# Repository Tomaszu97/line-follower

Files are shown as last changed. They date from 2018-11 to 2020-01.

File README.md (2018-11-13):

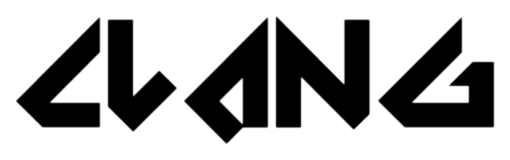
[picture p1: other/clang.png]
  
A simple line follower project of mine.
Consists of:
 * ATmega 328P  
 * L298 dual H-bridge  
 * 6x QRE1113GR optotransistors  
 * 2x pololu clone 12V 1200RPM motors  
 * step down 5V converter  
 * 7,4V Li-Ion battery  
 * couple resistors, LEDs and other passive components  

Programmed in Arduino.  
Uses PID loop and a simple algorithm to find center of line (using weighed average).  
Follows black line on white background.  

Video of device test  
IMAGE ALT TEXT HERE (https://www.youtube.com/watch?v=-RvJ9BSbzys) 

Before mounting DC motors:  
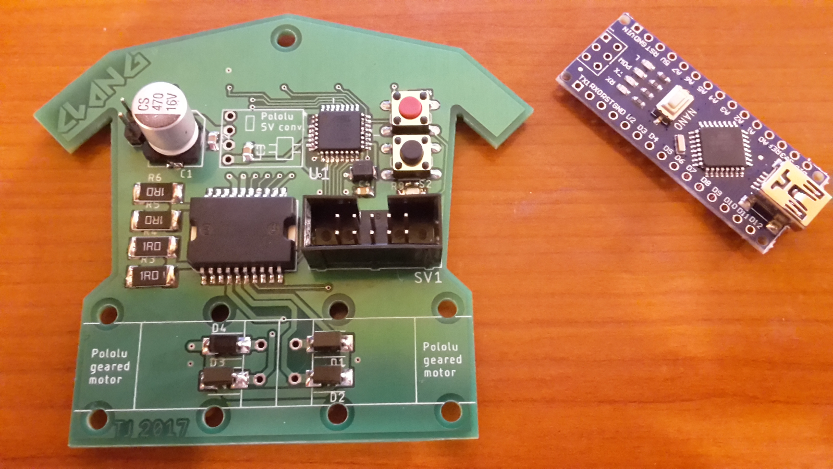
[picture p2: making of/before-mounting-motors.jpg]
  
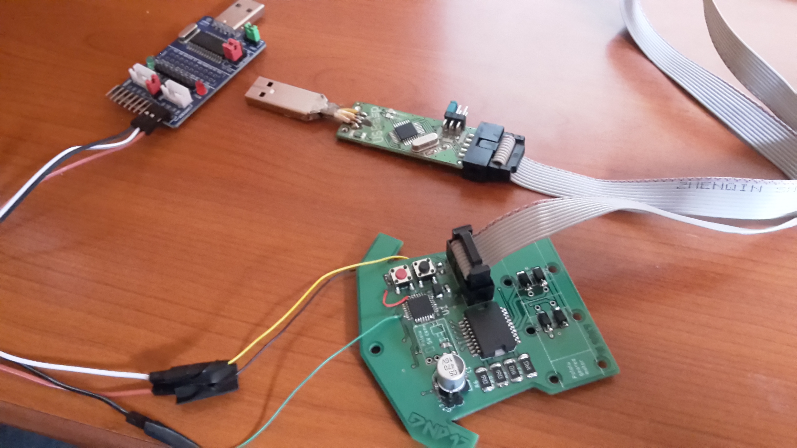
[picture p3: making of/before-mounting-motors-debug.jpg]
  

Finding voltage/speed characteristic using optical speed measurement:  
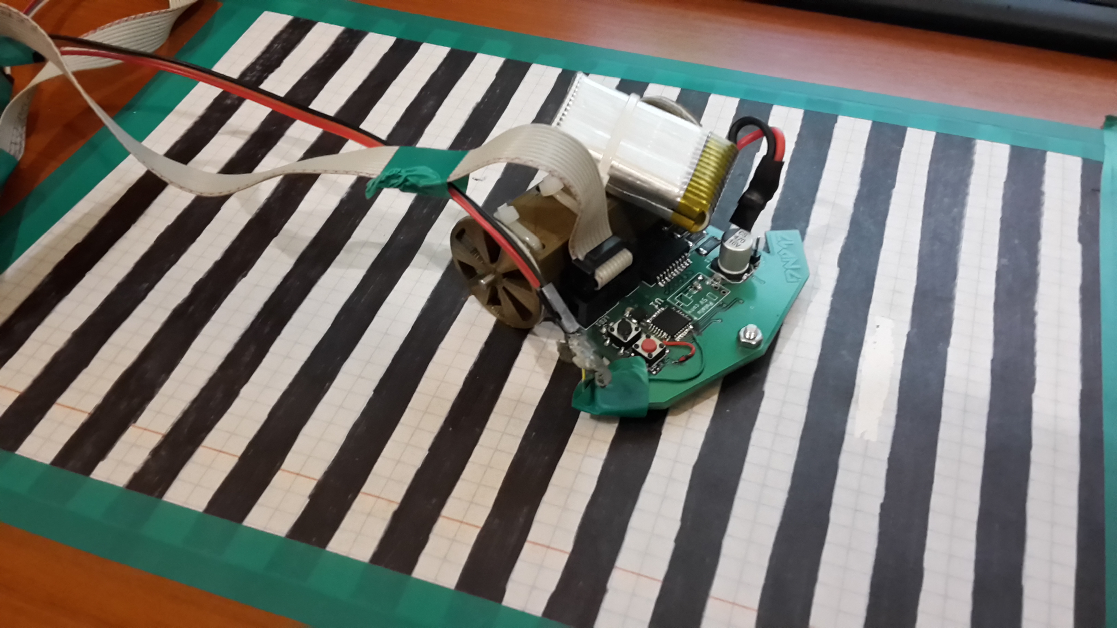
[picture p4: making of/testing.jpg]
  
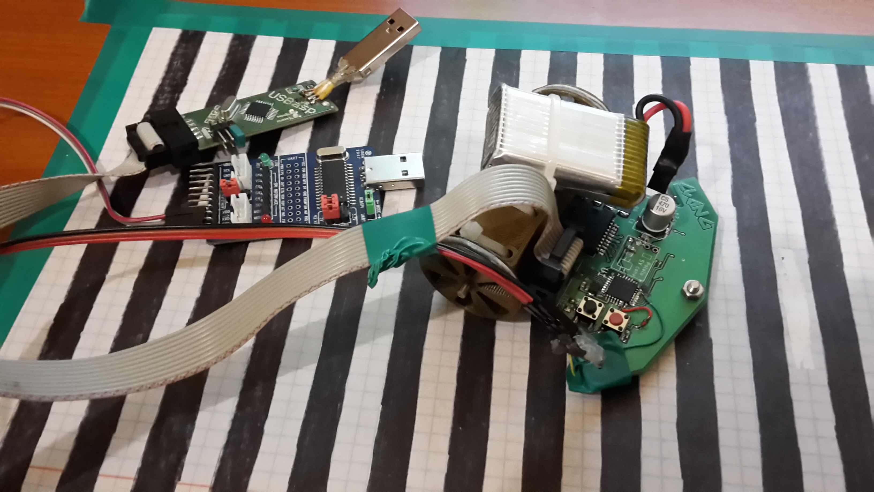
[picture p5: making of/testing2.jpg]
  
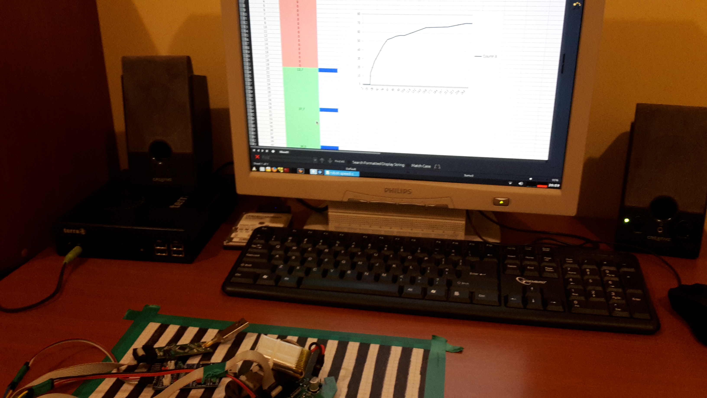
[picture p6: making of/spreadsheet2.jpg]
  
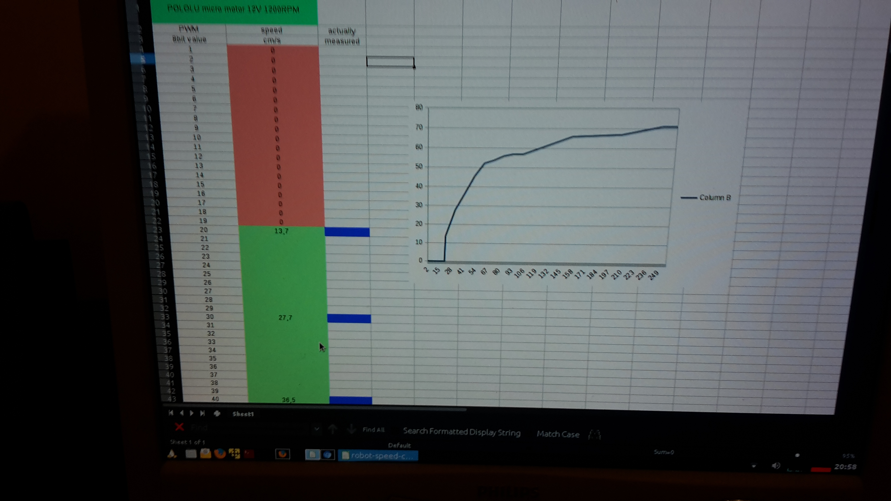
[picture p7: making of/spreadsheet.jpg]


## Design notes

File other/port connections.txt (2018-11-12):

PHOTOTRANSISTOR:
1	-	PC5	(ADC5)
2	-	PC4	(ADC4)
3	-	PC3	(ADC3)
4	-	PC2	(ADC2)
5	-	PC1	(ADC1)
6	-	PC0	(ADC0)

MOTORS:
input 1		-	PD7
input 2		-	PB0
input 3		-	PB1	
input 4		-	PB2
enable A	-	PD6
enable B	-	PD5

OTHER:
LED				-	PD0	(TXD)
BLACK BUTTON	-  	PD1	(RXD)

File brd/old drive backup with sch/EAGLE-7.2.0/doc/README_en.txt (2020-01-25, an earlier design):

==============================================

  E A G L E - L A Y O U T - S O F T W A R E
       Information about Version 7.2.0

==============================================

Updating from older versions
----------------------------

IMPORTANT: If you are updating from an older version of EAGLE, please make
*********  sure you read the file doc\UPDATE entirely before working
           with this new version!

Manual + Tutorial
-----------------

The EAGLE manual and tutorial in PDF format can be found in the "doc"
subdirectory. Please make sure you read at least the tutorial before
beginning to work with EAGLE.

Supported Operating Systems
---------------------------

  - Windows XP, Windows Vista, Windows 7 or Windows 8.

Running the CAM Processor in batch mode
---------------------------------------

Since Windows programs give up their connection to the console they
have been started from, you can use the file 'eaglecon.exe' (located
in the 'bin' subdirectory) if you want to run the CAM Processor from
a batch file. This version of EAGLE is exactly the same as the 'eagle.exe',
except that it doesn't disconnect from the console. Type 'eaglecon -?'
for a list of CAM Processor options.

Printing on custom paper sizes
------------------------------

Printing on custom paper sizes may not work, especially when switching
printers in the print dialog.

Octagon apertures in Gerber RS-274X format
------------------------------------------

The various Gerber viewers on the market have different ideas about how to
display octagon apertures in RS-274X format. There are all kinds of
interpretations of the diameter and rotation.
When generating octagon apertures in RS-274X format, EAGLE assumes that the
viewer will interpret the diameter as the distance between two opposite
corners, and that it has to be rotated by 22.5 degrees to achieve the
proper alignment. In case your specific viewer interprets these data
differently you can adjust this to your viewer's special needs in the file
'eagle.def'.

IMPORTANT: Before sending data in RS-274X format to your board house you
should make sure you ask them how *their* software will interpret octagon
data.

Printing fill patterns
----------------------

Printing fill patterns doesn't work with Postscript files.
If you want to print fill patterns, create a PDF file and then
print that file.

Electrical Schematics
---------------------

This EAGLE version is suited for drawing schematics and generating other
documentation for electrical projects, according to the European standard.
The descriptions of the specific libraries and user language programs,
as well as the tutorial covering this topic, are written in German.
At present, there are no plans to offer these features for the English-
speaking market. Feel free to use them, but there will be no support
in English.

Language
--------

EAGLE uses the same language as the operating system it is running on
(provided the necessary language specific text files are available).
To override this, you can set the environment variable LANG to the
desired value, as in

  SET LANG=de_DE     (under Windows)

before starting EAGLE.

                         ===================
========================= SALES INFORMATION ===============================
                         ===================

EAGLE is a program of CadSoft Computer GmbH.

CadSoft can be contacted in the USA at:
                         CadSoft Computer
                         19620 Pines Blvd. Suite 217
                         Pembroke Pines, FL 33029
                         Phone:  954-237-0932
                         Fax:    954-237-0968
                         E-Mail: info@cadsoftusa.com
                         Web:    http://www.cadsoftusa.com

EAGLE is available for Linux, Mac OS X and Windows platforms.

CadSoft Computer is a trading division of Newark Corporation, a Premier
Farnell company.
Learn more at http://www.cadsoftusa.com/pf.

===========================================================================
"Linux" is a registered trademark of Linus Torvalds.
"Mac", "Mac OS" and "Apple" are registered trademarks of Apple Computer, Inc.
"Windows" is a registered trademark of Microsoft Corporation.
===========================================================================

Copyright (c) 2014 CadSoft Computer - All rights reserved

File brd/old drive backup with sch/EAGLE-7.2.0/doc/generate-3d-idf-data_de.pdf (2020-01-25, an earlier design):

Seite 1 von 3

Ing. Neubacher Andreas
Entwicklung / Development

COMMEND INTERNATIONAL GMBH A-5020 Salzburg, Saalachstraße 51 Tel: +43-662-85 62 25
Fax: +43-662-43 18 22
<mailto: a.neubacher@commend.com> <http://www.commend.com>

Global Intercom by Commend

### Einpflegen 3D-Daten der Bauteile in Eagle-Bauteilbibliothek zur Weiterverarbeitung in 3D-MCAD Systemen

Um in die mechanische Konstruktion auch die Leiterplatte mit der Platinenkontur und den darauf platzierten Bauteilen einbinden zu können, müssen einige Punkte beim Erstellen eines neuen Bauteils berücksichtigt werden.

Techn. Hintergrund :

Um mechanische Abmessungen der Bauteile, Platine, … aus dem ECAD-System in ein MCAD-System zu portieren wurde 1989 ein Standard (IDF – Intermediate Data Format V1.0) von SDRC und Mentor definiert. Dieses Intermediate Data Format (IDF) wurde mit der Zeit überarbeitet/erweitert und besitzt derzeit den Letztstand V4.0. Die Generierung der IDF-Files wird derzeit von allen professionellen ECAD-Systemen (Mentor, Zuken, Target, PADS, PCAD, …) unterstützt.

Meilensteine des IDF-Standard :

- V1.0 : | # Board/Print-Outline, einfache Bauteilpositionierung
- V2.0 : | # Aufteilung der Daten in eine Bauteilbibliothek (.IDL) und ein Boardfile (.IDB) # Aufteilung aller elektromechanischen Daten in elektrische und mechanische Sektionen # Bauteildaten beinhalten nun 3D Informationen (nur 1 Höheninformation) # Placement-, Keepout-, …, Holessections
- V3.0 : | # Panelfile zur Erstellung eines bestückten Nutzen # div. Verbesserungen, …
- V4.0 : | # Bauteile können detailliert dargestellt werden (verschiedene Höheninfos, …) # Leiterbahnzüge, Freiformen, … können abgebildet werden

Standards zu finden unter : \\Eacoco\Projekte\_CAD_EAGLE\DOKU_eagle\

Solidworks 2006 SPx unterstützt derzeit nur den IDF-Standard Version 3.0. Dh alle Bauteile sind beschränkt auf 1 Höheninformation mit 1 geschlossenen Aussenkontur. Für eine genaue Konstruktion sind die Bauteildaten mit nur 1 Kontur und der maximalen Höhe vollkommen ausreichend.

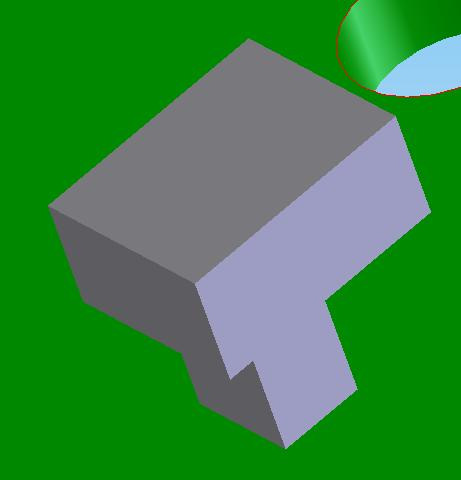
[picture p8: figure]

Seite 2 von 3

Erstellung der Eagle-Libary :

1) Bauteile :
- Ein Bauteil kann aus beliebig vielen Höheninformationen zusammengesetzt werden. Die verschiedenen Segmenthöhen können nur Pyramidenförmig aufgebaut werden. Dh: eine auf der Spitze stehende Pyramide kann nicht dargestellt werden.
Bsp: | möglich | nicht möglich

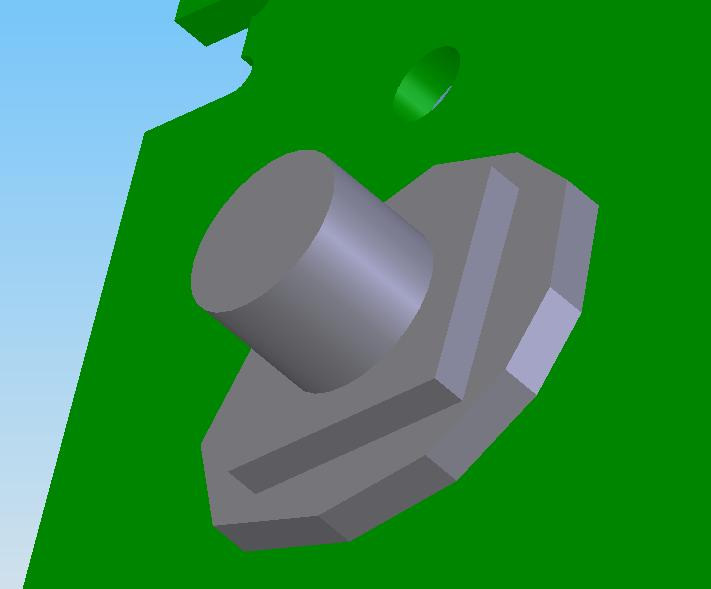
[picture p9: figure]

Graphik 1a | Graphik 1b
- Eine geschlossene Kontur jeder einzelnen Höheninfo ist UNBEDINGT notwendig um anschliessend diese extrudieren zu können
- Bauteilaussenkontur (R, L, C, IC, …) wird in der Bibliothek auf Layer 57 (tCAD) und Layer 58 (bCAD) angelegt

Layer 57 : Draufsicht auf das jeweilige Bauteil (standard)
Layer 58 : ragt durch die Platine ein Teil des Bauteils durch (mech. Befestigung o.Ä) wird dies im Layer58 eingetragen

Alle Bauteilhöhen werden normalerweise ausschliesslich auf Layer57 gezeichnet. Wenige Ausnahmen sind Stecker mit mech. Befestigung, Schrauben, Lötbeine bei bedrahteten Bauteilen, … die durch den Print ragen und auf der Bottom-Seite überstehen.

- Strichstärke der Kontur entspricht der Bauteilhöhe :
Bauteilhöhe Strichstärke = Bauteilhöhe [mm] / 1000 | (1mm = 1000mic)
(Bsp : Bauteilhöhe 12.6mm wird als Strichstärke | 12.6mic gezeichnet)

Notwendige Ausfräsungen, Löcher des Bauteils Strichstärke = 0.0 [mic]

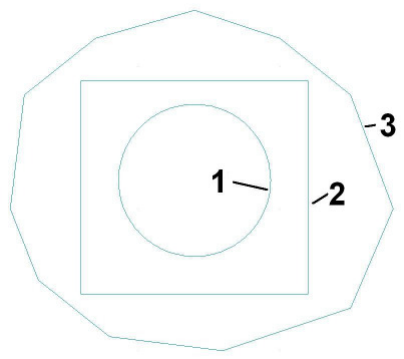
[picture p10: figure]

Bsp:

1) Strichstärke 8mic = Zylinder 8mm hoch
2) Strichstärke 3mic = Rechteck 3mm hoch
3) Strichstärke 1.6mic = Polygon 1.6mm

--> Ergebnis siehe Graphik 1a

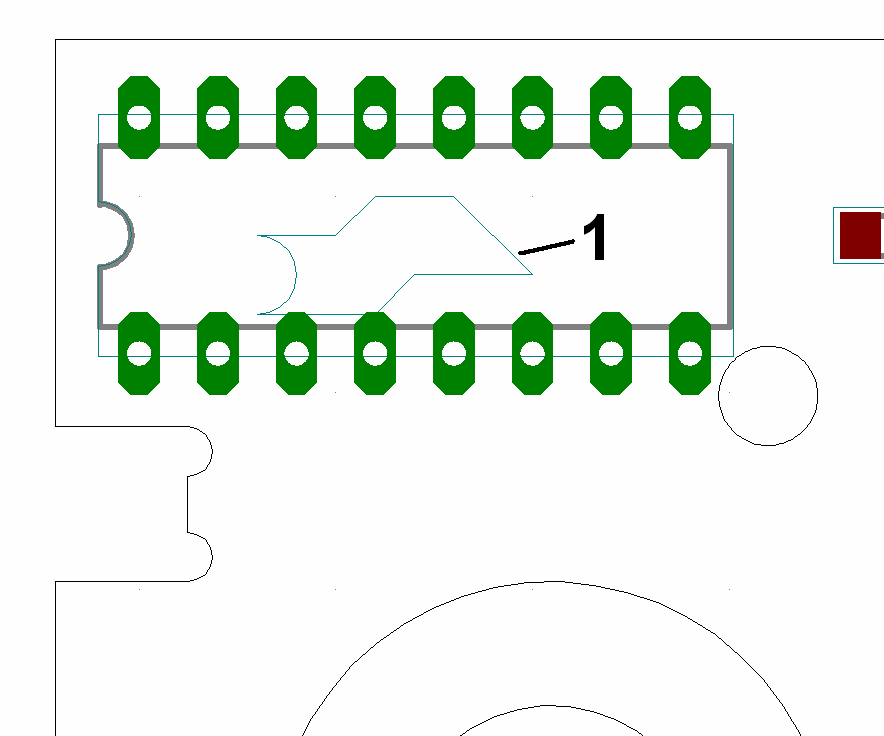
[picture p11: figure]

Seite 3 von 3

- Bohrungen/Holes müssen nicht gesondert behandelt werden -> werden automatisch erkannt und in die Leiterplatte übernommen
Bsp : | 1) | Stecker-Baueilhöhe 3.7mm -> Strichstärke = 3.7 [mic] Stecker-Ausfräsung für mech. Befestigung : Polygon mit 0.0 [mic] Stecker-Loch als Positionierungshilfe : Hole mit Durchmesser 2.1 [mm]
2) Ausfräsung unter IC (siehe Graphik 2c (1) )
Top-3D | Bottom-3D | Eagle-Bibliothek

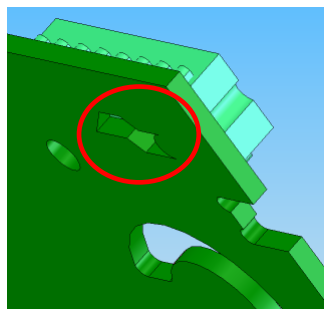
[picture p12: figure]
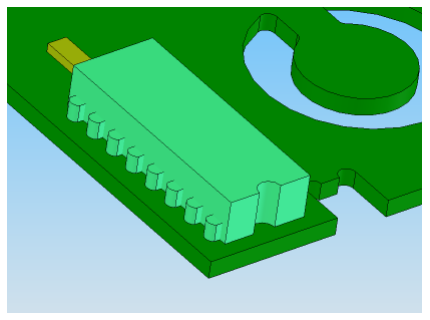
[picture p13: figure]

Graphik 2a | Graphik 2b | Graphik2c
2) Leere Leitplatte :
- Kontur der leeren Leiterplatte auf Layer 50
- Eine geschlossene Kontur ist UNBEDINGT notwendig um anschliessend diese extrudieren zu können
- Strichstärke der Aussenkontur entspricht der Leiterplattenhöhe

Platinenhöhe Strichstärke = Bauteilhöhe [mm] / 1000 (1mm = 1000mic) Notwendige Ausfräsungen, Löcher des Platine Strichstärke = 0.0 [mic]

Bsp : Strichstärke Leiterplatte Aussenkontur = 1.6 [mic], Printausfräsungen = 0.0 [mic]

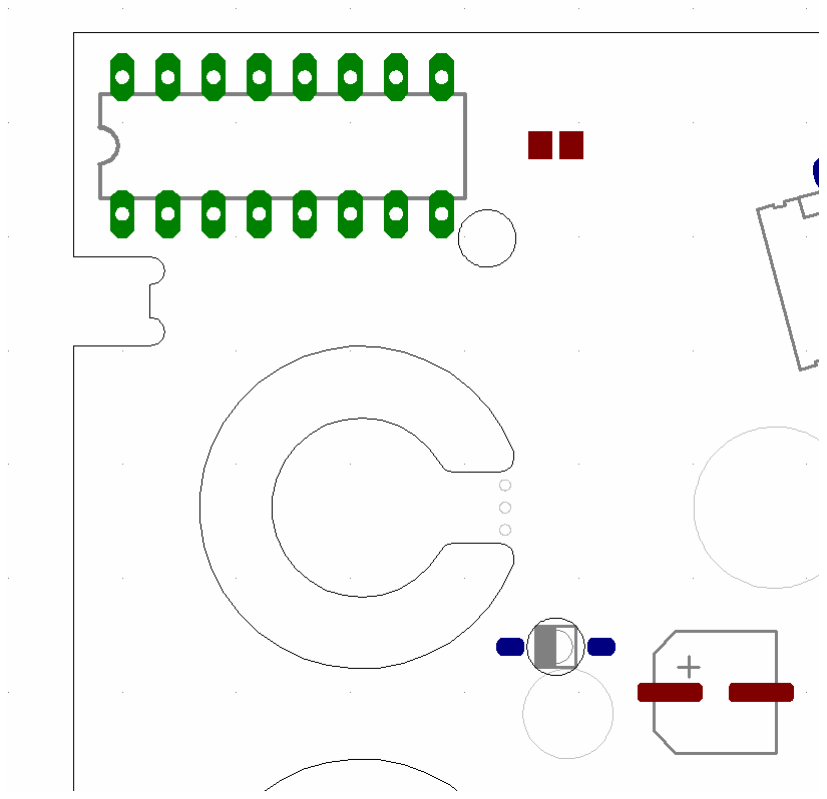
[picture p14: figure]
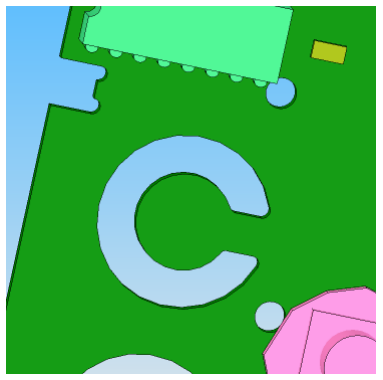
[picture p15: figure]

Graphik 3a | Graphik 3b

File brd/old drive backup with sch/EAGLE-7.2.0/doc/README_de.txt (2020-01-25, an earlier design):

==============================================

  E A G L E - L A Y O U T - S O F T W A R E
         Hinweise zur Version 7.2.0

==============================================

Update von einer früheren Version
---------------------------------

WICHTIG: Falls Sie von einer früheren EAGLE-Version updaten, lesen Sie
*******  bitte die Datei doc\UPDATE komplett durch bevor Sie beginnen
         mit dieser neuen Version zu arbeiten!

Handbuch + Tutorial
-------------------

Das EAGLE-Handbuch und -Tutorial im PDF-Format befindet sich im Verzeichnis
"doc". Bitte lesen Sie sich zumindest das Tutorial durch, bevor Sie mit
EAGLE zu arbeiten beginnen.

Unterstützte Betriebssysteme
----------------------------

  - Windows XP, Windows Vista, Windows 7 oder Windows 8

CAM-Prozessor in Stapelverarbeitungsdateien verwenden
-----------------------------------------------------

Da Windows-Programme ihre Verbindung zu der Konsole, von der sie
gestartet wurden, aufgeben, können Sie die Datei 'eaglecon.exe' (zu
finden im 'bin'-Verzeichnis) verwenden, wenn Sie den CAM-Prozessor aus
einer Stapelverarbeitungsdatei heraus starten wollen. Diese EAGLE-Version
entspricht genau der in 'eagle.exe', mit dem einzigen Unterschied, dass
sie die Verbindung zur startenden Konsole nicht aufgibt. Geben Sie
'eaglecon -?' ein um eine Liste der Optionen des CAM-Prozessors zu erhalten.

Ausdrucken auf benutzerdefinierten Papiergrößen
-----------------------------------------------

Das Ausdrucken auf benutzerdefinierten Papiergrößen funktioniert
unter Umständen nicht, insbesondere wenn der Drucker im Druckdialog
gewechselt wird.

Octagon-Blenden im Gerber RS-274X Format
----------------------------------------

Die verschiedenen auf dem Markt befindlichen Gerber-Viewer sind sich
nicht einig darüber, wie im RS-274X-Format Octagon-Blenden darzustellen
sind. Es gibt hier die unterschiedlichsten Auffassungen bezüglich der
Interpretation des Durchmessers und der Rotation.
EAGLE geht bei der Erzeugung von Octagon-Blenden im RS-274X-Format davon
aus, dass der Viewer den Durchmesser als den Abstand zweier
gegenüberliegender Eckpunkte interpretiert, und dass zur Erreichung der
korrekten Rotation eine Drehung um 22.5 Grad nötig ist. Sollte Ihr
spezieller Gerber-Viewer diese Daten anders interpretieren, so können Sie
dies in der Datei 'eagle.def' den speziellen Gegebenheiten Ihres Viewers
anpassen.

WICHTIG: Bevor Sie Daten im RS-274X-Format an Ihren Leiterplattenhersteller
schicken, sollten Sie sich unbedingt mit diesem in Verbindung setzen um zu
erfragen, wie *seine* Software die Octagon-Daten interpretiert.

Drucken von Füllmustern
-----------------------

Das Drucken von Füllmustern in Postscript-Dateien funktioniert nicht.
Wenn Sie Füllmuster ausgeben wollen, erzeugen Sie eine PDF-Datei
und drucken dann diese Datei aus.

Sprache
-------

EAGLE benutzt die selbe Sprache wie das Betriebssystem, auf dem es läuft
(vorausgesetzt, die entsprechenden sprachspezifischen Text-Dateien sind
vorhanden). Um dies zu überschreiben, können Sie die Umgebungsvariable
LANG auf den gewünschten Wert setzen, wie in

  SET LANG=en_US     (unter Windows)

bevor Sie EAGLE starten.

                         ===================
========================= VERTRIEBSHINWEISE ===============================
                         ===================

EAGLE ist ein Programm der: CadSoft Computer GmbH
                            Pleidolfweg 15
                            D-84568 Pleiskirchen
                            Tel.    08635/6989-10
                            Fax:    08635/6989-40
                            E-Mail: info@cadsoft.de
                            Web:    http://www.cadsoft.de

EAGLE ist verfügbar für Linux-, Mac OS X- und Windows-Rechner.

CadSoft Computer GmbH ist ein Unternehmen der Premier Farnell Gruppe.
Erfahren Sie mehr unter http://www.cadsoft.de/pf.

===========================================================================
"Linux" ist ein eingetragenes Warenzeichen von Linus Torvalds.
"Mac", "Mac OS" und "Apple" sind eingetragene Warenzeichen von Apple Computer, Inc.
"Windows" ist ein eingetragenes Warenzeichen der Microsoft Corporation.
===========================================================================

Copyright (c) 2014 CadSoft Computer GmbH - Alle Rechte vorbehalten

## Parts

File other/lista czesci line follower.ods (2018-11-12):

status | nazwa | obudowa | ilość potrzebna | ilość zamawiana | cena całkowita | cena wysyłki | link
 | goldpin męskie listwa |  | 1 | 0 | 0 | 0
 | przycisk omron | B3F-10XX | 2 | 0 | 0 | 0
 | kondensator 470uF | 0810 | 1 | 6 | 2,74 | 0 | https://www.aliexpress.com/item/6pcs-lot-16V-470uf-SMD-Aluminum-Electrolytic-Capacitors-size-8-10-5-470uf-16V/32838956982.html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
 | kondensator 100nF | 0805 | 3 | 100 | 4,04 |  | https://www.aliexpress.com/item/500pcs-100nF-X7R-Error-10-50V-0805-SMD-Thick-Film-Chip-Multilayer-Ceramic-Capacitor-free-shipping/32812155708.html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
 | dławik 10uH | 1210 | 1 | 50 | 12,68 |  | https://www.aliexpress.com/item/50pcs-lot-SMD-Inductor-1210-1UH-10UH-15UH-22UH-47UH-100UH-SMD-Chip-Inductors-Free-Shipping/32849482515.html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
 | LED | 1206 | 1 | 100 | 2,29 |  | https://www.aliexpress.com/item/100PCS-SMD-1206-Green-Led-1206-SMD-LED-Green-super-bright-1206-light-emitting-diodes-520/32676915682.html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\
 | rezystor 100R | 0402 | 7 | Duży Zestaw | 12,99 | 0 | https://pl.aliexpress.com/item/Free-Shipping-0402-SMD-Resistor-2000Pcs-Total-80Values-Each-25pcs-Resistor-Kit/853088495.html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
 | rezystor 100K | 0402 | 6
 | rezystor 470R | 0402 | 1
 | rezystor 1R | 2512 | 4 | 50 | 3,25 | 0 | https://pl.aliexpress.com/item/100PCS-2512-SMD-Resistor-5-1-ohm-1W-1R/32806716262.html
 | gniazdo programowania ISP | ML10 | 1 | 10 | 3,93 | 0 | https://pl.aliexpress.com/item/10PCS-LOT-DC3-10P-JTAG-ISP-socket-straight-IDC-Box-headers-connector-10Pins-2x5-2-54mm/32694095768.html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
 | Mostek H podwójny L298 | SO20POWER | 1 | 5 | 42,64 | 0 | https://pl.aliexpress.com/item/Free-Shipping-L298P-L298-STM-SOP20/32289662084.html
 | optotranzystor odbiciowy QRE1113GR | 4LEADSMD | 6 | 10 | 9,92 | 0 | https://pl.aliexpress.com/item/10pcs-lot-QRE1113GR-SMD-original-authentic/32645409236.html?rmStoreLevelAB=5
 | dioda schottky’ego | SMB | 8 | 100 | 4,62 | 0 | https://pl.aliexpress.com/item/Free-shipping-100pcs-lot-SCHOTTKY-DIODE-SS24-2A-40V-SMA-DO-214AC-SMD/32628687046.html
 | silnik pololu z przekladnia, 12V 1200RPM |  | 2 | 2 | 23,29 | 0 | https://www.aliexpress.com/item/1pc-N20-30-600-1000-1200RPM-DC3-6-12V-Micro-DC-Geared-Motor-Mayitr-Powerful-Metal/32815086283.html
 | ATMEGA328P-AU | QFP | 1 | 1 | 8,89 | 0 | https://pl.aliexpress.com/item/1pcs-original-ATMEGA328P-AU-ATMEGA328P-IC-MCU-8BIT-32KB-FLASH-32TQFP/32778339087.html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
 | Akumulator 7,4V |  | 1 | 2 | 38,13 | 0 | https://www.aliexpress.com/item/7-4V-500mAh-Lipo-Battery-For-Di-Fei-da-DFD-F182-F183-H8C-H8D-Quadrocopter-7/32720069202.html
 | regulator step-down pololu 5V |  | 1 | 1 | 19,9 | 10 | https://botland.com.pl/przetwornice-impulsowe/3110-przetwornica-step-down-d24v5f5-5v-05a.html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
 | płytka PCB |  | 1 | 1 | 113 | 20 | http://www.elpinpcb.com.pl/en/contact/
 | SUMA bez wysyłki: | 302,31
 | SUMA z kosztami wysyłki: | 332,31

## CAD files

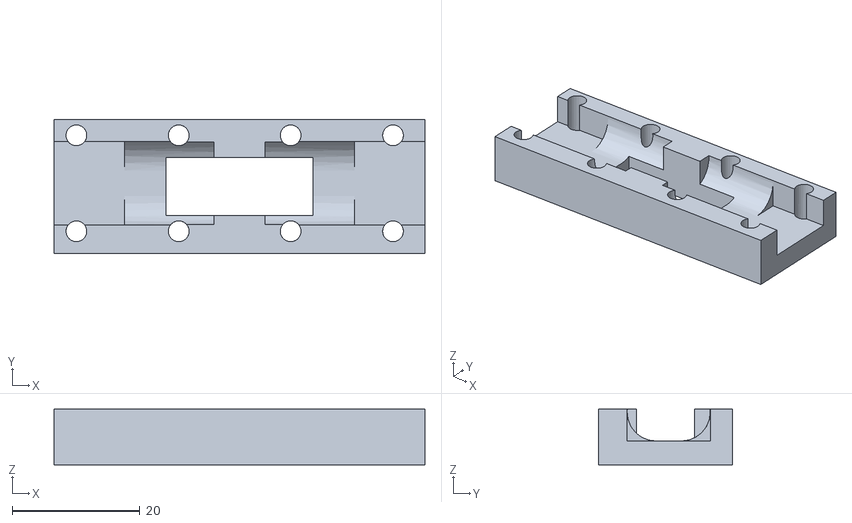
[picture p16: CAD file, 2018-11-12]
3d/line follower motor mount/line-follower-bottom-motor-mount.stl
58.0 x 21.0 x 8.75

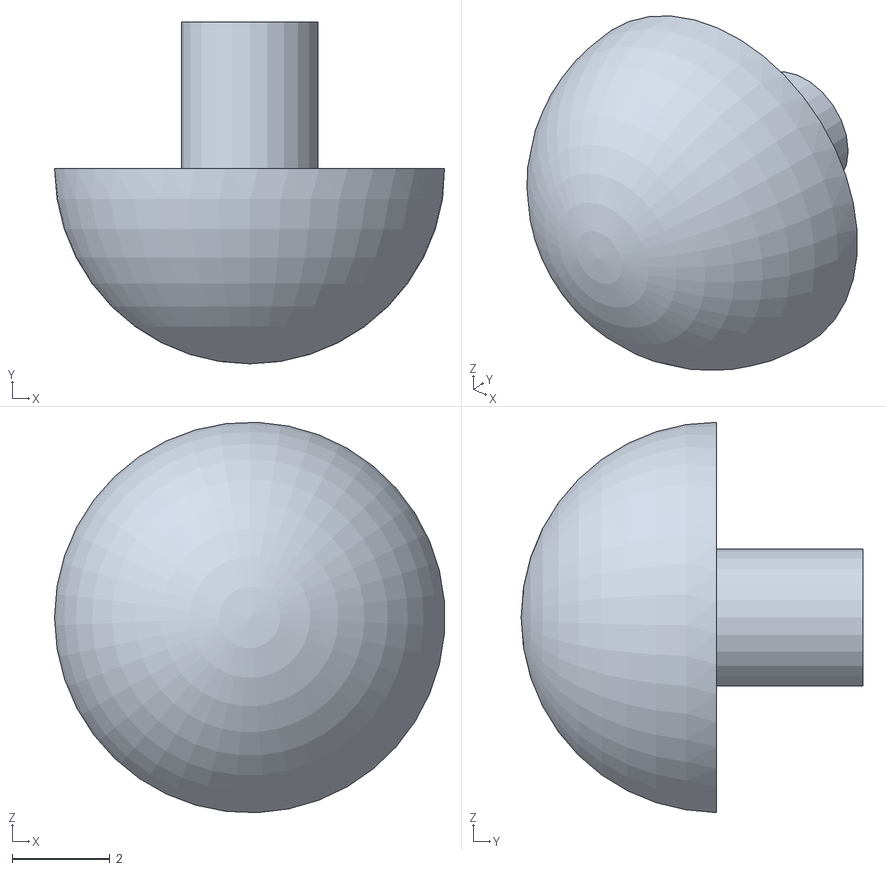
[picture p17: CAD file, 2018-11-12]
3d/line follower motor mount/line-follower-sliderl.stl
7.99 x 7.00 x 7.99

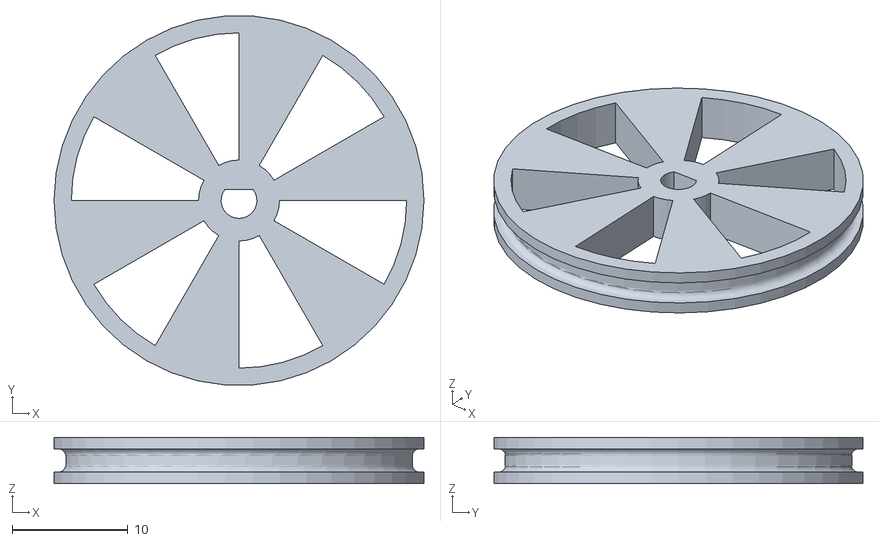
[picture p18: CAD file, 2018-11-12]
3d/line follower motor mount/line-follower-wheel.stl
32.0 x 31.9 x 4.00

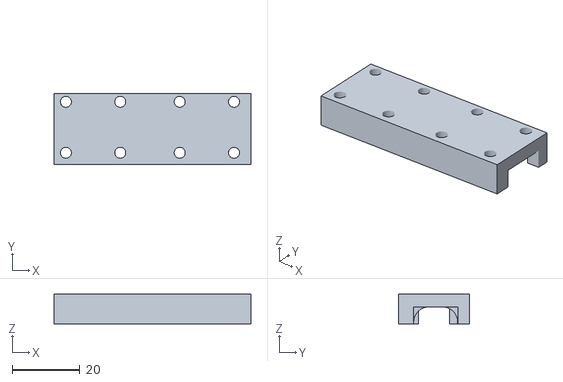
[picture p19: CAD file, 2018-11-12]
3d/line follower motor mount/line-follower-top-motor-mount.stl
58.0 x 21.0 x 8.75

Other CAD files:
3d/line follower motor mount/Assembly1.iam
3d/line follower motor mount/OldVersions/Assembly1.0002.iam
3d/line follower motor mount/OldVersions/Part1.0003.ipt
3d/line follower motor mount/Part1.ipt
3d/line follower motor mount/Part1_MIR.ipt
3d/line follower motor mount/Part2.ipt
3d/line follower motor mount/slider.ipt
3d/line follower motor mount/wheel.ipt

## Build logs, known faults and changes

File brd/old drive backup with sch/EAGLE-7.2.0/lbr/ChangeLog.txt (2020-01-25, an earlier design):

EAGLE Library ChangeLog
=======================

2014-10-28
  * display-lcd.lbr: Eagle 7.1.3
    corrected PADs: LCD-DIP128-64.PAC

2014-10-28
  * display-kingbright.lbr: Eagle 7.1.2
    corrected pad position:
    SA10-21.PAC
    SA18-11.PAC

2014-10-24
  * analog-devices.lbr: Eagle 7.1.2
    connected pac-variant R & RU: ADG413.DEV

2014-10-23
  * con-molex.lbr: Eagle 7.1.2
    added:
    0446200001.DEV
    0446200002.DEV
    0446200001.PAC
    0446200002.PAC

2014-10-23
  * on-semiconductor.lbr: Eagle 7.1.2
    added:
    SA571*.DEV

2014-10-23
  * con-lumberg.lbr: Eagle 7.1.2
    added:
    1613_14.DEV
    1613_14.PAC

2014-10-20
  * battery.lbr: Eagle 7.1.2
    added:
    BATTERY-HOLDER_11.6MM.DEV
    CH23-1220LF.DEV
    CH291-1220LF.DEV
    CELL_RETAINER_11.6MM.PAC
    CH23-1220LF.PAC
    CH291-1220LF.PAC

2014-10-17
  * led.lbr: Eagle 7.1.2
    added:
    LZ4-40U600.DEV
    LED3MM_H.PAC
    LED3MM_H7,5MM.PAC
    LED5MM_H6,0MM.PAC
    LZ4-40U600.PAC

2014-10-17
  * con-molex.lbr: Eagle 7.1.2
    corrected SMD koordinates pad 1 .. 15: 679105700.PAC

2014-10-15
  * micro-renesas.lbr: Eagle 7.1.2
    added:
    R5F10PBDYNA.DEV
    RL78/F13-20.DEV
    RL78/F13-30.DEV
    RL78/F13-32.DEV
    RL78/F13-48.DEV
    RL78/F13-64.DEV
    RL78/F13-80.DEV
    RL78/F14-30.DEV
    RL78/F14-32.DEV
    RL78/F14-48.DEV
    RL78/F14-64.DEV
    RL78/F14-80.DEV
    RL78/F14-100.DEV
    P-HVQFN32-5X5.PAC
    P-HVQFN48-7X7.PAC
    P-LFQFP48-7X7.PAC
    P-LFQFP64-10X10.PAC
    P-LFQFP80-12X12.PAC
    P-LFQFP100-14X14.PAC
    P-LSSOP30-6.1X9.7.PAC
    PP_SSOP20_7.62MM.PAC

2014-10-10
  * texas.lbr: Eagle 7.1.2
    added:
    ADS7042.DEV
    DCU_(R-PDSO-G8).PAC
    RUG_(R-PQFP-N8).PAC
    ADS8684.DEV
    ADS8688.DEV

2014-10-08
  * con-molex.lbr: Eagle 7.1.2
    added:
    VHDCI-68.DEV (73412-0110)
    VHDCI-68.PAC

2014-10-06
  * on-semiconductor.lbr: Eagle 7.1.2
    added:
    SA571.DEV
    DIL16.PAC
    SO16WB.PAC

2014-10-06
  * avago.lbr: Eagle 7.1.2
    added:
    HSMS-285B.DEV
    HSMS-285C.DEV
    HSMS-285E.DEV
    HSMS-285F.DEV
    HSMS-285K.DEV
    HSMS-285L.DEV
    HSMS-285P.DEV
    HSMS-285R.DEV
    HSMS-2850.DEV
    HSMS-2852.DEV
    HSMS-2853.DEV
    HSMS-2854.DEV
    HSMS-2855.DEV
    SOT23.PAC
    SOT143_AVAGO.PAC
    SOT323.PAC
    SOT363.PAC

2014-10-06
  * con-coax.lbr: Eagle 7.1.2
    added:
    734120110.DEV
    734120110.PAC

2014-10-01
  * cypress.lbr: Eagle 7.1.1
    added:
    CY8C58LPXXX.DEV
    CY8C58LPXXX_5JTAG.DEV
    CY8C58LPXXX_USB_4JTAG.DEV
    CY8C58LPXXX_USB_5JTAG.DEV
    TQFP100-14X14.PAC

2014-09-26
  * linear-technology.lbr: Eagle 7.1.1
    added:
    LT1634.DEV
    TO92.PAC.PAC

2014-09-24
  * linear-technology.lbr: Eagle 7.1.1
    added:
    LT1991.DEV

2014-09-23
  * rcl.lbr: Eagle 7.1.1
    delete wire on layer tKeepout: C01005.PAC

2014-09-19
  * con-amp.lbr: Eagle 7.1.1
    connection corrected: MTA06-100.DEV

2014-09-08
  * resistor.lbr: Eagle 7.1.1
    added - UPDATE : R-EU_.DEV, R-US_, C-EU.DEV, C-US.DEV,
    1812X7R.PAC
    C0201.PAC
    C01005.PAC
    C1808.PAC
    C3640.PAC
    HPC0201.PAC
    PRL1632.PAC
    R0201.PAC
    R01005.PAC
    R1218.PAC
    R4527.PAC
    VMTA55.PAC
    VMTB60.PAC
    VTA52.PAC
    VTA53.PAC
    VTA54.PAC
    VTA55.PAC
    VTA56.PAC
    WSC0001.PAC
    WSC01/2.PAC
    WSC0002.PAC
    WSC2515.PAC
    WSC4527.PAC
    WSC6927.PAC

2014-09-08
  * rcl.lbr: Eagle 7.1.1
    added:
    C01005.PAC
    PRL1632.PAC
    R01005.PAC
    deleted:
    C1005.PAC
    R1005.PAC

2014-08-28
  * resistor.lbr: Eagle 7.1.1
   delete R-TRIMM.DEV and copy new from rcl.lbr (corrected PAD names: TSM53YJ.PAC)

2014-08-07
  * texas.lbr: Eagle 7.0.1
    added:
    DM385.DEV
    DM385_DAVINCI.DEV
    AAR.PAC

2014-08-04
  * resistor.lbr: Eagle 6.6.0
    corrected description:
    BT/3528-21R.PAC
    T/3528-12R.PAC

2014-07-29
  * infineon.lbr: Eagle 6.6.0
    added:
    TLE5009.DEV
    PG-DSO-8.PAC

2014-07-21
  * IQD-Frequency-Products.lbr: Eagle 6.6.0
    added:
    CFPT-9006.DEV
    CRYSTALS-GND-LID.DEV
    CRYSTALS-NOGND.DEV
    E2747.DEV
    HC49.DEV
    OCXO.DEV
    OCXO-6-PIN.DEV
    OSC-OE.DEV
    SMD-OCXO.DEV
    TCXO.DEV
    TCXO-NO-VC.DEV
    2.0X1.2-2PAD.PAC
    2.0X1.6-4-PAD.PAC
    2.5X2-4-PAD.PAC
    2.6X2.1-4-PAD.PAC
    3.2X1.5-2-PAD.PAC
    3.4X2.7-4-PAD.PAC
    5.0X3.2-4-PAD.PAC
    5.0X3.2-TCXO.PAC
    5.2X3.4-4-PAD.PAC
    7.0X5.0-4-PAD.PAC
    7.0X5.0-10-PAD.PAC
    7.2X5.2-4-PAD.PAC
    7.5X5-2-PAD.PAC
    7.5X5-4-PAD.PAC
    85SMX.PAC
    86SMX.PAC
    90SMX.PAC
    91SMX.PAC
    C0-08-8.PAC
    CO-08-5.PAC
    CO-15-1.PAC
    CS-09-9.PAC
    HC49.PAC
    HC49-3L.PAC
    HC49-4-HSMX.PAC
    WATCH-3X8.PAC

2014-07-17
  * battery.lbr: Eagle 6.6.0
    added:
    10MM_SM_COIN_CELL_CLIP.DEV
    10MM_SM_COIN_CELL_CLIP.PAC

2014-07-14
  * microchip.lbr: Eagle 6.6.0
    added:
    PIC12F529T48A.DEV

2014-07-10
  * battery.lbr: Eagle 6.6.0
    added:
    BK-889.DEV
    BK-889.PAC

2014-07-10
  * roundsolutions.lbr: Eagle 6.6.0
    added:
    ANT-GXE474.DEV
    ANT-GXE474.PAC

2014-07-10
  * diode.lbr: Eagle 6.6.0
    added:
    BAT60J.DEV
    S1M.DEV
    SOD323_ST.PAC

2014-07-10
  * st-microelectronics.lbr: Eagle 6.6.0
    added:
    LD3985.DEV
    FLIP-CHIP-5.PAC
    SOT23-5L.PAC
    TSOT23-5L.PAC

2014-07-09
  * silabs.lbr: Eagle 6.6.0
    added:
    SI114*.DEV
    QFN-10.PAC

2014-07-03
  * dc-dc-converter.lbr: Eagle 6.6.0
    added:
    EMCO-HVDC_?*.DEV
    EMCO-HVDC_Q?*.DEV
    EMCO-A_100-2000V.PAC
    EMCO-A_3000-5000V.PAC
    EMCO-A_6000V.PAC
    EMCO-HVDC-Q_100-2000V.PAC
    EMCO-HVDC-Q_2500-5000V.PAC

2014-06-25
  * stm32xx.lbr: Eagle 6.6.0
    added:
    STM32L15*E.DEV
    LQFP100_14X14.PAC

2014-06-16
  * infineon.lbr: Eagle 6.6.0
    added:
    ILD4001.DEV
    SC74_INFINEON.PAC

2014-06-11
  * texas.lbr: Eagle 6.6.0
    added:
    LM3401.DEV
    TPS6306*.DEV
    DSC-S-PWSON-N10.PAC

2014-05-23
  * microphon.lbr: Eagle 6.5.4
    added:
    TOM-1545P-R.PAC

2014-05-23
  * transistor-power.lbr: Eagle 6.5.4
    added:
    BTS5215L.DEV
    FDS6890A.DEV
    M08A.PAC
    PG-DSO-12-9.PAC

2014-05-23
  * speaker.lbr: Eagle 6.5.4
    added:
    SMS-1308MS-2-R.DEV
    SMS-1308MS-2-R.PAC

2014-05-23
  * pinhead.lbr: Eagle 6.5.4
    added:
    PINHD-1X70.DEV
    PINHD-1X100.DEV
    1X70.PAC
    1X100.PAC
    1_05X2MM.PAC

2014-05-16
  * con-phoenix-3.81.lbr: Eagle 6.5.4
    added:
    1803497.DEV
    1803549.DEV
    1803497.PAC

2013-10-07
  * marks.lbr: Eagle 6.5.1
    deleted:
    PASSER-SMD
    added:
    PASSER-CIRCLE.PAC

2013-09-17
  * memory-micron.lbr: Eagle 6.5.1
    renamed devices:
    MT48LC16M16A2 > MT48LC64M4A2
    MT48LC64M4A2 > MT48LC16M16A2

2013-08-27
  * con-conrad.lbr: Eagle 6.5.1
    package extended: 736880-49.DEV

2013-08-27
  * dc-dc-converter.lbr: Eagle 6.5.1
    corrected pin connection: VA-*D01.DEV

2013-07-02
  * display-lcd.lbr: Eagle 6.4.4
    added:
    EA_DIP.DEV
    EA_DIP.PAC

2013-06-25
  * zetex.lbr: Eagle 6.4.3
    corrected device: PN_MOSFET-.DEV, N-Channel

2013-05-07
  * optocoupler.lbr: Eagle 6.4.2
    corrected web adress of data sheet: MOC30*.DEV

2013-05-06
  * atmel.lbr: Eagle 6.4.2
    deleted: Package variant M at ATMEGA644.DEV, false package dimension.
    The correct package used in ATMEGA644*.DEV variant M.

2013-05-06
  * st-microelectronics.lbr: Eagle 6.4.2
    added:
    LSM303DLHC.DEV
    LGA-14.PAC

2013-04-24
  * aplus.lbr: Eagle 6.4.2
    added:
    APR9600_DIP-28.DEV
    APR9600_SOP-28.DEV
    DIP254P1525X550-28P.PAC
    SOP50P1030X264-28N.PAC

2013-04-23
  * opto-vishay.lbr: Eagle 6.4.2
    added:
    TSSP6P38.DEV
    TSSP6P38.PAC

2013-04-09
  * maxim.lbr: Eagle 6.4.2
    corrected description of devices: TRANSEIVER to TRANSCEIVER

2013-02-22
  * transistor.lbr: Eagle 6.4.1
    description corrected:
    SOT89-ECB.PAC
    SOT89-BCE.PAC

2013-02-05
  * con-ptr500.lbr: Eagle 6.4.1
    corrected package: AK500/6-H.DEV => AK500/-6H.PAC

2013-01-25
  * atmel.lbr: Eagle 6.4.0
    added:
    MLF20-4X4.PAC
    AT90S2313.DEV package variant V (MLF)

2013-01-21
  * frames.lbr: Eagle 6.4.0
    text deleted in packages: "Sheet:" ">SHEET"

2012-12-17
  * rcl.lbr: Eagle 6.3.2
    corrected package outlines:
    RTRIM3296P.PAC
    RTRIM3296W.PAC
    RTRIM3296X.PAC
    RTRIM3296Y.PAC

2012-11-28
  * relay.lbr: Eagle 6.3.2
    package contour corrected: DIL06.PAC

2012-11-28
  * zetex.lbr: Eagle 6.3.2
    changed symbols and corrected connection: *.DEV

2012-11-20
  * jumper.lbr: Eagle 6.3.1
    corrected pad coordinates: JP2Q.PAC

2012-11-12
  * con-coax.lbr: Eagle 6.3.1
    changed all devices with new connect option, multipin any/all: *.DEV

2012-11-08
  * e-schuetze-relais.lbr: Eagle 6.3.1
    corrected pad names:
    RELAIS_2-POL-UM.DEV
    RELAIS_4-POL-UM.DEV

2012-11-05
  * logo.lbr: Eagle 6.3.1
    added:
    CE-4MM.PAC
    C_TICK.PAC
    FCC_6.1X15MM.PAC
    FCC_10X4.175MM.PAC
    FCC_20X8.35MM.PAC

2012-11-05
  * inductors.lbr: Eagle 6.3.1
    renamed: BML15H.DEV to BLM15H.DEV

2012-10-30
  * eagle-ltspice.lbr: Eagle 6.3.1
    added: for beta version ltspice.ulp
    C.DEV
    DIODE_E-.DEV
    L.DEV
    LED_E.DEV
    R.DEV
    SCHOTTKY-DIODE.DEV

2012-10-01
  * texas.lbr: Eagle 6.2.3
    added:
    TLC4501.DEV
    TLC4502.DEV

2012-09-03
  * dc-dc-converter.lbr: Eagle 6.2.2
    added:
    R-78C*-1.0.DEV
    SIP3.PAC

2012-09-03
  * con-lumberg.lbr: Eagle 6.2.2
    corrected pads: KLBR4.PAC

2012-08-29
  * switch.lbr: Eagle 6.2.3
    added:
    3PDT.DEV
    3PDT.PAC

2012-08-28
  * relay.lbr: Eagle 6.2.2
    added:
    APF30212A.DEV
    APF30212C.DEV
    APF30212A.PAC
    APF30212C.PAC

2012-08-21
  * relay.lbr: Eagle 6.2.2
    corrected Set/Reset coil: DS2E-L-*.DEV

2012-08-10
  * switch-alps.lbr: Eagle 6.2.2
    corrected symbol coordinate: EC12E_SW.DEV

2012-08-09
  * allegro.lbr: Eagle 6.2.2
    Pads extended for Version 6:
    ACS75050.PAC
    CB-PFF.PAC
    ACS758*.DEV
    ACS750*CA-050.DEV

2012-07-09
  * 19inch.lbr: Eagle 6.2.2
    corrected package variant : VG96P -> VG64P

2012-07-09
  * ftdichip.lbr: Eagle 6.2.2
    added:
    FT230X.DEV
    QFN16.PAC
    SSOP16.PAC

2012-07-04
  * st-microelectronics.lbr: Eagle 6.2.2
    added:
    STGIPS10K60A.DEV
    SDIP-25L.PAC

2012-06-13
  * relay.lbr: Eagle 6.2.1
    added:
    JV*-KT.DEV
    JV-KT.PAC

2012-06-06
  * intersil-techwell.lbr: Eagle 6.2.1
    added:
    TW9920.DEV
    VFBGA100L-8X8.PAC

2012-06-05
  * relay.lbr: Eagle 6.2.1
    added:
    JW1A.DEV
    JW1C.DEV
    JW2A.DEV
    JW2C.DEV
    JW1A.PAC
    JW1C.PAC
    JW2A.PAC
    JW2C.PAC

2012-06-05
  * texas-sn55-sn75.lbr: Eagle 6.2.1
    added:
    SN75451B.DEV
    SN75452B.DEV
    SN75453B.DEV
    SN75454B.DEV
    DIL08.PAC
    D_R-PDSO-G8.PAC
    PS_R-PDSO-G8.PAC

2012-06-01
  * transistor-power.lbr: Eagle 6.2.1
    added:
    IRF8313P.DEV

2012-05-09
  * con-subd.lbr: Eagle 6.2.1
    added:
    M09SMT.PAC
    M15SMT.PAC
    M25SMT.PAC
    M37SMT.PAC

2012-04-25
  * philips-semiconductors.lbr: Eagle 6.2.1
    added:
    TDA1552Q.DEV
    MULTIWAT-SIL13.PAC

2012-04-19
  * trafo-hammondmfg.lbr: Eagle 6.2.0
    added:
    166.DEV
    C0H.PAC
    C1H.PAC
    C2H.PAC
    C3H.PAC
    C4H.PAC
    C5H.PAC
    C6H.PAC
    C7H.PAC
    C8H.PAC
    C9H.PAC
    C10H.PAC
    C11H.PAC
    C12H.PAC
    C13H.PAC
    C14H.PAC
    C15H.PAC
    C16H.PAC

2012-04-19
  * con-phoenix-350.lbr: Eagle 6.2.0
    added:
    MKKDS1/2-3,5.DEV
    MKKDS1/3-3,5.DEV
    MKKDS1/4-3,5.DEV
    MKKDS1/5-3,5.DEV
    MKKDS1/6-3,5.DEV
    MKKDS1/7-3,5.DEV
    MKKDS1/8-3,5.DEV
    MKKDS1/9-3,5.DEV
    MKKDS1/10-3,5.DEV
    MKKDS1/11-3,5.DEV
    MKKDS1/12-3,5.DEV
    MKKDS1/13-3,5.DEV
    MKKDS1/14-3,5.DEV
    MKKDS1/15-3,5.DEV
    MKKDS1/16-3,5.DEV
    MKKDS1/2-3,5.PAC
    MKKDS1/3-3,5.PAC
    MKKDS1/4-3,5.PAC
    MKKDS1/5-3,5.PAC
    MKKDS1/6-3,5.PAC
    MKKDS1/7-3,5.PAC
    MKKDS1/8-3,5.PAC
    MKKDS1/9-3,5.PAC
    MKKDS1/10-3,5.PAC
    MKKDS1/11-3,5.PAC
    MKKDS1/12-3,5.PAC
    MKKDS1/13-3,5.PAC
    MKKDS1/14-3,5.PAC
    MKKDS1/15-3,5.PAC
    MKKDS1/16-3,5.PAC

2012-04-18
  * microwave.lbr: Eagle 6.2.0
    added:
    HMC641LC4.DEV

2012-04-18
  * con-omron.lbr: Eagle 6.2.0
    added:
    XF3B-0845-31A.DEV
    XF3B-1945-31A.DEV
    XF3B-2545-31A.DEV
    XF3B-3545-31A.DEV
    XF3B-5145-31A.DEV
    XF3B-6745-31A.DEV
    XF3B-8.PAC
    XF3B-19.PAC
    XF3B-25.PAC
    XF3B-35.PAC
    XF3B-51.PAC
    XF3B-67.PAC

2012-04-16
  * lem.lbr: Eagle 6.2.0
    added:
    LA-*.DEV
    LA25P.PAC

2012-04-11
  * maxim.lbr: Eagle 6.1.5
    added:
    MAX8559.DEV
    TDFN8-3X3MM.PAC

2012-04-11
  * transistor-power.lbr: Eagle 6.1.5
    added:
    BSZ105N04NS.DEV

2012-04-04
  * cirrus-logic.lbr: Eagle 6.1.5
    added:
    CD161*-FSZ.DEV
    SOIC16.PAC

2012-04-02
  * con-amp-te.lbr: Eagle 6.1.5
    added:
    5749069-1.DEV
    5749069-2.DEV
    5749069-4.DEV
    5749069-5.DEV
    5749069-7.DEV
    5749069-8.DEV
    5749069-9.DEV
    5749069-1.PAC
    5749069-2.PAC
    5749069-4.PAC
    5749069-5.PAC
    5749069-7.PAC
    5749069-8.PAC
    5749069-9.PAC

2012-03-28
  * led.lbr: Eagle 6.1.5
    delete HOLE: NFSG036BT.PAC

2012-03-21
  * linear-technology.lbr: Eagle 6.1.4
    added:
    LTC2444.DEV
    LTC2445.DEV
    LTC2448.DEV
    LTC2449.DEV
    QFN38-5X7.PAC

2012-03-19
  * transistor.lbr: Eagle 6.1.3
    corrected technologie/package variant TO92-EBC of *-NPN-.PAC / *-PNP.PAC:
    MPSA04
    MPSA13
    MPSA14
    MPSA18
    MPSA28
    MPSA29
    MPSA42
    MPSA44
    MPSA92
    MPSA92

2012-03-16
  * optocoupler.lbr: Eagle 6.1.3
    added:
    PLT133/T9.DEV
    PLT133/T9.PAC

2012-03-16
  * con-amphenol.lbr: Eagle 6.1.3
    added:
    RCA-4-117-01.DEV
    RCA-4-117-01.PAC

2012-03-16
  * con-conrad.lbr: Eagle 6.1.3
    added:
    RCA-4-117-01.DEV
    RCA-4-117-01.PAC

2012-03-16
  * con-lumberg.lbr: Eagle 6.1.3
    added:
    RC-5231.DEV
    RC-5231.PAC

2012-03-15
  * transformer-pulse.lbr: Eagle 6.1.3
    added:
    PE-65612.DEV
    PE-65612.PAC

2012-03-14
  * micro-philips.lbr: Eagle 6.1.3
    added:
    LPC1102.DEV
    WLCSP16.PAC

2012-03-12
  * holes.lbr: Eagle 6.1.3
    deleted: circle and wire in layer t/bRestrict of PAD-packages

2012-03-12
  * texas.lbr: Eagle 6.1.3
    corrected: set device value on.
    BQ20*
    TLV*
    UC1*

2012-02-23
  * allegro.lbr: Eagle 6.1.3
    added:
    A3946.DEV
    TSSOP16E.PAC

2012-02-16
  * relay.lbr: Eagle 6.1.2
    added:
    FTR-B4.DEV
    FTR-B4C.PAC
    FTR-B4G.PAC
    FTR-B4S.PAC

2012-02-07
  * 74xx-little-de.lbr: Eagle 6.1.2
    added: 74*1G79.DEV finished

2012-01-25
  * relay.lbr: Eagle 6.1.1
    pad coordinate corrected:
    SF2D.PAC
    SF4D.PAC

2012-01-17
  * optocoupler.lbr: Eagle 6.1.0
    package corrected in Variant:
    SFH6186-2
    SFH6186-3
    SFH6186-4
    SFH6186-5

2012-01-17
  * avago.lbr: Eagle 6.1.0
    added:
    HCNR20*.DEV
    DIL08-400.PAC
    DIP8-400.PAC

2012-01-11
  * transistor.lbr: Eagle 6.0.2
    removed:
    *-NPN-2C-.DEV
    *-PNP-2C-.DEV
    PNP2.SYM

2011-12-28
  * microchip.lbr: Eagle 6.0.2
    added:
    PIC16*F1516/18.DEV
    PIC16*F1517/19.DEV
    UQFN28_4X4MM.PAC
    UQFN40ML5X5MM.PAC
    PIC16*F1826/27.DEV

2011-12-28
  * plcc-socket.lbr: Eagle 6.0.2
    added:
    PLCC86_635.PAC
    W9322.PAC
    W9323.PAC
    W9324.PAC
    W9325.PAC
    W9326.PAC
    W9327.PAC
    W9328.PAC

2011-12-27
  * con-harting.lbr: Eagle 6.0.2
    added:
    60010685132.PAC
    60010685232.PAC

2011-12-20
  * micro-philips.lbr: Eagle 6.0.1
    corrected package: HVQFN28.PAC

2011-12-19
  * con-garry.lbr: Eagle 6.0.1
    added:
    332-02.DEV
    332-04.DEV
    332-06.DEV
    332-08.DEV
    332-10.DEV
    332-12.DEV
    332-14.DEV
    332-16.DEV
    332-18.DEV
    332-20.DEV
    332-22.DEV
    332-24.DEV
    332-26.DEV
    332-28.DEV
    332-30.DEV
    332-32.DEV
    332-34.DEV
    332-36.DEV
    332-38.DEV
    332-42.DEV
    332-44.DEV
    332-46.DEV
    332-48.DEV
    332-50.DEV
    332-02.PAC
    332-04.PAC
    332-06.PAC
    332-08.PAC
    332-10.PAC
    332-12.PAC
    332-14.PAC
    332-16.PAC
    332-18.PAC
    332-20.PAC
    332-22.PAC
    332-24.PAC
    332-26.PAC
    332-28.PAC
    332-30.PAC
    332-32.PAC
    332-34.PAC
    332-36.PAC
    332-38.PAC
    332-42.PAC
    332-44.PAC
    332-46.PAC
    332-48.PAC
    332-50.PAC

2011-12-15
  * con-tyco.lbr: Eagle 6.0.1
    added:
    D1200D-4.DEV
    D1200D-6.DEV
    D1200D-8.DEV
    D1200D-10.DEV
    D1200D-12.DEV
    D1200D-16.DEV
    D1200D-20.DEV
    D1200D-4.PAC
    D1200D-6.PAC
    D1200D-8.PAC
    D1200D-10.PAC
    D1200D-12.PAC
    D1200D-16.PAC
    D1200D-20.PAC

2011-12-05
  * diode.lbr: Eagle 5.91.5
    changed: all devices and symbols with multi connection pins and extended pattern

2011-12-01
  * quantum-research-group.lbr: Eagle 5.91.4
    packages with extended pad:
    ROTOR-QUANTUM-20MM.PAC
    ROTOR_E1106_40MM.PAC

2011-12-01
  * lumiled.lbr: Eagle 5.91.4
    changed: all devices and symbols with multi connection pins

2011-12-01
  * led.lbr: Eagle 5.91.4
    changed: all devices and symbols with multi connection pins

2011-11-25
  * con-faston.lbr: Eagle 5.91.2
    changed: all devices and symbols with multi connection pins

2011-11-25
  * led-lumiled.lbr: Eagle 5.91.2
    changed: all devices and symbols with multi connection pins

2011-11-25
  * con-pulse.lbr: Eagle 5.91.2
    moved text >NAME in JP011.SYM on (-500 -2300) mil

2011-11-25
  * con-molex.lbr: Eagle 5.91.2
    changed: pin name in symbol AGND.SYM from A-GND@1 to AGND

2011-11-25
  * con-hirschmann.lbr: Eagle 5.91.2
    changed: all devices and symbols with multi connection pins

2011-11-25
  * chipcard-siemens.lbr: Eagle 5.91.2
    changed: all devices and symbols with multi connection pins

2011-11-23
  * transistor-small-signal.lbr: Eagle 5.91.2
    changed: all devices and symbols with multi connection pins

2011-11-23
  * transistor-power.lbr: Eagle 5.91.2
    changed: all devices and symbols with multi connection pins

2011-11-23
  * transistor-pnp.lbr: Eagle 5.91.2
    changed: all devices and symbols with multi connection pins

2011-11-23
  * transistor-npn.lbr: Eagle 5.91.2
     changed: all devices and symbols with multi connection pins

2011-11-22
  * transistor-fet.lbr: Eagle 5.91.2
    changed: all devices and symbols with multi connection pins

2011-11-22
  * transistor.lbr: Eagle 5.91.2
    changed: all devices and symbols with multi connection pins

2011-11-16
  * transistor-fet.lbr: Eagle 5.91.1
    added:
    2N4416.DEV

2011-11-16
  * transistor.lbr: Eagle 5.91.1
    deleted: 2N4416.DEV

2011-11-10
  * texas.lbr: Eagle 5.91.1
    added:
    TPS62120.DEV
    DCN-R-PDSO-G8.PAC
    BQ24022.DEV
    changed package (pad extension): DRC-S-PVSON-N10.PAC

2011-11-02
  * microchip.lbr: Eagle 5.11.2
    renamed: TQFP100.PAC to TQFP100-14X14.PAC
    added:
    DSPIC33FJ256GP710.DEV
    TQFP100-12X12.PAC

2011-11-02
  * trimble.lbr: Eagle 5.11.2
    added:
    A1919_AARDVARK.DEV
    B1919_BUFFALO.DEV
    C1011_CONDOR.DEV
    C1216_CONDOR.DEV
    C1722_CONDOR.DEV
    C1919A_CONDOR.DEV
    C1919B_CONDOR.DEV
    C1919C_CONDOR.DEV

2011-10-21
  * atmel.lbr: Eagle 5.11.2
    corrected pin direction: 250X0.SYM

2011-10-06
  * switch-reed.lbr: Eagle 5.11.2
    added:
    REED-SWITCH-NO-NC.DEV
    REED-SWITCH-.DEV
    CT10-A2.PAC
    CT10-G1.PAC
    CT10-G4.PAC
    MK6-4.PAC
    MK6-5.PAC
    MK6-6.PAC
    MK6-7.PAC
    MK6-8-A.PAC
    MK6-8-C.PAC
    MK6-10.PAC
    MK15.PAC

2011-10-05
  * transistor-power.lbr: Eagle 5.11.2
    added:
    BSC340N08NS3G.DEV
    PG-TDSON-8.PAC

2011-10-04
  * linear.lbr: Eagle 5.11.2
    corrected connection: TL331.DEV

2011-09-30
  * led.lbr: Eagle 5.11.2
    added:
    ML-E.DEV
    ML-E.PAC

2011-09-30
  * transistor-fet.lbr: Eagle 5.11.2
    corrected: FDD4141.DEV connection Drain, Source

2011-09-28
  * texas.lbr: Eagle 5.11.2
    added:
    SWRA092B.DEV
    SWRA092B.PAC

2011-09-28
  * inductors.lbr: Eagle 5.11.2
    added:
    BML15H.DEV
    0402.PAC

2011-09-28
  * crystal.lbr: Eagle 5.11.2
    added:
    FA-.DEV
    FC-12M.DEV
    FA-20H.PAC
    FA-128.PAC
    FC-12M.PAC

2011-09-27
  * lem.lbr: Eagle 5.11.2
    added:
    LA-100P.DEV
    LA100P.PAC

2011-09-27
  * johanson-technology.lbr: Eagle 5.11.2
    added:
    2450BM15A0002.DEV
    2450BM15A0002.PAC

2011-09-26
  * linear.lbr: Eagle 5.11.2
    added: LM2902.DEV Variant PT
    SSOP14.PAC

2011-09-26
  * con-amp.lbr: Eagle 5.11.2
    added:
    966140-5F.DEV
    966140-5F.PAC

2011-09-23
  * con-lumberg.lbr: Eagle 5.11.2
    corrected pad 1 and 3 (swaped): 1503_02.PAC

2011-09-20
  * texas.lbr: Eagle 5.11.2
    added:
    CC2540.DEV

2011-09-16
  * belton-engineering.lbr: Eagle 5.11.2
    added:
    VT9.DEV
    VT9-PT.PAC
    VT9-PT-C.PAC

2011-09-15
  * led.lbr: Eagle 5.11.2
    added:
    SPHWHTHAD605S0W0U4.DEV
    SPHWHTHAD605S0W0U4.PAC

2011-09-15
  * national-semiconductor.lbr: Eagle 5.11.2
    added:
    LM13600.DEV
    DIL16.PAC
    SO16.PAC
    SO16DW.PAC

2011-09-15
  * mitsubishi-semiconductor.lbr: Eagle 5.11.2
    added:
    M5218.DEV
    SOP8.PAC

2011-09-15
  * toshiba.lbr: Eagle 5.11.2
    added:
    TA7136AP.DEV
    SIP7-P-2.54.PAC

2011-09-08
  * traco-electronic.lbr: Eagle 5.11.2
    added:
    TES3.DEV
    TES3-.DEV
    TES3.PAC

2011-09-01
  * national-semiconductor.lbr: Eagle 5.11.1
    added:
    LM391.DEV
    DIL18.PAC
    PLCC20S.PAC

2011-09-01
  * st-microelectronics.lbr: Eagle 5.11.1
    added:
    L5973D.DEV
    HSOP8.PAC

2011-08-22
  * con-lumberg.lbr: Eagle 5.11.1
    corrected pad and hole position: 1501_06.PAC

2011-06-15
  * e-schuetze-relais.lbr: Eagle 5.11.1
    added:
    RELAIS_2-POL-UM.DEV
    RELAIS_4-POL-UM.DEV
    RELAIS_2-POL-UM.PAC
    RELAIS_4-POL-UM.PAC

2011-06-10
  * cirrus-logic.lbr: Eagle 5.11.1
    corrected library description: Digital Audio Receiver

2011-06-08
  * allegro.lbr: Eagle 5.11.1
    added:
    A3906.DEV
    QFN20.PAC

2011-06-01
  * e-schalter.lbr: Eagle 5.11.1
    added:
    LASTTRENNSCHALTER_4-POL.DEV
    LEISTUNGSSCHALTER_4-POL.DEV
    LASTTRENNSCHALTER_4-POL.PAC
    LEISTUNGSSCHALTER_4-POL.PAC

2011-05-31
  * inductor-nkl.lbr: Eagle 5.11.1
    renamed packages:
    B5�.PAC to B5O.PAC
    B6�-PAC to B6O.PAC

2011-05-26
  * texas.lbr: Eagle 5.11.1
    added:
    TMS320C5515.DEV
    UC*84.DEV
    UC*84?.DEV
    ZCH(S-PBGA-N196).PAC

2011-05-13
  * con-phoenix-500.lbr: Eagle 5.11.1
    corrected grid of all packages 5.08mm

2011-05-11
  * crystal.lbr: Eagle 5.11.1
    added:
    RV-3029-C2.DEV
    2450BL15B100.PAC
    SON-10.PAC

2011-05-04
  * diode.lbr: Eagle 5.11.1
    connection corrected: BAT54S.DEV

2011-05-04
  * microchip.lbr: Eagle 5.11.1
    added:
    PIC18F2*J53.DEV
    PIC18F4*J53ML.DEV
    PIC18F47J53PT.DEV

2011-05-02
  * wuerth-elektronik.lbr: Eagle 5.11.1
    deleted: please use actual library from www.cadsoft.de - download - libraries

2011-05-02
  * led.lbr: Eagle 5.11.1
    added:
    MX6-ALU.DEV
    MX6-ALU.PAC

2011-04-06
  * led.lbr: Eagle 5.11.1
    added:
    MX3.DEV
    MX6.DEV
    PB3XX301V050A.DEV
    MX6.PAC
    PB3XX301V050A.PAC

2011-04-05
  * st-microelectronics.lbr: Eagle 5.11.1
    added:
    L293DD.DEV

2011-03-21
  * maxim.lbr: Eagle 5.11.1
    corrected pin direction: MAX6520.SYM

2011-03-17
  * avago.lbr: Eagle 5.11.1
    added:
    ACPL-790.DEV

2011-03-16
  * pot.lbr: Eagle 5.11.1
    added:
    EVU.DEV
    US-EVU.DEV
    EVUE.PAC
    EVUEXK.PAC
    EVUEXXJ.PAC
    EVUF.PAC
    EVUFXJ.PAC
    EVUFXK.PAC
    EVUFXL.PAC
    EVUFXM.PAC

2011-03-15
  * con-kycon.lbr: Eagle 5.11.1
    added:
    KUSBVX-BS1N.DEV
    KUSBVX-BS1N.PAC

2011-03-15
  * con-fci.lbr: Eagle 5.11.1
    added:
    FSE310074.DEV
    FSE310074.PAC

2011-03-11
  * linear-technology.lbr: Eagle 5.11.1
    corrected pad coordinats: SSOP16.PAC

2011-03-09
  * 40xx.lbr: Eagle 5.11.1
    added:
    HEF40098B.DEV

2011-03-09
  * infineon.lbr: Eagle 5.11.1
    corrected package: P-TO220-7-11.PAC

2011-03-07
  * microchip.lbr: Eagle 5.11.1
    corrected package:
    PIC17C75XPT.DEV
    PIC32MX420F032H.DEV

2011-03-07
  * microchip.lbr: Eagle 5.11.1
    added:
    TQFP64-10X10X1MM.PAC

2011-03-01
  * relay.lbr: Eagle 5.11.1
    added:
    AQW27.DEV
    AQZ26.DEV
    CPC1708J.DEV
    I4-PAC.PAC

2011-02-28
  * con-wago.lbr: Eagle 5.11.1
    added:
    236.DEV
    236-4XX.PAC
    236-5XX.PAC
    236-6XX.PAC
    236-ABSCHLUSSPLATTE.PAC

2011-02-28
  * national-semiconductor.lbr: Eagle 5.11.1
    added:
    LME49600.DEV
    TS5B.PAC

2011-02-25
  * con-shallin.lbr: Eagle 5.11.1
    added:
    K375M.DEV
    K375M.PAC

2011-02-24
  * con-kycon.lbr: Eagle 5.11.1
    added:
    KUSBVX.DEV
    KUSBVX.PAC

2011-02-24
  * on-semiconductor.lbr: Eagle 5.11.1
    added:
    NCP2820.DEV
    FLIP-CHIP9.PAC

2011-02-15
  * led.lbr: Eagle 5.11.0
    added:
    Z-POWER-LED.DEV

2011-02-15
  * relay.lbr: Eagle 5.11.0
    corrcted: pin pad connection
    FTR-K1C.DEV

2011-01-31
  * led.lbr: Eagle 5.11.0
    added:
    CLN6A.DEV
    CLN6A.PAC
    CP41B.PAC

2011-01-26
  * rcl.lbr: Eagle 5.11.0
    corrected: pad names
    RTRIM3314J.PAC
    added:
    RTRIM3314G.PAC

2011-01-18
  * e-klemmen.lbr: Eagle 5.11.0
    added:
    KLEMME-2_50-BRUECKE.DEV
    KLEMME-2_50-BRUECKE.PAC

2011-01-17
  * trimble.lbr: Eagle 5.11.0
    added / created by: Trimble Germany GmbH - Christian Voit
    C1011.DEV
    C1216.DEV
    C1722.DEV
    C1919A.DEV
    C1919B.DEV
    C1919C.DEV
    COPERNICUS.DEV
    COPERNICUS-II.DEV
    ICM-SMT_10MHZ.DEV
    ICM-SMT_40MHZ.DEV
    RESOLUTION-SMT.DEV
    TRIMBLE-LOGO.DEV
    1011.PAC
    1216.PAC
    1722.PAC
    1919.PAC
    TRIMBLE-LOGO.PAC

2011-01-05
  * infineon.lbr: Eagle 5.11.0
    pin offgrtid corrected:
    TLE5205-2.SYM

2010-12-23
  * zetex.lbr: Eagle 5.11.0
    added:
    ZXLD1350.DEV
    DMN3024LSD.DEV
    ZXMD63N03X.DEV
    renamed:
    PMOS2MSOP8.DEV to PMOS2.DEV
    NMOS2MSOP8.DEV to NMOS2.DEV
    pin connection corrected:
    NMOS2.DEV (NMOS2MSOP8.DEV)

2010-12-22
  * ftdichip.lbr: Eagle 5.11.0
    added:
    FT232B.DEV
    LQFP32-7X7.PAC

2010-12-15
  * con-kycon.lbr: Eagle 5.11.0
    added:
    GLX-S-88M.DEV
    GLX-S-88M.PAC

2010-12-08
  * atmel.lbr: Eagle 5.10.3
    move pins in default grid:
    XMEGA16A4.SYM
    XMEGA128A1.SYM

2010-12-02
  * altera.lbr: Eagle 5.10.3
    added:
    EPM240F100.DEV
    EPM240M100.DEV
    EPM240T100C4.DEV
    FBGA100.PAC
    MBGA100.PAC

2010-12-02
  * con-coax.lbr: Eagle 5.10.3
    added:
    MC-921.DEV
    MC-921.PAC
    SMA-142-0701-871.PAC

2010-12-02
  * crystal.lbr: Eagle 5.10.3
    added:
    ASE.DEV
    ASE.PAC

2010-12-02
  * national-semiconductor.lbr: Eagle 5.10.3
    added:
    LM2936?*.DEV
    LM2936M?*.DEV
    LM2936MP?*.DEV
    MINI-SO8.PAC
    SOT223.PAC

2010-12-01
  * altera-cyclone-II.lbr: Eagle 5.10.2
  * con-amp-champ.lbr: Eagle 5.10.2
  * con-amp-micromatch.lbr: Eagle 5.10.2
  * con-amp-mt.lbr: Eagle 5.10.2
  * con-amp-mt6.lbr: Eagle 5.10.2
  * con-amp-quick.lbr: Eagle 5.10.2
  * con-amp.lbr: Eagle 5.10.2
  * con-amphenol.lbr: Eagle 5.10.2
  * con-avx.lbr: Eagle 5.10.2
  * con-weidmueller-sl35.lbr: Eagle 5.10.2
    added Farnell and Newark order codes

2010-11-30
  * con-wago.lbr: Eagle 5.10.3
    added Farnell and Newark order codes

2010-11-30
  * microchip.lbr: Eagle 5.10.3
    added Farnell and Newark order codes

2010-11-30
  * con-kyocera-elco.lbr: Eagle 5.10.3
    added Farnell and Newark order codes

2010-11-30
  * con-wago255.lbr: Eagle 5.10.3
    added Farnell and Newark order codes

2010-11-25
  * crystal.lbr: Eagle 5.10.3
    added Farnell and Newark order codes

2010-11-25
  * switch-misc.lbr: Eagle 5.10.3
    9077-1.DEV
    9077-2.DEV
    added: Distributor

2010-11-25
  * con-4ucon.lbr: Eagle 5.10.3
  * con-3m.lbr: Eagle 5.10.3
    added Farnell and Newark order codes

2010-11-24
  * con-berg.lbr: Eagle 5.10.2
  * con-bosch.lbr: Eagle 5.10.2
  * con-chipcard-iso7816.lbr: Eagle 5.10.2
  * con-coax.lbr: Eagle 5.10.2
  * con-commcon.lbr: Eagle 5.10.2
  * con-cpci.lbr: Eagle 5.10.2
  * con-cui.lbr: Eagle 5.10.2
  * con-cypressindustries.lbr: Eagle 5.10.2
  * con-deutsch.lbr: Eagle 5.10.2
  * con-ebyelectro.lbr: Eagle 5.10.2
  * con-elco.lbr: Eagle 5.10.2
  * con-erni.lbr: Eagle 5.10.2
  * con-faston.lbr: Eagle 5.10.2
  * con-fci.lbr: Eagle 5.10.2
  * con-friwo.lbr: Eagle 5.10.2
  * con-harting-h.lbr: Eagle 5.10.2
  * con-harting-ml.lbr: Eagle 5.10.2
  * con-harting-v.lbr: Eagle 5.10.2
  * con-harting.lbr: Eagle 5.10.2
  * con-hirose.lbr: Eagle 5.10.2
  * con-hirschmann.lbr: Eagle 5.10.2
  * con-jack.lbr: Eagle 5.10.2
  * con-jae.lbr: Eagle 5.10.2
  * con-jst.lbr: Eagle 5.10.2
  * con-kycon.lbr: Eagle 5.10.2
  * con-lemo.lbr: Eagle 5.10.2
  * con-leotronics.lbr: Eagle 5.10.2
  * con-lsta.lbr: Eagle 5.10.2
  * con-lstb.lbr: Eagle 5.10.2
  * con-lumberg.lbr: Eagle 5.10.2
  * con-ml.lbr: Eagle 5.10.2
  * con-molex.lbr: Eagle 5.10.2
  * con-neutrik_ag.lbr: Eagle 5.10.2
  * con-omron.lbr: Eagle 5.10.2
  * con-panasonic.lbr: Eagle 5.10.2
  * con-panduit.lbr: Eagle 5.10.2
  * con-phoenix-254.lbr: Eagle 5.10.2
  * con-phoenix-3.81.lbr: Eagle 5.10.2
  * con-phoenix-350.lbr: Eagle 5.10.2
  * con-phoenix-500.lbr: Eagle 5.10.2
  * con-phoenix-508.lbr: Eagle 5.10.2
  * con-phoenix-762.lbr: Eagle 5.10.2
  * con-phoenix-me_max.lbr: Eagle 5.10.2
  * con-phoenix-mkds_5.lbr: Eagle 5.10.2
  * con-phoenix-smkdsp.lbr: Eagle 5.10.2
  * con-ptr500.lbr: Eagle 5.10.2
  * con-pulse.lbr: Eagle 5.10.2
  * con-rib.lbr: Eagle 5.10.2
  * con-samtec.lbr: Eagle 5.10.2
  * con-shiua-chyuan.lbr: Eagle 5.10.2
  * con-stewart.lbr: Eagle 5.10.2
  * con-stocko.lbr: Eagle 5.10.2
  * con-subd.lbr: Eagle 5.10.2
  * con-sullinselectronics.lbr: Eagle 5.10.2
  * con-thomas-betts.lbr: Eagle 5.10.2
  * con-tyco.lbr: Eagle 5.10.2
  * con-tycoelectronics.lbr: Eagle 5.10.2
  * con-wago-500.lbr: Eagle 5.10.2
  * con-wago-508.lbr: Eagle 5.10.2
  * con-weidmueller-sl35.lbr: Eagle 5.10.2
  * con-wenzhou-yihua.lbr: Eagle 5.10.2
  * con-yamaichi.lbr: Eagle 5.10.2
    added Farnell and Newark order codes

2010-11-16
  * texas.lbr: Eagle 5.10.3
    added Farnell and Newark order codes

2010-11-16
  * relay.lbr: Eagle 5.10.3
    added Farnell and Newark order codes

2010-11-16
  * philips-semiconductors.lbr: Eagle 5.10.3
    added Farnell and Newark order codes

2010-11-16
  * on-semiconductor.lbr: Eagle 5.10.3
    added Farnell and Newark order codes

2010-11-16
  * linear-technology.lbr: Eagle 5.10.3
    added Farnell and Newark order codes

2010-11-16
  * maxim.lbr: Eagle 5.10.3
    added Farnell and Newark order codes

2010-11-12
  * crystal.lbr: Eagle 5.10.3
    added Farnell and Newark order codes

2010-11-12
  * atmel.lbr: Eagle 5.10.3
    added Farnell and Newark order codes:
    AT45DB161D.DEV

2010-11-12
  * altera-stratix-iv.lbr: Eagle 5.10.2
  * analog-devices.lbr: Eagle 5.10.2
  * burr-brown.lbr: Eagle 5.10.2
  * buzzer.lbr: Eagle 5.10.2
  * display-lcd.lbr: Eagle 5.10.2
  * exar.lbr: Eagle 5.10.2
  * inductor-nkl.lbr: Eagle 5.10.2
  * memory-idt.lbr: Eagle 5.10.2
  * micro-fujitsu.lbr: Eagle 5.10.2
  * microchip.lbr: Eagle 5.10.2
  * opto-transmittter-hp.lbr: Eagle 5.10.2
  * optocoupler.lbr: Eagle 5.10.2
  * resistor-power.lbr: Eagle 5.10.2
  * resistor-sil.lbr: Eagle 5.10.2
  * sipex.lbr: Eagle 5.10.2
  * switch-dil.lbr: Eagle 5.10.2
  * traco-electronic.lbr: Eagle 5.10.2
  * trafo-xicon.lbr: Eagle 5.10.2
    added Farnell and Newark order codes

2010-11-11
  * sim-technology.lbr: Eagle 5.10.3
    added:
    SIM340DZ.DEV
    SIM340DZ.PAC

2010-11-11
  * optocoupler.lbr: Eagle 5.10.3
    renamed package: DIL16/4-1\7.PAC -> DIL16-4_1_7_10_16.PAC

2010-11-10
  * rcl.lbr: Eagle 5.10.3
    added:
    C1808.PAC
    C3640.PAC

2010-11-10
  * halo-electronics.lbr: Eagle 5.10.3
    added:
    TG110-E*N5.DEV
    TG110-E050N5.DEV
    N5.PAC

2010-11-10
  * linear-technology.lbr: Eagle 5.10.3
    added:
    LT3434.DEV

2010-11-10
  * con-kyocera-elco.lbr: Eagle 5.10.3
    renamed:
    5036-008-210-862.DEV
    5036_006_2?_862.DEV
    5036_006_223_862.DEV
    5036_006_200_862.PAC
    5036_006_201_862.PAC
    5036_006_223_862.PAC
    5036_006_299_862.PAC
    5036_008_210_862.PAC

2010-11-05
  * con-kyocera-elco.lbr: Eagle 5.10.2
    added:
    5035_006_2?_862.DEV
    5035_006_223_862.DEV
    5036-008-210-862.DEV
    5035_006_200_862.PAC
    5035_006_201_862.PAC
    5035_006_223_862.PAC
    5035_006_299_862.PAC
    5035_008_210_862.PAC

2010-11-05
  * advanced-test-technologies.lbr: Eagle 5.10.2
  * agilent-technologies.lbr: Eagle 5.10.2
  * allegro.lbr: Eagle 5.10.2
  * altera-cyclone-II.lbr: Eagle 5.10.2
  * altera-cyclone-III.lbr: Eagle 5.10.2
  * altera-stratix-iv.lbr: Eagle 5.10.2
  * altera.lbr: Eagle 5.10.2
  * amd-mach.lbr: Eagle 5.10.2
  * amis.lbr: Eagle 5.10.2
  * austriamicrosystems.lbr: Eagle 5.10.2
  * avago.lbr: Eagle 5.10.2
  * c-trimm.lbr: Eagle 5.10.2
  * california-micro-devices.lbr: Eagle 5.10.2
  * chipcard-siemens.lbr: Eagle 5.10.2
  * cirrus-logic.lbr: Eagle 5.10.2
  * csr.lbr: Eagle 5.10.2
  * cypress.lbr: Eagle 5.10.2
  * davicom.lbr: Eagle 5.10.2
  * dc-dc-converter.lbr: Eagle 5.10.2
  * display-hp.lbr: Eagle 5.10.2
  * display-kingbright.lbr: Eagle 5.10.2
  * fairchild-semic.lbr: Eagle 5.10.2
  * fiber-optic-hp.lbr: Eagle 5.10.2
  * fiber-optic-siemens.lbr: Eagle 5.10.2
  * fifo.lbr: Eagle 5.10.2
  * flexipanel.lbr: Eagle 5.10.2
  * fox-electronics.lbr: Eagle 5.10.2
  * freescale.lbr: Eagle 5.10.2
  * ftdichip.lbr: Eagle 5.10.2
  * fujitsu.lbr: Eagle 5.10.2
  * fuse.lbr: Eagle 5.10.2
  * gennum.lbr: Eagle 5.10.2
  * holtek.lbr: Eagle 5.10.2
  * inductor-coilcraft.lbr: Eagle 5.10.2
  * inductor-neosid.lbr: Eagle 5.10.2
  * infineon-tricore.lbr: Eagle 5.10.2
  * infineon.lbr: Eagle 5.10.2
  * intersil.lbr: Eagle 5.10.2
  * ir.lbr: Eagle 5.10.2
  * isd.lbr: Eagle 5.10.2
  * lantronix.lbr: Eagle 5.10.2
  * lattice.lbr: Eagle 5.10.2
  * lc-filter.lbr: Eagle 5.10.2
  * led-7-segment.lbr: Eagle 5.10.2
  * led-citizen-electronics.lbr: Eagle 5.10.2
  * led-lumiled.lbr: Eagle 5.10.2
  * lem.lbr: Eagle 5.10.2
  * linx.lbr: Eagle 5.10.2
  * lprs.lbr: Eagle 5.10.2
  * lumiled.lbr: Eagle 5.10.2
  * maxstream.lbr: Eagle 5.10.2
  * melexis.lbr: Eagle 5.10.2
  * memory-hitachi.lbr: Eagle 5.10.2
  * memory-micron.lbr: Eagle 5.10.2
  * memory-motorola-dram.lbr: Eagle 5.10.2
  * memory-nec.lbr: Eagle 5.10.2
  * memory-samsung.lbr: Eagle 5.10.2
  * micrel.lbr: Eagle 5.10.2
  * micro-cyrod.lbr: Eagle 5.10.2
  * micro-harris.lbr: Eagle 5.10.2
  * micro-hitachi.lbr: Eagle 5.10.2
  * micro-infineon.lbr: Eagle 5.10.2
  * micro-intel.lbr: Eagle 5.10.2
  * micro-mc68000.lbr: Eagle 5.10.2
  * micro-motorola.lbr: Eagle 5.10.2
  * micro-philips.lbr: Eagle 5.10.2
  * micro-renesas.lbr: Eagle 5.10.2
  * micro-samsung.lbr: Eagle 5.10.2
  * micro-siemens.lbr: Eagle 5.10.2
  * micron.lbr: Eagle 5.10.2
  * micronas.lbr: Eagle 5.10.2
  * microwave.lbr: Eagle 5.10.2
  * midori-sensor.lbr: Eagle 5.10.2
  * minicircuits.lbr: Eagle 5.10.2
  * motorola-sensor-driver.lbr: Eagle 5.10.2
  * murata-filter.lbr: Eagle 5.10.2
  * murata-sensor.lbr: Eagle 5.10.2
  * nanotec.lbr: Eagle 5.10.2
  * national-instruments.lbr: Eagle 5.10.2
  * national-semiconductor.lbr: Eagle 5.10.2
  * nec.lbr: Eagle 5.10.2
  * nrj-semiconductor.lbr: Eagle 5.10.2
  * omnivision.lbr: Eagle 5.10.2
  * opto-honeywell-3000.lbr: Eagle 5.10.2
  * opto-honeywell-4000.lbr: Eagle 5.10.2
  * opto-honeywell.lbr: Eagle 5.10.2
  * opto-micro-linear.lbr: Eagle 5.10.2
  * opto-trans-siemens.lbr: Eagle 5.10.2
  * opto-vishay.lbr: Eagle 5.10.2
  * pal.lbr: Eagle 5.10.2
  * piher.lbr: Eagle 5.10.2
  * pld-intel.lbr: Eagle 5.10.2
  * plxtech.lbr: Eagle 5.10.2
  * pot-vitrohm.lbr: Eagle 5.10.2
  * pot-xicor.lbr: Eagle 5.10.2
  * ptc-ntc.lbr: Eagle 5.10.2
  * quantum-research-group.lbr: Eagle 5.10.2
  * recom-international.lbr: Eagle 5.10.2
  * renesas.lbr: Eagle 5.10.2
  * resistor-bourns.lbr: Eagle 5.10.2
  * resistor-dil.lbr: Eagle 5.10.2
  * resistor-net.lbr: Eagle 5.10.2
  * resistor-ruf.lbr: Eagle 5.10.2
  * resistor-shunt.lbr: Eagle 5.10.2
  * rf-micro-devices.lbr: Eagle 5.10.2
  * rf-solutions.lbr: Eagle 5.10.2
  * rohm.lbr: Eagle 5.10.2
  * sensor-comus-group.lbr: Eagle 5.10.2
  * sensor-heraeus.lbr: Eagle 5.10.2
  * sensor-infratec.lbr: Eagle 5.10.2
  * sharp.lbr: Eagle 5.10.2
  * silabs.lbr: Eagle 5.10.2
  * solomon-systech.lbr: Eagle 5.10.2
  * st-microelectronics.lbr: Eagle 5.10.2
  * supertex.lbr: Eagle 5.10.2
  * switch-alps.lbr: Eagle 5.10.2
  * switch-omron.lbr: Eagle 5.10.2
  * telcom.lbr: Eagle 5.10.2
  * telecontrolli.lbr: Eagle 5.10.2
  * telefunken.lbr: Eagle 5.10.2
  * toshiba.lbr: Eagle 5.10.2
  * trafo-bei.lbr: Eagle 5.10.2
  * trafo-siemens.lbr: Eagle 5.10.2
  * tripas.lbr: Eagle 5.10.2
  * u-blox.lbr: Eagle 5.10.2
  * v-reg-micrel.lbr: Eagle 5.10.2
  * wafer-scale-psd.lbr: Eagle 5.10.2
  * xicor.lbr: Eagle 5.10.2
  * xilinx-virtex-v5.lbr: Eagle 5.10.2
  * xilinx-xc18v.lbr: Eagle 5.10.2
  * xilinx-xc9.lbr: Eagle 5.10.2
  * xilinx-xcv.lbr: Eagle 5.10.2
  * zetex.lbr: Eagle 5.10.2
    added Farnell and Newark order codes

2010-11-04
  * rectifier.lbr: Eagle 5.10.2
    added:
    LC03-6.DEV
    SO08.PAC

2010-11-04
  * rcl.lbr: Eagle 5.10.2
    added:
    1812X7R.PAC

2010-11-04
  * discrete.lbr: Eagle 5.10.2
    added:
    T23-A230X.DEV
    T23-A230X.PAC

2010-11-04
  * linear.lbr: Eagle 5.10.2
    added:
    OP1177.DEV
    OP1277.DEV
    OP1477.DEV
    TSSOP14-RU.PAC

2010-10-29
  * mitsubishi-semiconductor.lbr: Eagle 5.10.2
    added:
    PS21962-ST.DEV
    PS21962-ST.PAC

2010-10-27
  * philips-semiconductors.lbr: Eagle 5.10.2
    added:
    TDA8029.DEV
    LQFP32-7X7MM.PAC

2010-10-27
  * linear.lbr: Eagle 5.10.2
    added:
    MC79M.DEV
    MC78M.DEV
    NCV78M.DEV

2010-10-27
  * diode.lbr: Eagle 5.10.2
    added:
    SMF5.0AT1.DEV
    SOD123FL.PAC

2010-10-27
  * switch-raychem.lbr: Eagle 5.10.2
    added:
    SMD*F.DEV
    SMDH120.DEV
    SMD050F.PAC

2010-10-12
  * inductors.lbr: Eagle 5.10.2
    added:
    P0762.*NL.DEV
    P0762NL.PAC

2010-10-12
  * lsi-computer-systems.lbr: Eagle 5.10.2
    added:
    LS7766DH.DEV
    LS7766DO.DEV
    LS7766SH.DEV
    LS7766SO.DEV
    DIL48.PAC
    SOIC16LWB.PAC
    SOIC18L.PAC
    SOIC20L.PAC
    SOIC24L.PAC
    SOIC28L.PAC
    TSSOP14.PAC
    TSSOP20.PAC
    TSSOP24.PAC
    TSSOP28.PAC
    TSSOP38.PAC
    TSSOP48.PAC

2010-10-11
  * em-microelectronic.lbr: Eagle 5.10.2
    added:
    EM4095.DEV
    SO16.PAC

2010-10-11
  * crystal.lbr: Eagle 5.10.2
    added:
    8M10AHC49T.DEV
    10.DEV
    10G.DEV
    10M*A.DEV
    10M*B.DEV
    10M*C.DEV
    10M?D.DEV
    12M10AHC49HT.DEV
    12M10BHC49T.DEV
    14M20BHC49T.DEV
    16M20AUM1.DEV
    17M15AUM1.DEV
    21M*A.DEV
    21M*B.DEV
    21M*C.DEV
    21M15D.DEV
    45M*A.DEV
    45M*B.DEV
    46M15AUM1.DEV
    46M15BUM5.DEV
    49M8AHC49T.DEV
    54M10AUM1.DEV
    54M10AUM5.DEV
    64M10AUM1.DEV
    64M10AUM5.DEV
    69M7AUM1.DEV
    70M*.DEV
    90M15A.DEV
    ECS.DEV
    ECS-.DEV
    F90M.DEV
    IXF.DEV
    MF_.DEV
    F11/8A.PAC
    F13/8A.PAC
    F15/12B.PAC
    F18/12P.PAC
    HC49U.PAC
    M-1.PAC
    M-2.PAC
    M-3.PAC
    M-4.PAC
    M-5.PAC
    M-6.PAC
    M-A.PAC
    SC-1.PAC
    SC-2.PAC
    SC-3.PAC
    SC-4.PAC
    SC-5.PAC
    UM-1S.PAC
    UM-4S.PAC
    UM-5S.PAC
    UM1.PAC
    UM4.PAC
    UM5.PAC

2010-10-07
  * atmel.lbr: Eagle 5.10.2
    added:
    AT45DB161D.DEV
    VDFN-8.PAC

2010-10-06
  * linear-technology.lbr: Eagle 5.10.2
    corrected package: LGA50.PAC

2010-10-04
  * texas.lbr: Eagle 5.10.2
    added:
    BQ78PL114.DEV
    P-QFP48-7X7MM.PAC

2010-09-30
  * maxim.lbr: Eagle 5.10.2
    added:
    MAX618.DEV

2010-09-30
  * transistor-power.lbr: Eagle 5.10.2
    added:
    IRF4905.DEV
    IRFP25*.DEV
    IRFZ48.DEV
    IRLZ44Z.DEV
    RD06HVF1.DEV
    RD15HVF1.DEV
    ST*60N10.DEV
    ISOWATT218.PAC
    RD06HVF1.PAC

2010-09-29
  * con-wago.lbr: Eagle 5.10.2
    added:
    254-84*.DEV
    254-200.PAC
    254-842.PAC

2010-09-29
  * con-wago255.lbr: Eagle 5.10.2
    added:
    255-401-5.DEV
    255-402-5.DEV
    255-403-5.DEV
    255-404-5.DEV
    255-405-5.DEV
    255-406-5.DEV
    255-407-5.DEV
    255-408-5.DEV
    255-409-5.DEV
    255-410-5.DEV
    255-412-5.DEV
    255-416-5.DEV
    255-424-5.DEV
    255-436-5.DEV
    255-448-5.DEV

2010-09-24
  * diode.lbr: Eagle 5.10.2
    added:
    MBRS3*0T3.DEV

2010-09-24
  * inductors.lbr: Eagle 5.10.2
    renamed :
    DR1010.DEV to DR1030.DEV
    DR1010.PAC to DR1030.PAC

2010-09-23
  * relay.lbr: Eagle 5.10.2
    renamed AQZ10OD.DEV  to AQZ10*D.DEV and add technoligies
    renamed AQZ20OD.DEV to AQZ20*D.DEV and add technoligies
   corrected Package AQZ-SIL04 with photomos_sil4.dxf from Panasonic

2010-09-23
  * optocoupler.lbr: Eagle 5.10.2
    added:
    MOCD20*M.DEV
    SOIC08-FAIRCHILD.PAC

2010-09-20
  * inductors.lbr: Eagle 5.10.2
    added:
    DR1010.DEV
    DR1010.PAC

2010-09-17
  * logo.lbr: Eagle 5.10.2
    added:
    CS-EAGLE-HOLE-LOGO-43MM.PAC
    CS-LOGO-41MM.PAC
    CS-LOGO-43MM.PAC
    CS-LOGO-45MM.PAC
    CS-LOGO-TOP-43MM.PAC
    EAGLE-CS-LOGO-43.PAC
    EAGLE-PLC-30MM.PAC

2010-09-16
  * on-semiconductor.lbr: Eagle 5.10.2
    added:
    A5191HRT.DEV
    A5191HRTI.DEV
    A5191HRTI.PAC
    LQFP32-7X7MM.PAC
    PLCC28.PAC

2010-09-16
  * led.lbr: Eagle 5.10.1
    added:
    L-59EGW-CA.DEV
    TLLG4400.DEV
    TLLR4400.DEV
    TLLY4400.DEV
    L-59EGW-CA.PAC

2010-09-14
  * con-wago-508.lbr: Eagle 5.10.1
    added:
    236-412.DEV
    236-412.PAC

2010-09-07
  * on-semiconductor.lbr: Eagle 5.10.1
    added:
    MDC3105DMT1.DEV
    MDC3105LT1.DEV
    MDC3105XV6T1.DEV
    SC-74.PAC
    SOT-563.PAC
    SOT23.PAC

2010-09-07
  * texas.lbr: Eagle 5.10.1
    added:
    TPS5410.DEV

2010-09-07
  * micro-philips.lbr: Eagle 5.10.1
    added:
    PCA9534.DEV
    HVQFN16_3X3.PAC
    HVQFN16_4X4.PAC
    TSSOP16.PAC

2010-09-07
  * crystal.lbr: Eagle 5.10.1
    added:
    CSM-7X-DU.DEV
    MC-306.DEV
    MC-405.DEV
    MC-406.DEV
    CSM-7X-DU.PAC
    MC-306.PAC
    MC-405.PAC
    MC-406.PAC

2010-09-07
  * linear.lbr: Eagle 5.10.1
    added:
    OPA333.DEV
    OPA2333.DEV

2010-09-07
  * switch-coto.lbr: Eagle 5.10.1
    added:
    CT10-XXXX-.DEV
    CT10-XXXX-A2.PAC
    CT10-XXXX-G1.PAC
    CT10-XXXX-G4.PAC

2010-08-30
  * optocoupler.lbr: Eagle 5.10.1
    connected variant 'T' 'S': MOC30*.DEV

2010-08-27
  * battery.lbr: Eagle 5.10.1
    corrected symbol and connection: CR2/3.DEV

2010-08-18
  * 74xx-us.lbr: Eagle 5.10.0
    corrected name: 74671.SYM Pin 'CASC'

2010-08-18
  * 74xx-eu.lbr: Eagle 5.10.0
    corrected name: 74671.SYM Pin 'CASC'

2010-08-13
  * con-vg.lbr: Eagle 5.10.0
    corrected misspelled word in description: FAE32E.PAC

2010-07-29
  * 74xx-eu.lbr: Eagle 5.10.0
    changed description: internal link add "DEVICE:"
    74*51.DEV
    74S51.DEV

2010-07-29
  * 74xx-us.lbr: Eagle 5.10.0
    changed description: internal link add "DEVICE:"
    74*51.DEV
    74S51.DEV

2010-07-29
  * microchip.lbr: Eagle 5.10.0
    changed description: internal link add "DEVICE:"
    PIC16C*.DEV
    PIC16F8*.DEV

2010-07-09
  * linear.lbr: Eagle 5.10.0
    corrected symbol: ERA-*.DEV

2010-07-08
  * con-lumberg.lbr: Eagle 5.10.0
    changed: CINCH_4.SYM moved pins '2@1' '2@2' '2@3'

2010-07-08
  * exar.lbr: Eagle 5.10.0
    changed: XR-2100.SY; Pin name 'uC/!STD' to 'UC/!STD'

2010-07-08
  * con-hirschmann.lbr: Eagle 5.10.0
    changed: 1O.SYM rename PIN 'ö' to 'O'

2010-06-14
  * transistor.lbr: Eagle 5.10.0
    corrected: all technologies of variant TO92-EBC

2010-06-09
  * texas.lbr: Eagle 5.10.0
    added:
    DS1232LP.DEV

2010-06-09
  * micro-cyrod.lbr: Eagle 5.10.0
    added:
    CRD89C51RD.DEV
    CRD89C51RD-DIL40.DEV
    CRD89C51RD-QFP44.DEV
    DIL40.PAC
    PLCC44.PAC
    SQFP-S-10X10-44.PAC

2010-06-09
  * relay.lbr: Eagle 5.10.0
    added:
    6561-0300.DEV
    6561-0300.PAC

2010-05-26
  * telefunken.lbr: Eagle 5.9.3
    added:
    U893BSE.DEV
    SO08.PAC

2010-05-26
  * philips-semiconductors.lbr: Eagle 5.9.3
    added:
    SAB6456.DEV
    DIL08.PAC
    SO08.PAC

2010-05-26
  * on-semiconductor.lbr: Eagle 5.9.3
    added:
    MC12052A.DEV
    MC12080.DEV
    SO08.PAC

2010-05-26
  * fujitsu.lbr: Eagle 5.9.3
    added:
    MB50.DEV
    SO08.PAC

2010-05-26
  * national-semiconductor.lbr: Eagle 5.9.3
    added:
    LMX2322.DEV
    TSSOP16.PAC

2010-05-26
  * nec.lbr: Eagle 5.9.3
    added:
    UPB1505.DEV
    SO08.PAC

2010-05-26
  * texas.lbr: Eagle 5.9.3
    added:
    ISO1176.DEV

2010-05-26
  * st-microelectronics.lbr: Eagle 5.9.3
    added:
    STM8S105C.DEV
    STM8S105K.DEV
    STM8S105K*B.DEV
    STM8S105S.DEV
    LQFP32-7X7.PAC
    LQFP44-10X10.PAC
    LQFP48-7X7.PAC
    SPDIP32.PAC
    UFQFPN32.PAC
    VFQFPN32.PAC

2010-05-21
  * con-amphenol.lbr: Eagle 5.9.3
    added:
    SIMLOCK-C707_10M006_512_2.DEV
    C707_10M006_512_2.PAC

2010-05-20
  * analog-devices.lbr: Eagle 5.9.3
    added:
    ADUC84*-52.DEV
    ADUC84*-56.DEV
    LFCSP56.PAC
    MQFP52.PAC

2010-05-20
  * fuse.lbr: Eagle 5.9.3
    added:
    QPL.DEV
    QPL.PAC

2010-05-20
  * con-phoenix-3.81.lbr: Eagle 5.9.3
    added:
    1727036.DEV
    1727036.PAC

2010-05-20
  * con-hirose.lbr: Eagle 5.9.3
    added:
    FH12-08S-1S.DEV
    FH12-10S-0.5S.DEV
    FH12-11S-0.5S.DEV
    FH12-12S-0.5S.DEV
    FH12-13S-0.5S.DEV
    FH12-14S-0.5S.DEV
    FH12-15S-0.5S.DEV
    FH12-16S-0.5S.DEV
    FH12-16S-1S.DEV
    FH12-17S-0.5S.DEV
    FH12-18S-0.5S.DEV
    FH12-19S-0.5S.DEV
    FH12-20S-0.5S.DEV
    FH12-20S-1S.DEV
    FH12-22S-0.5S.DEV
    FH12-24S-0.5S.DEV
    FH12-25S-0.5S.DEV
    FH12-26S-0.5S.DEV
    FH12-28S-0.5S.DEV
    FH12-30S-0.5S.DEV
    FH12-32S-0.5S.DEV
    FH12-33S-0.5S.DEV
    FH12-34S-0.5S.DEV
    FH12-35S-0.5S.DEV
    FH12-36S-0.5S.DEV
    FH12-40S-0.5S.DEV
    FH12-45S-0.5S.DEV
    FH12-50S-0.5S.DEV
    FH12-53S-0.5S.DEV
    FH12-60S-0.5SV.DEV
    FH12-6S-0.5SH.PAC
    FH12-08S-1SH.PAC
    FH12-8S-0.5SH.PAC
    FH12-10S-0.5SH.PAC
    FH12-11S-0.5SH.PAC
    FH12-12S-0.5SH.PAC
    FH12-13S-0.5SH.PAC
    FH12-14S-0.5SH.PAC
    FH12-15S-0.5SH.PAC
    FH12-15S-0.5SV.PAC
    FH12-16S-0.5SH.PAC
    FH12-16S-1SH.PAC
    FH12-16S-1SV.PAC
    FH12-17S-0.5SH.PAC
    FH12-18S-0.5SH.PAC
    FH12-19S-0.5SH.PAC
    FH12-20S-0.5SH.PAC
    FH12-20S-1SV.PAC
    FH12-22S-0.5SH.PAC
    FH12-24S-0.5SH.PAC
    FH12-25S-0.5SH.PAC
    FH12-26S-0.5SH.PAC
    FH12-28S-0.5SH.PAC
    FH12-30S-0.5SH.PAC
    FH12-32S-0.5SH.PAC
    FH12-33S-0.5SH.PAC
    FH12-34S-0.5SH.PAC
    FH12-35S-0.5SH.PAC
    FH12-36S-0.5SH.PAC
    FH12-40S-0.5SH.PAC
    FH12-45S-0.5SH.PAC
    FH12-50S-0.5SH.PAC
    FH12-53S-0.5SH.PAC
    FH12-60S-0.5SV.PAC

2010-05-19
  * maxim.lbr: Eagle 5.9.3
    added:
    DS8500.DEV
    TQFN20-5X5.PAC

2010-05-18
  * led.lbr: Eagle 5.9.2
    added:
    *P4.DEV
    P47F-BOTTOM.PAC
    P47F-TOP.PAC

2010-05-18
  * con-samtec.lbr: Eagle 5.9.2
    added:
    SSW-101-02-S-D.DEV
    SSW-101-02-S-Q.DEV
    SSW-101-02-S-S.DEV
    SSW-101-02-S-T.DEV
    SSW-102-02-S-D.DEV
    SSW-102-02-S-Q.DEV
    SSW-102-02-S-S.DEV
    SSW-102-02-S-T.DEV
    SSW-103-02-S-D.DEV
    SSW-103-02-S-Q.DEV
    SSW-103-02-S-S.DEV
    SSW-103-02-S-T.DEV
    SSW-104-02-S-D.DEV
    SSW-104-02-S-Q.DEV
    SSW-104-02-S-S.DEV
    SSW-104-02-S-T.DEV
    SSW-105-02-S-D.DEV
    SSW-105-02-S-Q.DEV
    SSW-105-02-S-S.DEV
    SSW-105-02-S-T.DEV
    SSW-106-02-S-D.DEV
    SSW-106-02-S-Q.DEV
    SSW-106-02-S-S.DEV
    SSW-106-02-S-T.DEV
    SSW-107-02-S-D.DEV
    SSW-107-02-S-Q.DEV
    SSW-107-02-S-S.DEV
    SSW-107-02-S-T.DEV
    SSW-108-02-S-D.DEV
    SSW-108-02-S-Q.DEV
    SSW-108-02-S-S.DEV
    SSW-108-02-S-T.DEV
    SSW-109-02-S-D.DEV
    SSW-109-02-S-Q.DEV
    SSW-109-02-S-S.DEV
    SSW-109-02-S-T.DEV
    SSW-110-02-S-D.DEV
    SSW-110-02-S-Q.DEV
    SSW-110-02-S-S.DEV
    SSW-110-02-S-T.DEV
    SSW-111-02-S-D.DEV
    SSW-111-02-S-Q.DEV
    SSW-111-02-S-S.DEV
    SSW-111-02-S-T.DEV
    SSW-112-02-S-D.DEV
    SSW-112-02-S-Q.DEV
    SSW-112-02-S-S.DEV
    SSW-112-02-S-T.DEV
    SSW-113-02-S-D.DEV
    SSW-113-02-S-Q.DEV
    SSW-113-02-S-S.DEV
    SSW-113-02-S-T.DEV
    SSW-114-02-S-D.DEV
    SSW-114-02-S-Q.DEV
    SSW-114-02-S-S.DEV
    SSW-114-02-S-T.DEV
    SSW-115-02-S-D.DEV
    SSW-115-02-S-Q.DEV
    SSW-115-02-S-S.DEV
    SSW-115-02-S-T.DEV
    SSW-116-02-S-D.DEV
    SSW-116-02-S-Q.DEV
    SSW-116-02-S-S.DEV
    SSW-116-02-S-T.DEV
    SSW-117-02-S-D.DEV
    SSW-117-02-S-Q.DEV
    SSW-117-02-S-S.DEV
    SSW-117-02-S-T.DEV
    SSW-118-02-S-D.DEV
    SSW-118-02-S-Q.DEV
    SSW-118-02-S-S.DEV
    SSW-118-02-S-T.DEV
    SSW-119-02-S-D.DEV
    SSW-119-02-S-Q.DEV
    SSW-119-02-S-S.DEV
    SSW-119-02-S-T.DEV
    SSW-120-02-S-D.DEV
    SSW-120-02-S-Q.DEV
    SSW-120-02-S-S.DEV
    SSW-120-02-S-T.DEV
    SSW-121-02-S-D.DEV
    SSW-121-02-S-Q.DEV
    SSW-121-02-S-S.DEV
    SSW-121-02-S-T.DEV
    SSW-122-02-S-D.DEV
    SSW-122-02-S-Q.DEV
    SSW-122-02-S-S.DEV
    SSW-122-02-S-T.DEV
    SSW-123-02-S-D.DEV
    SSW-123-02-S-Q.DEV
    SSW-123-02-S-S.DEV
    SSW-123-02-S-T.DEV
    SSW-124-02-S-D.DEV
    SSW-124-02-S-Q.DEV
    SSW-124-02-S-S.DEV
    SSW-124-02-S-T.DEV
    SSW-125-02-S-D.DEV
    SSW-125-02-S-Q.DEV
    SSW-125-02-S-S.DEV
    SSW-125-02-S-T.DEV
    SSW-126-02-S-D.DEV
    SSW-126-02-S-Q.DEV
    SSW-126-02-S-S.DEV
    SSW-126-02-S-T.DEV
    SSW-127-02-S-D.DEV
    SSW-127-02-S-Q.DEV
    SSW-127-02-S-S.DEV
    SSW-127-02-S-T.DEV
    SSW-128-02-S-D.DEV
    SSW-128-02-S-Q.DEV
    SSW-128-02-S-S.DEV
    SSW-128-02-S-T.DEV
    SSW-129-02-S-D.DEV
    SSW-129-02-S-Q.DEV
    SSW-129-02-S-S.DEV
    SSW-129-02-S-T.DEV
    SSW-130-02-S-D.DEV
    SSW-130-02-S-Q.DEV
    SSW-130-02-S-S.DEV
    SSW-130-02-S-T.DEV
    SSW-131-02-S-D.DEV
    SSW-131-02-S-Q.DEV
    SSW-131-02-S-S.DEV
    SSW-131-02-S-T.DEV
    SSW-132-02-S-D.DEV
    SSW-132-02-S-Q.DEV
    SSW-132-02-S-S.DEV
    SSW-132-02-S-T.DEV
    SSW-133-02-S-D.DEV
    SSW-133-02-S-Q.DEV
    SSW-133-02-S-S.DEV
    SSW-133-02-S-T.DEV
    SSW-134-02-S-D.DEV
    SSW-134-02-S-Q.DEV
    SSW-134-02-S-S.DEV
    SSW-134-02-S-T.DEV
    SSW-135-02-S-D.DEV
    SSW-135-02-S-Q.DEV
    SSW-135-02-S-S.DEV
    SSW-135-02-S-T.DEV
    SSW-136-02-S-D.DEV
    SSW-136-02-S-Q.DEV
    SSW-136-02-S-S.DEV
    SSW-136-02-S-T.DEV
    SSW-137-02-S-D.DEV
    SSW-137-02-S-Q.DEV
    SSW-137-02-S-S.DEV
    SSW-137-02-S-T.DEV
    SSW-138-02-S-D.DEV
    SSW-138-02-S-Q.DEV
    SSW-138-02-S-S.DEV
    SSW-138-02-S-T.DEV
    SSW-139-02-S-D.DEV
    SSW-139-02-S-Q.DEV
    SSW-139-02-S-S.DEV
    SSW-139-02-S-T.DEV
    SSW-140-02-S-D.DEV
    SSW-140-02-S-Q.DEV
    SSW-140-02-S-S.DEV
    SSW-140-02-S-T.DEV
    SSW-141-02-S-D.DEV
    SSW-141-02-S-Q.DEV
    SSW-141-02-S-S.DEV
    SSW-141-02-S-T.DEV
    SSW-142-02-S-D.DEV
    SSW-142-02-S-Q.DEV
    SSW-142-02-S-S.DEV
    SSW-142-02-S-T.DEV
    SSW-143-02-S-D.DEV
    SSW-143-02-S-Q.DEV
    SSW-143-02-S-S.DEV
    SSW-143-02-S-T.DEV
    SSW-144-02-S-D.DEV
    SSW-144-02-S-Q.DEV
    SSW-144-02-S-S.DEV
    SSW-144-02-S-T.DEV
    SSW-145-02-S-D.DEV
    SSW-145-02-S-Q.DEV
    SSW-145-02-S-S.DEV
    SSW-145-02-S-T.DEV
    SSW-146-02-S-D.DEV
    SSW-146-02-S-Q.DEV
    SSW-146-02-S-S.DEV
    SSW-146-02-S-T.DEV
    SSW-147-02-S-D.DEV
    SSW-147-02-S-Q.DEV
    SSW-147-02-S-S.DEV
    SSW-147-02-S-T.DEV
    SSW-148-02-S-D.DEV
    SSW-148-02-S-Q.DEV
    SSW-148-02-S-S.DEV
    SSW-148-02-S-T.DEV
    SSW-149-02-S-D.DEV
    SSW-149-02-S-Q.DEV
    SSW-149-02-S-S.DEV
    SSW-149-02-S-T.DEV
    SSW-150-02-S-D.DEV
    SSW-150-02-S-Q.DEV
    SSW-150-02-S-S.DEV
    SSW-150-02-S-T.DEV
    TSW-101-02-S-D.DEV
    TSW-101-02-S-Q.DEV
    TSW-101-02-S-S.DEV
    TSW-102-02-S-D.DEV
    TSW-102-02-S-Q.DEV
    TSW-102-02-S-S.DEV
    TSW-103-02-S-D.DEV
    TSW-103-02-S-Q.DEV
    TSW-103-02-S-S.DEV
    TSW-104-02-S-D.DEV
    TSW-104-02-S-Q.DEV
    TSW-104-02-S-S.DEV
    TSW-105-02-S-D.DEV
    TSW-105-02-S-Q.DEV
    TSW-105-02-S-S.DEV
    TSW-106-02-S-D.DEV
    TSW-106-02-S-Q.DEV
    TSW-106-02-S-S.DEV
    TSW-107-02-S-D.DEV
    TSW-107-02-S-Q.DEV
    TSW-107-02-S-S.DEV
    TSW-108-02-S-D.DEV
    TSW-108-02-S-Q.DEV
    TSW-108-02-S-S.DEV
    TSW-109-02-S-D.DEV
    TSW-109-02-S-Q.DEV
    TSW-109-02-S-S.DEV
    TSW-110-02-S-D.DEV
    TSW-110-02-S-Q.DEV
    TSW-110-02-S-S.DEV
    TSW-111-02-S-D.DEV
    TSW-111-02-S-Q.DEV
    TSW-111-02-S-S.DEV
    TSW-112-02-S-D.DEV
    TSW-112-02-S-Q.DEV
    TSW-112-02-S-S.DEV
    TSW-113-02-S-D.DEV
    TSW-113-02-S-Q.DEV
    TSW-113-02-S-S.DEV
    TSW-114-02-S-D.DEV
    TSW-114-02-S-Q.DEV
    TSW-114-02-S-S.DEV
    TSW-115-02-S-D.DEV
    TSW-115-02-S-Q.DEV
    TSW-115-02-S-S.DEV
    TSW-116-02-S-D.DEV
    TSW-116-02-S-Q.DEV
    TSW-116-02-S-S.DEV
    TSW-117-02-S-D.DEV
    TSW-117-02-S-Q.DEV
    TSW-117-02-S-S.DEV
    TSW-118-02-S-D.DEV
    TSW-118-02-S-Q.DEV
    TSW-118-02-S-S.DEV
    TSW-119-02-S-D.DEV
    TSW-119-02-S-Q.DEV
    TSW-119-02-S-S.DEV
    TSW-120-02-S-D.DEV
    TSW-120-02-S-Q.DEV
    TSW-120-02-S-S.DEV
    TSW-121-02-S-D.DEV
    TSW-121-02-S-Q.DEV
    TSW-121-02-S-S.DEV
    TSW-122-02-S-D.DEV
    TSW-122-02-S-Q.DEV
    TSW-122-02-S-S.DEV
    TSW-123-02-S-D.DEV
    TSW-123-02-S-Q.DEV
    TSW-123-02-S-S.DEV
    TSW-124-02-S-D.DEV
    TSW-124-02-S-Q.DEV
    TSW-124-02-S-S.DEV
    TSW-125-02-S-D.DEV
    TSW-125-02-S-Q.DEV
    TSW-125-02-S-S.DEV
    TSW-126-02-S-D.DEV
    TSW-126-02-S-Q.DEV
    TSW-126-02-S-S.DEV
    TSW-127-02-S-D.DEV
    TSW-127-02-S-Q.DEV
    TSW-127-02-S-S.DEV
    TSW-128-02-S-D.DEV
    TSW-128-02-S-Q.DEV
    TSW-128-02-S-S.DEV
    TSW-129-02-S-D.DEV
    TSW-129-02-S-Q.DEV
    TSW-129-02-S-S.DEV
    TSW-130-02-S-D.DEV
    TSW-130-02-S-Q.DEV
    TSW-130-02-S-S.DEV
    TSW-131-02-S-D.DEV
    TSW-131-02-S-Q.DEV
    TSW-131-02-S-S.DEV
    TSW-132-02-S-D.DEV
    TSW-132-02-S-Q.DEV
    TSW-132-02-S-S.DEV
    TSW-133-02-S-D.DEV
    TSW-133-02-S-Q.DEV
    TSW-133-02-S-S.DEV
    TSW-134-02-S-D.DEV
    TSW-134-02-S-Q.DEV
    TSW-134-02-S-S.DEV
    TSW-135-02-S-D.DEV
    TSW-135-02-S-Q.DEV
    TSW-135-02-S-S.DEV
    TSW-136-02-S-D.DEV
    TSW-136-02-S-Q.DEV
    TSW-136-02-S-S.DEV
    TSW-137-02-S-D.DEV
    TSW-137-02-S-Q.DEV
    TSW-137-02-S-S.DEV
    TSW-138-02-S-D.DEV
    TSW-138-02-S-Q.DEV
    TSW-138-02-S-S.DEV
    TSW-139-02-S-D.DEV
    TSW-139-02-S-Q.DEV
    TSW-139-02-S-S.DEV
    TSW-140-02-S-D.DEV
    TSW-140-02-S-Q.DEV
    TSW-140-02-S-S.DEV
    TSW-141-02-S-D.DEV
    TSW-141-02-S-Q.DEV
    TSW-141-02-S-S.DEV
    TSW-142-02-S-D.DEV
    TSW-142-02-S-Q.DEV
    TSW-142-02-S-S.DEV
    TSW-143-02-S-D.DEV
    TSW-143-02-S-Q.DEV
    TSW-143-02-S-S.DEV
    TSW-144-02-S-D.DEV
    TSW-144-02-S-Q.DEV
    TSW-144-02-S-S.DEV
    TSW-145-02-S-D.DEV
    TSW-145-02-S-Q.DEV
    TSW-145-02-S-S.DEV
    TSW-146-02-S-D.DEV
    TSW-146-02-S-Q.DEV
    TSW-146-02-S-S.DEV
    TSW-147-02-S-D.DEV
    TSW-147-02-S-Q.DEV
    TSW-147-02-S-S.DEV
    TSW-148-02-S-D.DEV
    TSW-148-02-S-Q.DEV
    TSW-148-02-S-S.DEV
    TSW-149-02-S-D.DEV
    TSW-149-02-S-Q.DEV
    TSW-149-02-S-S.DEV
    TSW-150-02-S-D.DEV
    TSW-150-02-S-Q.DEV
    TSW-150-02-S-S.DEV
    TSW-150-02-S-T.DEV
    SSW-101-02-S-D.PAC
    SSW-101-02-S-D-RA.PAC
    SSW-101-02-S-Q.PAC
    SSW-101-02-S-Q-RA.PAC
    SSW-101-02-S-S.PAC
    SSW-101-02-S-S-RA.PAC
    SSW-101-02-S-T.PAC
    SSW-101-02-S-T-RA.PAC
    SSW-102-02-S-D.PAC
    SSW-102-02-S-D-RA.PAC
    SSW-102-02-S-Q.PAC
    SSW-102-02-S-Q-RA.PAC
    SSW-102-02-S-S.PAC
    SSW-102-02-S-S-RA.PAC
    SSW-102-02-S-T.PAC
    SSW-102-02-S-T-RA.PAC
    SSW-103-02-S-D.PAC
    SSW-103-02-S-D-RA.PAC
    SSW-103-02-S-Q.PAC
    SSW-103-02-S-Q-RA.PAC
    SSW-103-02-S-S.PAC
    SSW-103-02-S-S-RA.PAC
    SSW-103-02-S-T.PAC
    SSW-103-02-S-T-RA.PAC
    SSW-104-02-S-D.PAC
    SSW-104-02-S-D-RA.PAC
    SSW-104-02-S-Q.PAC
    SSW-104-02-S-Q-RA.PAC
    SSW-104-02-S-S.PAC
    SSW-104-02-S-S-RA.PAC
    SSW-104-02-S-T.PAC
    SSW-104-02-S-T-RA.PAC
    SSW-105-02-S-D.PAC
    SSW-105-02-S-D-RA.PAC
    SSW-105-02-S-Q.PAC
    SSW-105-02-S-Q-RA.PAC
    SSW-105-02-S-S.PAC
    SSW-105-02-S-S-RA.PAC
    SSW-105-02-S-T.PAC
    SSW-105-02-S-T-RA.PAC
    SSW-106-02-S-D.PAC
    SSW-106-02-S-D-RA.PAC
    SSW-106-02-S-Q.PAC
    SSW-106-02-S-Q-RA.PAC
    SSW-106-02-S-S.PAC
    SSW-106-02-S-S-RA.PAC
    SSW-106-02-S-T.PAC
    SSW-106-02-S-T-RA.PAC
    SSW-107-02-S-D.PAC
    SSW-107-02-S-D-RA.PAC
    SSW-107-02-S-Q.PAC
    SSW-107-02-S-Q-RA.PAC
    SSW-107-02-S-S.PAC
    SSW-107-02-S-S-RA.PAC
    SSW-107-02-S-T.PAC
    SSW-107-02-S-T-RA.PAC
    SSW-108-02-S-D.PAC
    SSW-108-02-S-D-RA.PAC
    SSW-108-02-S-Q.PAC
    SSW-108-02-S-Q-RA.PAC
    SSW-108-02-S-S.PAC
    SSW-108-02-S-S-RA.PAC
    SSW-108-02-S-T.PAC
    SSW-108-02-S-T-RA.PAC
    SSW-109-02-S-D.PAC
    SSW-109-02-S-D-RA.PAC
    SSW-109-02-S-Q.PAC
    SSW-109-02-S-Q-RA.PAC
    SSW-109-02-S-S.PAC
    SSW-109-02-S-S-RA.PAC
    SSW-109-02-S-T.PAC
    SSW-109-02-S-T-RA.PAC
    SSW-110-02-S-D.PAC
    SSW-110-02-S-D-RA.PAC
    SSW-110-02-S-Q.PAC
    SSW-110-02-S-Q-RA.PAC
    SSW-110-02-S-S.PAC
    SSW-110-02-S-S-RA.PAC
    SSW-110-02-S-T.PAC
    SSW-110-02-S-T-RA.PAC
    SSW-111-02-S-D.PAC
    SSW-111-02-S-D-RA.PAC
    SSW-111-02-S-Q.PAC
    SSW-111-02-S-Q-RA.PAC
    SSW-111-02-S-S.PAC
    SSW-111-02-S-S-RA.PAC
    SSW-111-02-S-T.PAC
    SSW-111-02-S-T-RA.PAC
    SSW-112-02-S-D.PAC
    SSW-112-02-S-D-RA.PAC
    SSW-112-02-S-Q.PAC
    SSW-112-02-S-Q-RA.PAC
    SSW-112-02-S-S.PAC
    SSW-112-02-S-S-RA.PAC
    SSW-112-02-S-T.PAC
    SSW-112-02-S-T-RA.PAC
    SSW-113-02-S-D.PAC
    SSW-113-02-S-D-RA.PAC
    SSW-113-02-S-Q.PAC
    SSW-113-02-S-Q-RA.PAC
    SSW-113-02-S-S.PAC
    SSW-113-02-S-S-RA.PAC
    SSW-113-02-S-T.PAC
    SSW-113-02-S-T-RA.PAC
    SSW-114-02-S-D.PAC
    SSW-114-02-S-D-RA.PAC
    SSW-114-02-S-Q.PAC
    SSW-114-02-S-Q-RA.PAC
    SSW-114-02-S-S.PAC
    SSW-114-02-S-S-RA.PAC
    SSW-114-02-S-T.PAC
    SSW-114-02-S-T-RA.PAC
    SSW-115-02-S-D.PAC
    SSW-115-02-S-D-RA.PAC
    SSW-115-02-S-Q.PAC
    SSW-115-02-S-Q-RA.PAC
    SSW-115-02-S-S.PAC
    SSW-115-02-S-S-RA.PAC
    SSW-115-02-S-T.PAC
    SSW-115-02-S-T-RA.PAC
    SSW-116-02-S-D.PAC
    SSW-116-02-S-D-RA.PAC
    SSW-116-02-S-Q.PAC
    SSW-116-02-S-Q-RA.PAC
    SSW-116-02-S-S.PAC
    SSW-116-02-S-S-RA.PAC
    SSW-116-02-S-T.PAC
    SSW-116-02-S-T-RA.PAC
    SSW-117-02-S-D.PAC
    SSW-117-02-S-D-RA.PAC
    SSW-117-02-S-Q.PAC
    SSW-117-02-S-Q-RA.PAC
    SSW-117-02-S-S.PAC
    SSW-117-02-S-S-RA.PAC
    SSW-117-02-S-T.PAC
    SSW-117-02-S-T-RA.PAC
    SSW-118-02-S-D.PAC
    SSW-118-02-S-D-RA.PAC
    SSW-118-02-S-Q.PAC
    SSW-118-02-S-Q-RA.PAC
    SSW-118-02-S-S.PAC
    SSW-118-02-S-S-RA.PAC
    SSW-118-02-S-T.PAC
    SSW-118-02-S-T-RA.PAC
    SSW-119-02-S-D.PAC
    SSW-119-02-S-D-RA.PAC
    SSW-119-02-S-Q.PAC
    SSW-119-02-S-Q-RA.PAC
    SSW-119-02-S-S.PAC
    SSW-119-02-S-S-RA.PAC
    SSW-119-02-S-T.PAC
    SSW-119-02-S-T-RA.PAC
    SSW-120-02-S-D.PAC
    SSW-120-02-S-D-RA.PAC
    SSW-120-02-S-Q.PAC
    SSW-120-02-S-Q-RA.PAC
    SSW-120-02-S-S.PAC
    SSW-120-02-S-S-RA.PAC
    SSW-120-02-S-T.PAC
    SSW-120-02-S-T-RA.PAC
    SSW-121-02-S-D.PAC
    SSW-121-02-S-D-RA.PAC
    SSW-121-02-S-Q.PAC
    SSW-121-02-S-Q-RA.PAC
    SSW-121-02-S-S.PAC
    SSW-121-02-S-S-RA.PAC
    SSW-121-02-S-T.PAC
    SSW-121-02-S-T-RA.PAC
    SSW-122-02-S-D.PAC
    SSW-122-02-S-D-RA.PAC
    SSW-122-02-S-Q.PAC
    SSW-122-02-S-Q-RA.PAC
    SSW-122-02-S-S.PAC
    SSW-122-02-S-S-RA.PAC
    SSW-122-02-S-T.PAC
    SSW-122-02-S-T-RA.PAC
    SSW-123-02-S-D.PAC
    SSW-123-02-S-D-RA.PAC
    SSW-123-02-S-Q.PAC
    SSW-123-02-S-Q-RA.PAC
    SSW-123-02-S-S.PAC
    SSW-123-02-S-S-RA.PAC
    SSW-123-02-S-T.PAC
    SSW-123-02-S-T-RA.PAC
    SSW-124-02-S-D.PAC
    SSW-124-02-S-D-RA.PAC
    SSW-124-02-S-Q.PAC
    SSW-124-02-S-Q-RA.PAC
    SSW-124-02-S-S.PAC
    SSW-124-02-S-S-RA.PAC
    SSW-124-02-S-T.PAC
    SSW-124-02-S-T-RA.PAC
    SSW-125-02-S-D.PAC
    SSW-125-02-S-D-RA.PAC
    SSW-125-02-S-Q.PAC
    SSW-125-02-S-Q-RA.PAC
    SSW-125-02-S-S.PAC
    SSW-125-02-S-S-RA.PAC
    SSW-125-02-S-T.PAC
    SSW-125-02-S-T-RA.PAC
    SSW-126-02-S-D.PAC
    SSW-126-02-S-D-RA.PAC
    SSW-126-02-S-Q.PAC
    SSW-126-02-S-Q-RA.PAC
    SSW-126-02-S-S.PAC
    SSW-126-02-S-S-RA.PAC
    SSW-126-02-S-T.PAC
    SSW-126-02-S-T-RA.PAC
    SSW-127-02-S-D.PAC
    SSW-127-02-S-D-RA.PAC
    SSW-127-02-S-Q.PAC
    SSW-127-02-S-Q-RA.PAC
    SSW-127-02-S-S.PAC
    SSW-127-02-S-S-RA.PAC
    SSW-127-02-S-T.PAC
    SSW-127-02-S-T-RA.PAC
    SSW-128-02-S-D.PAC
    SSW-128-02-S-D-RA.PAC
    SSW-128-02-S-Q.PAC
    SSW-128-02-S-Q-RA.PAC
    SSW-128-02-S-S.PAC
    SSW-128-02-S-S-RA.PAC
    SSW-128-02-S-T.PAC
    SSW-128-02-S-T-RA.PAC
    SSW-129-02-S-D.PAC
    SSW-129-02-S-D-RA.PAC
    SSW-129-02-S-Q.PAC
    SSW-129-02-S-Q-RA.PAC
    SSW-129-02-S-S.PAC
    SSW-129-02-S-S-RA.PAC
    SSW-129-02-S-T.PAC
    SSW-129-02-S-T-RA.PAC
    SSW-130-02-S-D.PAC
    SSW-130-02-S-D-RA.PAC
    SSW-130-02-S-Q.PAC
    SSW-130-02-S-Q-RA.PAC
    SSW-130-02-S-S.PAC
    SSW-130-02-S-S-RA.PAC
    SSW-130-02-S-T.PAC
    SSW-130-02-S-T-RA.PAC
    SSW-131-02-S-D.PAC
    SSW-131-02-S-D-RA.PAC
    SSW-131-02-S-Q.PAC
    SSW-131-02-S-Q-RA.PAC
    SSW-131-02-S-S.PAC
    SSW-131-02-S-S-RA.PAC
    SSW-131-02-S-T.PAC
    SSW-131-02-S-T-RA.PAC
    SSW-132-02-S-D.PAC
    SSW-132-02-S-D-RA.PAC
    SSW-132-02-S-Q.PAC
    SSW-132-02-S-Q-RA.PAC
    SSW-132-02-S-S.PAC
    SSW-132-02-S-S-RA.PAC
    SSW-132-02-S-T.PAC
    SSW-132-02-S-T-RA.PAC
    SSW-133-02-S-D.PAC
    SSW-133-02-S-D-RA.PAC
    SSW-133-02-S-Q.PAC
    SSW-133-02-S-Q-RA.PAC
    SSW-133-02-S-S.PAC
    SSW-133-02-S-S-RA.PAC
    SSW-133-02-S-T.PAC
    SSW-133-02-S-T-RA.PAC
    SSW-134-02-S-D.PAC
    SSW-134-02-S-D-RA.PAC
    SSW-134-02-S-Q.PAC
    SSW-134-02-S-Q-RA.PAC
    SSW-134-02-S-S.PAC
    SSW-134-02-S-S-RA.PAC
    SSW-134-02-S-T.PAC
    SSW-134-02-S-T-RA.PAC
    SSW-135-02-S-D.PAC
    SSW-135-02-S-D-RA.PAC
    SSW-135-02-S-Q.PAC
    SSW-135-02-S-Q-RA.PAC
    SSW-135-02-S-S.PAC
    SSW-135-02-S-S-RA.PAC
    SSW-135-02-S-T.PAC
    SSW-135-02-S-T-RA.PAC
    SSW-136-02-S-D.PAC
    SSW-136-02-S-D-RA.PAC
    SSW-136-02-S-Q.PAC
    SSW-136-02-S-Q-RA.PAC
    SSW-136-02-S-S.PAC
    SSW-136-02-S-S-RA.PAC
    SSW-136-02-S-T.PAC
    SSW-136-02-S-T-RA.PAC
    SSW-137-02-S-D.PAC
    SSW-137-02-S-D-RA.PAC
    SSW-137-02-S-Q.PAC
    SSW-137-02-S-Q-RA.PAC
    SSW-137-02-S-S.PAC
    SSW-137-02-S-S-RA.PAC
    SSW-137-02-S-T.PAC
    SSW-137-02-S-T-RA.PAC
    SSW-138-02-S-D.PAC
    SSW-138-02-S-D-RA.PAC
    SSW-138-02-S-Q.PAC
    SSW-138-02-S-Q-RA.PAC
    SSW-138-02-S-S.PAC
    SSW-138-02-S-S-RA.PAC
    SSW-138-02-S-T.PAC
    SSW-138-02-S-T-RA.PAC
    SSW-139-02-S-D.PAC
    SSW-139-02-S-D-RA.PAC
    SSW-139-02-S-Q.PAC
    SSW-139-02-S-Q-RA.PAC
    SSW-139-02-S-S.PAC
    SSW-139-02-S-S-RA.PAC
    SSW-139-02-S-T.PAC
    SSW-139-02-S-T-RA.PAC
    SSW-140-02-S-D.PAC
    SSW-140-02-S-D-RA.PAC
    SSW-140-02-S-Q.PAC
    SSW-140-02-S-Q-RA.PAC
    SSW-140-02-S-S.PAC
    SSW-140-02-S-S-RA.PAC
    SSW-140-02-S-T.PAC
    SSW-140-02-S-T-RA.PAC
    SSW-141-02-S-D.PAC
    SSW-141-02-S-D-RA.PAC
    SSW-141-02-S-Q.PAC
    SSW-141-02-S-Q-RA.PAC
    SSW-141-02-S-S.PAC
    SSW-141-02-S-S-RA.PAC
    SSW-141-02-S-T.PAC
    SSW-141-02-S-T-RA.PAC
    SSW-142-02-S-D.PAC
    SSW-142-02-S-D-RA.PAC
    SSW-142-02-S-Q.PAC
    SSW-142-02-S-Q-RA.PAC
    SSW-142-02-S-S.PAC
    SSW-142-02-S-S-RA.PAC
    SSW-142-02-S-T.PAC
    SSW-142-02-S-T-RA.PAC
    SSW-143-02-S-D.PAC
    SSW-143-02-S-D-RA.PAC
    SSW-143-02-S-Q.PAC
    SSW-143-02-S-Q-RA.PAC
    SSW-143-02-S-S.PAC
    SSW-143-02-S-S-RA.PAC
    SSW-143-02-S-T.PAC
    SSW-143-02-S-T-RA.PAC
    SSW-144-02-S-D.PAC
    SSW-144-02-S-D-RA.PAC
    SSW-144-02-S-Q.PAC
    SSW-144-02-S-Q-RA.PAC
    SSW-144-02-S-S.PAC
    SSW-144-02-S-S-RA.PAC
    SSW-144-02-S-T.PAC
    SSW-144-02-S-T-RA.PAC
    SSW-145-02-S-D.PAC
    SSW-145-02-S-D-RA.PAC
    SSW-145-02-S-Q.PAC
    SSW-145-02-S-Q-RA.PAC
    SSW-145-02-S-S.PAC
    SSW-145-02-S-S-RA.PAC
    SSW-145-02-S-T.PAC
    SSW-145-02-S-T-RA.PAC
    SSW-146-02-S-D.PAC
    SSW-146-02-S-D-RA.PAC
    SSW-146-02-S-Q.PAC
    SSW-146-02-S-Q-RA.PAC
    SSW-146-02-S-S.PAC
    SSW-146-02-S-S-RA.PAC
    SSW-146-02-S-T.PAC
    SSW-146-02-S-T-RA.PAC
    SSW-147-02-S-D.PAC
    SSW-147-02-S-D-RA.PAC
    SSW-147-02-S-Q.PAC
    SSW-147-02-S-Q-RA.PAC
    SSW-147-02-S-S.PAC
    SSW-147-02-S-S-RA.PAC
    SSW-147-02-S-T.PAC
    SSW-147-02-S-T-RA.PAC
    SSW-148-02-S-D.PAC
    SSW-148-02-S-D-RA.PAC
    SSW-148-02-S-Q.PAC
    SSW-148-02-S-Q-RA.PAC
    SSW-148-02-S-S.PAC
    SSW-148-02-S-S-RA.PAC
    SSW-148-02-S-T.PAC
    SSW-148-02-S-T-RA.PAC
    SSW-149-02-S-D.PAC
    SSW-149-02-S-D-RA.PAC
    SSW-149-02-S-Q.PAC
    SSW-149-02-S-Q-RA.PAC
    SSW-149-02-S-S.PAC
    SSW-149-02-S-S-RA.PAC
    SSW-149-02-S-T.PAC
    SSW-149-02-S-T-RA.PAC
    SSW-150-02-S-D.PAC
    SSW-150-02-S-D-RA.PAC
    SSW-150-02-S-Q.PAC
    SSW-150-02-S-Q-RA.PAC
    SSW-150-02-S-S.PAC
    SSW-150-02-S-S-RA.PAC
    SSW-150-02-S-T.PAC
    SSW-150-02-S-T-RA.PAC
    TSW-101-02-S-D.PAC
    TSW-101-02-S-D-RA.PAC
    TSW-101-02-S-Q.PAC
    TSW-101-02-S-Q-RA.PAC
    TSW-101-02-S-S.PAC
    TSW-101-02-S-S-RA.PAC
    TSW-101-02-S-T.PAC
    TSW-101-02-S-T-RA.PAC
    TSW-102-02-S-D.PAC
    TSW-102-02-S-D-RA.PAC
    TSW-102-02-S-Q.PAC
    TSW-102-02-S-Q-RA.PAC
    TSW-102-02-S-S.PAC
    TSW-102-02-S-S-RA.PAC
    TSW-102-02-S-T.PAC
    TSW-102-02-S-T-RA.PAC
    TSW-103-02-S-D.PAC
    TSW-103-02-S-D-RA.PAC
    TSW-103-02-S-Q.PAC
    TSW-103-02-S-Q-RA.PAC
    TSW-103-02-S-S.PAC
    TSW-103-02-S-S-RA.PAC
    TSW-103-02-S-T.PAC
    TSW-103-02-S-T-RA.PAC
    TSW-104-02-S-D.PAC
    TSW-104-02-S-D-RA.PAC
    TSW-104-02-S-Q.PAC
    TSW-104-02-S-Q-RA.PAC
    TSW-104-02-S-S.PAC
    TSW-104-02-S-S-RA.PAC
    TSW-104-02-S-T.PAC
    TSW-104-02-S-T-RA.PAC
    TSW-105-02-S-D.PAC
    TSW-105-02-S-D-RA.PAC
    TSW-105-02-S-Q.PAC
    TSW-105-02-S-Q-RA.PAC
    TSW-105-02-S-S.PAC
    TSW-105-02-S-S-RA.PAC
    TSW-105-02-S-T.PAC
    TSW-105-02-S-T-RA.PAC
    TSW-106-02-S-D.PAC
    TSW-106-02-S-D-RA.PAC
    TSW-106-02-S-Q.PAC
    TSW-106-02-S-Q-RA.PAC
    TSW-106-02-S-S.PAC
    TSW-106-02-S-S-RA.PAC
    TSW-106-02-S-T.PAC
    TSW-106-02-S-T-RA.PAC
    TSW-107-02-S-D.PAC
    TSW-107-02-S-D-RA.PAC
    TSW-107-02-S-Q.PAC
    TSW-107-02-S-Q-RA.PAC
    TSW-107-02-S-S.PAC
    TSW-107-02-S-S-RA.PAC
    TSW-107-02-S-T.PAC
    TSW-107-02-S-T-RA.PAC
    TSW-108-02-S-D.PAC
    TSW-108-02-S-D-RA.PAC
    TSW-108-02-S-Q.PAC
    TSW-108-02-S-Q-RA.PAC
    TSW-108-02-S-S.PAC
    TSW-108-02-S-S-RA.PAC
    TSW-108-02-S-T.PAC
    TSW-108-02-S-T-RA.PAC
    TSW-109-02-S-D.PAC
    TSW-109-02-S-D-RA.PAC
    TSW-109-02-S-Q.PAC
    TSW-109-02-S-Q-RA.PAC
    TSW-109-02-S-S.PAC
    TSW-109-02-S-S-RA.PAC
    TSW-109-02-S-T.PAC
    TSW-109-02-S-T-RA.PAC
    TSW-110-02-S-D.PAC
    TSW-110-02-S-D-RA.PAC
    TSW-110-02-S-Q.PAC
    TSW-110-02-S-Q-RA.PAC
    TSW-110-02-S-S.PAC
    TSW-110-02-S-S-RA.PAC
    TSW-110-02-S-T.PAC
    TSW-110-02-S-T-RA.PAC
    TSW-111-02-S-D.PAC
    TSW-111-02-S-D-RA.PAC
    TSW-111-02-S-Q.PAC
    TSW-111-02-S-Q-RA.PAC
    TSW-111-02-S-S.PAC
    TSW-111-02-S-S-RA.PAC
    TSW-111-02-S-T.PAC
    TSW-111-02-S-T-RA.PAC
    TSW-112-02-S-D.PAC
    TSW-112-02-S-D-RA.PAC
    TSW-112-02-S-Q.PAC
    TSW-112-02-S-Q-RA.PAC
    TSW-112-02-S-S.PAC
    TSW-112-02-S-S-RA.PAC
    TSW-112-02-S-T.PAC
    TSW-112-02-S-T-RA.PAC
    TSW-113-02-S-D.PAC
    TSW-113-02-S-D-RA.PAC
    TSW-113-02-S-Q.PAC
    TSW-113-02-S-Q-RA.PAC
    TSW-113-02-S-S.PAC
    TSW-113-02-S-S-RA.PAC
    TSW-113-02-S-T.PAC
    TSW-113-02-S-T-RA.PAC
    TSW-114-02-S-D.PAC
    TSW-114-02-S-D-RA.PAC
    TSW-114-02-S-Q.PAC
    TSW-114-02-S-Q-RA.PAC
    TSW-114-02-S-S.PAC
    TSW-114-02-S-S-RA.PAC
    TSW-114-02-S-T.PAC
    TSW-114-02-S-T-RA.PAC
    TSW-115-02-S-D.PAC
    TSW-115-02-S-D-RA.PAC
    TSW-115-02-S-Q.PAC
    TSW-115-02-S-Q-RA.PAC
    TSW-115-02-S-S.PAC
    TSW-115-02-S-S-RA.PAC
    TSW-115-02-S-T.PAC
    TSW-115-02-S-T-RA.PAC
    TSW-116-02-S-D.PAC
    TSW-116-02-S-D-RA.PAC
    TSW-116-02-S-Q.PAC
    TSW-116-02-S-Q-RA.PAC
    TSW-116-02-S-S.PAC
    TSW-116-02-S-S-RA.PAC
    TSW-116-02-S-T.PAC
    TSW-116-02-S-T-RA.PAC
    TSW-117-02-S-D.PAC
    TSW-117-02-S-D-RA.PAC
    TSW-117-02-S-Q.PAC
    TSW-117-02-S-Q-RA.PAC
    TSW-117-02-S-S.PAC
    TSW-117-02-S-S-RA.PAC
    TSW-117-02-S-T.PAC
    TSW-117-02-S-T-RA.PAC
    TSW-118-02-S-D.PAC
    TSW-118-02-S-D-RA.PAC
    TSW-118-02-S-Q.PAC
    TSW-118-02-S-Q-RA.PAC
    TSW-118-02-S-S.PAC
    TSW-118-02-S-S-RA.PAC
    TSW-118-02-S-T.PAC
    TSW-118-02-S-T-RA.PAC
    TSW-119-02-S-D.PAC
    TSW-119-02-S-D-RA.PAC
    TSW-119-02-S-Q.PAC
    TSW-119-02-S-Q-RA.PAC
    TSW-119-02-S-S.PAC
    TSW-119-02-S-S-RA.PAC
    TSW-119-02-S-T.PAC
    TSW-119-02-S-T-RA.PAC
    TSW-120-02-S-D.PAC
    TSW-120-02-S-D-RA.PAC
    TSW-120-02-S-Q.PAC
    TSW-120-02-S-Q-RA.PAC
    TSW-120-02-S-S.PAC
    TSW-120-02-S-S-RA.PAC
    TSW-120-02-S-T.PAC
    TSW-120-02-S-T-RA.PAC
    TSW-121-02-S-D.PAC
    TSW-121-02-S-D-RA.PAC
    TSW-121-02-S-Q.PAC
    TSW-121-02-S-Q-RA.PAC
    TSW-121-02-S-S.PAC
    TSW-121-02-S-S-RA.PAC
    TSW-121-02-S-T.PAC
    TSW-121-02-S-T-RA.PAC
    TSW-122-02-S-D.PAC
    TSW-122-02-S-D-RA.PAC
    TSW-122-02-S-Q.PAC
    TSW-122-02-S-Q-RA.PAC
    TSW-122-02-S-S.PAC
    TSW-122-02-S-S-RA.PAC
    TSW-122-02-S-T.PAC
    TSW-122-02-S-T-RA.PAC
    TSW-123-02-S-D.PAC
    TSW-123-02-S-D-RA.PAC
    TSW-123-02-S-Q.PAC
    TSW-123-02-S-Q-RA.PAC
    TSW-123-02-S-S.PAC
    TSW-123-02-S-S-RA.PAC
    TSW-123-02-S-T.PAC
    TSW-123-02-S-T-RA.PAC
    TSW-124-02-S-D.PAC
    TSW-124-02-S-D-RA.PAC
    TSW-124-02-S-Q.PAC
    TSW-124-02-S-Q-RA.PAC
    TSW-124-02-S-S.PAC
    TSW-124-02-S-S-RA.PAC
    TSW-124-02-S-T.PAC
    TSW-124-02-S-T-RA.PAC
    TSW-125-02-S-D.PAC
    TSW-125-02-S-D-RA.PAC
    TSW-125-02-S-Q.PAC
    TSW-125-02-S-Q-RA.PAC
    TSW-125-02-S-S.PAC
    TSW-125-02-S-S-RA.PAC
    TSW-125-02-S-T.PAC
    TSW-125-02-S-T-RA.PAC
    TSW-126-02-S-D.PAC
    TSW-126-02-S-D-RA.PAC
    TSW-126-02-S-Q.PAC
    TSW-126-02-S-Q-RA.PAC
    TSW-126-02-S-S.PAC
    TSW-126-02-S-S-RA.PAC
    TSW-126-02-S-T.PAC
    TSW-126-02-S-T-RA.PAC
    TSW-127-02-S-D.PAC
    TSW-127-02-S-D-RA.PAC
    TSW-127-02-S-Q.PAC
    TSW-127-02-S-Q-RA.PAC
    TSW-127-02-S-S.PAC
    TSW-127-02-S-S-RA.PAC
    TSW-127-02-S-T.PAC
    TSW-127-02-S-T-RA.PAC
    TSW-128-02-S-D.PAC
    TSW-128-02-S-D-RA.PAC
    TSW-128-02-S-Q.PAC
    TSW-128-02-S-Q-RA.PAC
    TSW-128-02-S-S.PAC
    TSW-128-02-S-S-RA.PAC
    TSW-128-02-S-T.PAC
    TSW-128-02-S-T-RA.PAC
    TSW-129-02-S-D.PAC
    TSW-129-02-S-D-RA.PAC
    TSW-129-02-S-Q.PAC
    TSW-129-02-S-Q-RA.PAC
    TSW-129-02-S-S.PAC
    TSW-129-02-S-S-RA.PAC
    TSW-129-02-S-T.PAC
    TSW-129-02-S-T-RA.PAC
    TSW-130-02-S-D.PAC
    TSW-130-02-S-D-RA.PAC
    TSW-130-02-S-Q.PAC
    TSW-130-02-S-Q-RA.PAC
    TSW-130-02-S-S.PAC
    TSW-130-02-S-S-RA.PAC
    TSW-130-02-S-T.PAC
    TSW-130-02-S-T-RA.PAC
    TSW-131-02-S-D.PAC
    TSW-131-02-S-D-RA.PAC
    TSW-131-02-S-Q.PAC
    TSW-131-02-S-Q-RA.PAC
    TSW-131-02-S-S.PAC
    TSW-131-02-S-S-RA.PAC
    TSW-131-02-S-T.PAC
    TSW-131-02-S-T-RA.PAC
    TSW-132-02-S-D.PAC
    TSW-132-02-S-D-RA.PAC
    TSW-132-02-S-Q.PAC
    TSW-132-02-S-Q-RA.PAC
    TSW-132-02-S-S.PAC
    TSW-132-02-S-S-RA.PAC
    TSW-132-02-S-T.PAC
    TSW-132-02-S-T-RA.PAC
    TSW-133-02-S-D.PAC
    TSW-133-02-S-D-RA.PAC
    TSW-133-02-S-Q.PAC
    TSW-133-02-S-Q-RA.PAC
    TSW-133-02-S-S.PAC
    TSW-133-02-S-S-RA.PAC
    TSW-133-02-S-T.PAC
    TSW-133-02-S-T-RA.PAC
    TSW-134-02-S-D.PAC
    TSW-134-02-S-D-RA.PAC
    TSW-134-02-S-Q.PAC
    TSW-134-02-S-Q-RA.PAC
    TSW-134-02-S-S.PAC
    TSW-134-02-S-S-RA.PAC
    TSW-134-02-S-T.PAC
    TSW-134-02-S-T-RA.PAC
    TSW-135-02-S-D.PAC
    TSW-135-02-S-D-RA.PAC
    TSW-135-02-S-Q.PAC
    TSW-135-02-S-Q-RA.PAC
    TSW-135-02-S-S.PAC
    TSW-135-02-S-S-RA.PAC
    TSW-135-02-S-T.PAC
    TSW-135-02-S-T-RA.PAC
    TSW-136-02-S-D.PAC
    TSW-136-02-S-D-RA.PAC
    TSW-136-02-S-Q.PAC
    TSW-136-02-S-Q-RA.PAC
    TSW-136-02-S-S.PAC
    TSW-136-02-S-S-RA.PAC
    TSW-136-02-S-T.PAC
    TSW-136-02-S-T-RA.PAC
    TSW-137-02-S-D.PAC
    TSW-137-02-S-D-RA.PAC
    TSW-137-02-S-Q.PAC
    TSW-137-02-S-Q-RA.PAC
    TSW-137-02-S-S.PAC
    TSW-137-02-S-S-RA.PAC
    TSW-137-02-S-T.PAC
    TSW-137-02-S-T-RA.PAC
    TSW-138-02-S-D.PAC
    TSW-138-02-S-D-RA.PAC
    TSW-138-02-S-Q.PAC
    TSW-138-02-S-Q-RA.PAC
    TSW-138-02-S-S.PAC
    TSW-138-02-S-S-RA.PAC
    TSW-138-02-S-T.PAC
    TSW-138-02-S-T-RA.PAC
    TSW-139-02-S-D.PAC
    TSW-139-02-S-D-RA.PAC
    TSW-139-02-S-Q.PAC
    TSW-139-02-S-Q-RA.PAC
    TSW-139-02-S-S.PAC
    TSW-139-02-S-S-RA.PAC
    TSW-139-02-S-T.PAC
    TSW-139-02-S-T-RA.PAC
    TSW-140-02-S-D.PAC
    TSW-140-02-S-D-RA.PAC
    TSW-140-02-S-Q.PAC
    TSW-140-02-S-Q-RA.PAC
    TSW-140-02-S-S.PAC
    TSW-140-02-S-S-RA.PAC
    TSW-140-02-S-T.PAC
    TSW-140-02-S-T-RA.PAC
    TSW-141-02-S-D.PAC
    TSW-141-02-S-D-RA.PAC
    TSW-141-02-S-Q.PAC
    TSW-141-02-S-Q-RA.PAC
    TSW-141-02-S-S.PAC
    TSW-141-02-S-S-RA.PAC
    TSW-141-02-S-T.PAC
    TSW-141-02-S-T-RA.PAC
    TSW-142-02-S-D.PAC
    TSW-142-02-S-D-RA.PAC
    TSW-142-02-S-Q.PAC
    TSW-142-02-S-Q-RA.PAC
    TSW-142-02-S-S.PAC
    TSW-142-02-S-S-RA.PAC
    TSW-142-02-S-T.PAC
    TSW-142-02-S-T-RA.PAC
    TSW-143-02-S-D.PAC
    TSW-143-02-S-D-RA.PAC
    TSW-143-02-S-Q.PAC
    TSW-143-02-S-Q-RA.PAC
    TSW-143-02-S-S.PAC
    TSW-143-02-S-S-RA.PAC
    TSW-143-02-S-T.PAC
    TSW-143-02-S-T-RA.PAC
    TSW-144-02-S-D.PAC
    TSW-144-02-S-D-RA.PAC
    TSW-144-02-S-Q.PAC
    TSW-144-02-S-Q-RA.PAC
    TSW-144-02-S-S.PAC
    TSW-144-02-S-S-RA.PAC
    TSW-144-02-S-T.PAC
    TSW-144-02-S-T-RA.PAC
    TSW-145-02-S-D.PAC
    TSW-145-02-S-D-RA.PAC
    TSW-145-02-S-Q.PAC
    TSW-145-02-S-Q-RA.PAC
    TSW-145-02-S-S.PAC
    TSW-145-02-S-S-RA.PAC
    TSW-145-02-S-T.PAC
    TSW-145-02-S-T-RA.PAC
    TSW-146-02-S-D.PAC
    TSW-146-02-S-D-RA.PAC
    TSW-146-02-S-Q.PAC
    TSW-146-02-S-Q-RA.PAC
    TSW-146-02-S-S.PAC
    TSW-146-02-S-S-RA.PAC
    TSW-146-02-S-T.PAC
    TSW-146-02-S-T-RA.PAC
    TSW-147-02-S-D.PAC
    TSW-147-02-S-D-RA.PAC
    TSW-147-02-S-Q.PAC
    TSW-147-02-S-Q-RA.PAC
    TSW-147-02-S-S.PAC
    TSW-147-02-S-S-RA.PAC
    TSW-147-02-S-T.PAC
    TSW-147-02-S-T-RA.PAC
    TSW-148-02-S-D.PAC
    TSW-148-02-S-D-RA.PAC
    TSW-148-02-S-Q.PAC
    TSW-148-02-S-Q-RA.PAC
    TSW-148-02-S-S.PAC
    TSW-148-02-S-S-RA.PAC
    TSW-148-02-S-T.PAC
    TSW-148-02-S-T-RA.PAC
    TSW-149-02-S-D.PAC
    TSW-149-02-S-D-RA.PAC
    TSW-149-02-S-Q.PAC
    TSW-149-02-S-Q-RA.PAC
    TSW-149-02-S-S.PAC
    TSW-149-02-S-S-RA.PAC
    TSW-149-02-S-T.PAC
    TSW-149-02-S-T-RA.PAC
    TSW-150-02-S-D.PAC
    TSW-150-02-S-D-RA.PAC
    TSW-150-02-S-Q.PAC
    TSW-150-02-S-Q-RA.PAC
    TSW-150-02-S-S.PAC
    TSW-150-02-S-S-RA.PAC
    TSW-150-02-S-T.PAC
    TSW-150-02-S-T-RA.PAC

2010-05-17
  * con-tycoelectronics.lbr: Eagle 5.9.2
    finished: RJ11.DEV connected

2010-05-17
  * rcl.lbr: Eagle 5.9.2
    corrected PAD names: TSM53YJ.PAC

2010-05-10
  * display-kingbright.lbr: Eagle 5.9.1
    added:
    TC20-11HWA.DEV

2010-05-05
  * diode.lbr: Eagle 5.9.1
    added:
    MBRA340T3.DEV
    SMA.PAC

2010-05-05
  * national-semiconductor.lbr: Eagle 5.9.1
    added:
    LM2596.DEV
    LP2950.DEV
    LP2951.DEV
    DIL08.PAC
    H08C.PAC
    LLP8.PAC
    SO08.PAC
    T05A.PAC
    T05D.PAC
    TO92.PAC
    TO252.PAC
    TO263-5.PAC
    WG10A.PAC

2010-05-05
  * holtek.lbr: Eagle 5.9.1
    added:
    HT9170.DEV
    SO18L.PAC

2010-05-04
  * display-kingbright.lbr: Eagle 5.9.1
    added:
    TA20-11HWA.DEV
    TA20-11HWA.PAC

2010-05-04
  * freescale.lbr: Eagle 5.9.1
    added:
    MC9S08GT*A-32.DEV
    MC9S08GT*A-42.DEV
    MC9S08GT*A-44.DEV
    MC9S08GT*A-48.DEV
    QFN32.PAC
    QFN48.PAC

2010-05-03
  * 751xx.lbr: Eagle 5.9.1
    added:
    75176A.DEV
    DIL08.PAC
    D_R-PDSO-G8.PAC

2010-05-03
  * atmel.lbr: Eagle 5.9.1
    added:
    ATMEGA644-*PU.DEV

2010-05-03
  * memory.lbr: Eagle 5.9.1
    added:
    FM93C66.DEV
    DIL08.PAC
    M8.PAC
    TSSOP8.PAC

2010-05-03
  * st-microelectronics.lbr: Eagle 5.9.1
    added:
    FDIP32.PAC

2010-04-30
  * st-microelectronics.lbr: Eagle 5.9.0
    added:
    M27C4001.DEV
    DIL32.PAC
    LCC32.PAC
    TSOP32.PAC

2010-04-30
  * micro-cyrod.lbr: Eagle 5.9.0
    added:
    CRD89C51RD1T.DEV
    TQFP64L-10X10X2.0MM.PAC

2010-04-29
  * trafo.lbr: Eagle 5.9.0
    added:
    CTX02-14659.DEV
    SP-67.DEV
    CTX02-14659.PAC
    SP-67.PAC

2010-04-29
  * rohm.lbr: Eagle 5.9.0
    added:
    EMX1.DEV
    IMX1.DEV
    UMX1N.DEV
    EMT6.PAC
    SMT6.PAC
    UMT6.PAC

2010-04-22
  * diode.lbr: Eagle 5.8.1
    added:
    BAT54.DEV
    BAT54A.DEV
    BAT54C.DEV
    BAT54S.DEV

2010-04-13
  * sensor-infratec.lbr: Eagle 5.8.0
    added:
    LME-346-F.DEV
    TO39.PAC

2010-04-12
  * led.lbr: Eagle 5.8.0
    added:
    TLUV5300.DEV
    TLUV5300.PAC

2010-04-08
  * con-faston.lbr: Eagle 5.8.0
    added:
    PIN1-2.DEV
    62221.PAC

2010-04-06
  * xilinx-xc9.lbr: Eagle 5.8.0
    added:
    XC9536_44VQ.DEV
    XC9536_44PLCC.DEV
    PLCC44.PAC
    SQFP-S-10X10-44.PAC

2010-04-01
  * infineon.lbr: Eagle 5.8.0
    added:
    BSP613P.DEV
    BTS716G.DEV
    PG-DSO-20.PAC
    PG-SOT-223.PAC

2010-03-31
  * rectifier.lbr: Eagle 5.8.0
    added:
    B*S.DEV
    DF*S.DEV
    DFS.PAC
    MBS.PAC

2010-03-30
  * silabs.lbr: Eagle 5.8.0
    added:
    SI570.DEV
    SI571.DEV
    8-PIN.PAC

2010-03-29
  * analog-devices.lbr: Eagle 5.8.0
    added:
    AD9854.DEV
    AD9912.DEV

2010-03-29
  * inductors.lbr: Eagle 5.8.0
    added:
    CPH-E13/7/4-1S-6P.DEV
    CPH-E13/7/4-1S-6P.PAC

2010-03-29
  * con-molex.lbr: Eagle 5.8.0
    corrected: 679105700.PAC pins 18-52 moved X -0.3mm

2010-03-10
  * sensor-comus-group.lbr: Eagle 5.8.0
    added:
    CM4400.DEV
    CM4400.PAC

2010-03-10
  * buzzer.lbr: Eagle 5.8.0
    added:
    BMT1205XH7.5.DEV
    BPT-24X.DEV
    BMT1205XH7.5.PAC
    BPT-24X.PAC

2010-03-09
  * memory.lbr: Eagle 5.8.0
    added:
    SST39LF200A.DEV
    SST39LF400A.DEV
    SST39LF800A.DEV
    TSOP48.PAC
    WFBGA48.PAC
    XFBGA48.PAC

2010-03-05
  * con-yamaichi.lbr: Eagle 5.8.0
    added:
    IC51-0644-692.DEV
    IC51-0644-692.PAC

2010-03-04
  * led.lbr: Eagle 5.8.0
    added:
    L-115WEGW-CA.DEV
    DUOLED-A-3MM.PAC

2010-03-04
  * switch.lbr: Eagle 5.8.0
    added:
    2P2T.DEV
    2P2T.PAC

2010-03-04
  * memory.lbr: Eagle 5.8.0
    added:
    IS42S16100B.DEV
    IS42S16100T.DEV
    MBGA60.PAC
    TSOP50-II.PAC

2010-03-03
  * memory.lbr: Eagle 5.8.0
    added:
    SST39VF010.DEV
    SST39VF010B3.DEV
    SST39VF020.DEV
    SST39VF020B3.DEV
    SST39VF040.DEV
    SST39VF040B3.DEV
    SST39VF512.DEV
    PLCC32R.PAC
    TFBGA48.PAC

2010-03-03
  * national-semiconductor.lbr: Eagle 5.8.0
    added:
    DP83848.DEV
    LQFP48.PAC

2010-02-25
  * 74xx-us.lbr: Eagle 5.8.0
    added:
    DHVQFN14.PAC
    SSOP14.PAC
    TSSOP14.PAC

2010-02-25
  * 74xx-eu.lbr: Eagle 5.8.0
    added:
    DHVQFN14.PAC
    SSOP14.PAC
    TSSOP14.PAC

2010-02-22
  * analog-devices.lbr: Eagle 5.7.2
    added:
    AD5280.DEV
    AD5282.DEV

2010-02-18
  * texas.lbr: Eagle 5.7.2
    added:
    CC2531.DEV
    RHA_S-PVQFN-N40.PAC

2010-02-17
  * con-coax.lbr: Eagle 5.7.2
    added:
    PE44121.DEV
    PE44121.PAC

2010-02-15
  * texas.lbr: Eagle 5.7.2
    added:
    MSP430F23.DEV
    MSP430F24*.DEV
    MSP430F24*1.DEV
    RGC_S-PVQFV-N64.PAC

2010-02-12
  * display-kingbright.lbr: Eagle 5.7.1
    added:
    B?56-11*WA.DEV
    B?56-12*WA.DEV
    B?56-13*WA.DEV
    DA56-11.DEV
    DC56-11.DEV
    BX56-12.PAC
    DA56.PAC

2010-02-12
  * transistor-pnp.lbr: Eagle 5.7.1
    added:
    SOT54.PAC
    SOT323-BEC.PAC

2010-02-10
  * microchip.lbr: Eagle 5.7.1
    added:
    PIC16F19*.DEV
    PIC16F193*.DEV
    PIC16F193*?.DEV
    PIC16F193*ML.DEV

2010-02-08
  * con-wenzhou-yihua.lbr: Eagle 5.7.1
    added:
    YH-55-10.DEV
    YH-55-10.PAC

2010-02-04
  * linear-technology.lbr: Eagle 5.7.1
    added:
    LT5598.DEV
    LT6230.DEV
    LT6231.DEV
    LT6232.DEV
    DFN8-3X3.PAC
    QFN24-4X4.PAC
    S8.PAC
    SSOP16.PAC
    TSOT23-6.PAC

2010-02-04
  * fox-electronics.lbr: Eagle 5.7.1
    renamed: RTC72412.SYM to RTC72421.SYM

2010-02-03
  * freescale.lbr: Eagle 5.7.0
    changed: library description

2010-02-03
  * con-jack.lbr: Eagle 5.7.0
    changed description: SPC4077.PAC, SPC4078.PAC

2010-02-02
  * rcl.lbr: Eagle 5.7.0
    added:
    6000-XXXX-RC.PAC

2010-02-02
  * con-leotronics.lbr: Eagle 5.7.0
    corrected: all female connectors mirrored.

2010-02-02
  * con-xmultiple.lbr: Eagle 5.7.0
    added:
    XRJF.DEV
    XRJK*4.DEV
    XRJK*6.DEV
    XRJF-01A-0-D2A-010.PAC
    XRJK-S-01-6-4-0-9M2.PAC
    XRJK-S-01-6-6-0-2G2-NO.PAC

2010-02-01
  * con-tycoelectronics.lbr: Eagle 5.7.0
    added:
    2RJ11-6L-B.DEV
    4RJ11-6L-B.DEV
    6RJ11-6LB.DEV
    RJ11.DEV
    RJ11*2.DEV
    RJ45.DEV
    RJ45*2.DEV
    2RJ11.PAC
    4RJ11.PAC
    6RJ11.PAC
    RJ11-NO_SHIELD.PAC
    RJ11-SHIELD1.PAC
    RJ11-SHIELD2.PAC
    RJ45-NO-SHIELD.PAC
    RJ45-SHIELD1.PAC
    RJ45-SHIELD2.PAC

2010-02-01
  * con-4ucon.lbr: Eagle 5.7.0
    added:
    14867.DEV
    14867.PAC

2010-01-29
  * pot.lbr: Eagle 5.7.0
    added:
    3RP/1610G.DEV
    3RP/1610N.DEV
    3RP/1610G.PAC
    3RP/1610N.PAC

2010-01-27
  * led.lbr: Eagle 5.7.0
    added:
    XPEWHT-.DEV
    CREE_XLAMP.PAC

2010-01-21
  * freescale.lbr: Eagle 5.7.0
    added:
    MC33932.DEV

2010-01-21
  * freescale.lbr: Eagle 5.7.0
    added:
    HSOP44.PAC

2010-01-19
  * recom-international.lbr: Eagle 5.7.0
    added:
    RCD-24*/W.DEV
    RCD-24*/W/X1.DEV
    RCD-24*/W/X2.DEV
    RCD-24*/W/X3.DEV
    RCD-24B.DEV
    RCD-24/W.PAC
    RCD-24/W/X1.PAC
    RCD-24/W/X2.PAC
    RCD-24/W/X3.PAC
    RCD-24B-DIL.PAC
    RCD-24B-SMD.PAC

2010-01-11
  * analog-devices.lbr: Eagle 5.6.4
    added:
    AD8235.DEV
    AD8603.DEV
    AD8607.DEV
    AD8609.DEV
    BGA_CB11.PAC

2010-01-07
  * texas.lbr: Eagle 5.6.4
    corrected connection:
    MSP430F5*.DEV

2010-01-07
  * con-phoenix-smkdsp.lbr: Eagle 5.6.4
    changed pads to drill 1.6mm; diameter 1.8mm:
    SMKDSP_1,5/2.PAC
    SMKDSP_1,5/3.PAC
    SMKDSP_1,5/4.PAC
    SMKDSP_1,5/5.PAC
    SMKDSP_1,5/6.PAC
    SMKDSP_1,5/7.PAC
    SMKDSP_1,5/8.PAC
    SMKDSP_1,5/9.PAC
    SMKDSP_1,5/10.PAC
    SMKDSP_1,5/11.PAC
    SMKDSP_1,5/12.PAC
    SMKDSP_1,5/13.PAC
    SMKDSP_1,5/14.PAC
    SMKDSP_1,5/12.PAC

2010-01-07
  * microchip.lbr: Eagle 5.6.4
    changed smd size to 0.65  1.7 mm at package:
    SO28W.PAC

2009-12-22
  * logo.lbr: Eagle 5.6.3
    added:
    EAGLE-PLC-8MM.PAC
    EAGLE-PLC-10MM.PAC
    EAGLE-PLC-12MM.PAC
    EAGLE-PLC-15MM.PAC
    EAGLE-TOP-8MM.PAC
    EAGLE-TOP-10MM.PAC
    EAGLE-TOP-12MM.PAC
    EAGLE-TOP-15MM.PAC

2009-12-22
  * analog-devices.lbr: Eagle 5.6.3
    added:
    AD210.DEV
    AD215.DEV
    AD526.DEV
    AD623.DEV
    AD625.DEV
    AD627.DEV
    AD711.DEV
    AD712.DEV
    AD744.DEV
    AD745.DEV
    AD746.DEV
    AD797.DEV
    AD807*.DEV
    AD811.DEV
    AD817.DEV
    AD818.DEV
    AD820.DEV
    AD820N.DEV
    AD822.DEV
    AD825.DEV
    AD826.DEV
    AD845.DEV
    AD1985.DEV
    AD7676.DEV
    AD7730.DEV
    AD8001.DEV
    AD8015.DEV
    AD8031.DEV
    AD8033.DEV
    AD8041.DEV
    AD8042.DEV
    AD8065.DEV
    AD8066.DEV
    AD8079.DEV
    AD8519.DEV
    AD8529.DEV
    AD8541.DEV
    AD8542.DEV
    AD8544.DEV
    AD8597.DEV
    AD8599.DEV
    AD8610.DEV
    AD8614.DEV
    AD8620.DEV
    AD8644.DEV
    AD8655.DEV
    AD8656.DEV
    ADA4075-2.DEV
    ADA4627-1CP.DEV
    ADA4627-1R.DEV
    ADA4692-2.DEV
    ADA4692-4.DEV
    ADA4853-1.DEV
    ADA4853-2.DEV
    ADA4853-3RU.DEV
    ADA4853-3VQ.DEV
    ADAU1592.DEV
    ADAV801.DEV
    ADAV803.DEV
    ADAV804.DEV
    ADG411.DEV
    ADG412.DEV
    ADG413.DEV
    ADSP_21368.DEV
    ADSP_21369.DEV
    ADSP_21375.DEV
    ADSP_21462W.DEV
    ADSP_21467.DEV
    ADV7184.DEV
    ADV7194.DEV
    BUF04.DEV
    MAT04.DEV
    AD210.PAC
    AD215.PAC
    BGA_256.PAC
    BGA_324_CSP.PAC
    H08.PAC
    LFCSP8.PAC
    LFCSP8_CP.PAC
    SC70-5.PAC
    SC70-6.PAC
    SOIC16R.PAC
    SOIC20R.PAC
    TSSOP8.PAC

2009-12-22
  * linear.lbr: Eagle 5.6.3
    added:
    OP97.DEV
    OP183.DEV
    OP249.DEV
    OP270.DEV
    OP275.DEV
    HA5024.DEV

2009-12-21
  * supply-dummy.lbr: Eagle 5.6.3
  * special-pad.lbr: Eagle 5.6.3
  * ground-junctions.lbr: Eagle 5.6.3
    deleted: (used layer 53/54)

2009-12-21
  * supply1.lbr: Eagle 5.6.3
    deleted:
    GND-GNDA.DEV
    GND-GNDA.PAC
    Layer 53
    Layer 54

2009-12-14
  * resistor-power.lbr: Eagle 5.6.3
    added:
    AC01.PAC
    AC03.PAC
    AC04.PAC
    AC05.PAC
    AC07.PAC
    AC10.PAC
    CA0001.PAC
    CA0002.PAC
    CA4050.PAC
    CA4055.PAC
    CA4060.PAC
    CA4070.PAC
    CA4080.PAC
    CA4090.PAC
    CA4100.PAC
    CA4150.PAC
    CA4200.PAC
    CA4220.PAC
    CA5050.PAC
    CA5055.PAC
    CA5060.PAC
    CA5070.PAC
    CA5080.PAC
    CA5090.PAC
    CA5100.PAC
    CA5150.PAC
    CA5200.PAC
    CA5220.PAC
    HPS58.PAC
    HPS63.PAC
    HPS68.PAC
    HPS523.PAC
    HPS923.PAC
    HPS932.PAC
    HPS947.PAC
    RS01A.PAC
    RS01M.PAC
    RS1/2.PAC
    RS1/4.PAC
    RS1/8.PAC
    RS002.PAC
    RS02B.PAC
    RS02C.PAC
    RS02C_17-23.PAC
    RS02M.PAC
    RS05_69-70.PAC
    RS007.PAC
    RS10_38-39.PAC
    RWM4X10.PAC
    RWM4X22.PAC
    RWM5X26.PAC
    RWM6X22.PAC
    RWM6X34.PAC
    RWM8X26.PAC
    RWM8X34.PAC
    RWM8X45.PAC
    RWM10X45.PAC
    RWM10X64.PAC
    RWM10X65.PAC

2009-12-11
  * e-sps.lbr: Eagle 5.6.3
    added:
    NS-80.DEV
    NS-80.PAC

2009-12-10
  * e-sps.lbr: Eagle 5.6.3
    added:
    AL2-2DA.DEV
    AL2-2PT-ADP.DEV
    AL2-4EX.DEV
    AL2-4EX-A2.DEV
    AL2-4EYR.DEV
    AL2-4EYT.DEV
    AL2-14MR-D.DEV
    AL2-24MR-A.DEV
    AL2-24MR-D.DEV
    AL2-2DA.PAC
    AL2-2PT-ADP.PAC
    AL2-4EX.PAC
    AL2-4EX-A2.PAC
    AL2-4EYR.PAC
    AL2-4EYT.PAC
    AL2-14MR-D.PAC
    AL2-24MR-A.PAC
    AL2-24MR-D.PAC

2009-12-10
  * linear-technology.lbr: Eagle 5.6.3
    added:
    LT1763.DEV
    LT1763CS8.DEV
    DFN12.PAC
    LT1963EFE.DEV
    TSSOP16.PAC
    TSSOP16EXP.PAC

2009-12-09
  * micro-philips.lbr: Eagle 5.6.3
    added: package variant SO8
    PCA82C250.DEV

2009-12-08
  * u-blox.lbr: Eagle 5.6.3
    added:
    LEON-G100/G200.DEV
    LEON-G100/G200.PAC

2009-12-04
  * analog-devices.lbr: Eagle 5.6.2
    added:
    AD1877.DEV
    AD1890.DEV
    AD1891.DEV
    AD1892.DEV
    AD1953.DEV
    AD1954.DEV
    AD1983.DEV
    DIL28-6.PAC
    SO-28R.PAC

2009-12-04
  * con-phoenix-762.lbr: Eagle 5.6.2
    transferred from con-phoenix-508.lbr:
    GMSTBA2.DEV
    GMSTBA3.DEV
    GMSTBA4.DEV
    GMSTBA6.DEV
    GMSTBA7.DEV
    GMSTBA8.DEV
    GMSTBA9.DEV
    GMSTBA10.DEV
    GMSTBA12.DEV
    GMSTBV2.DEV
    GMSTBV3.DEV
    GMSTBV4.DEV
    GMSTBV5.DEV
    GMSTBV6.DEV
    GMSTBV7.DEV
    GMSTBV8.DEV
    GMSTBV9.DEV
    GMSTBV10.DEV
    GMSTBV12.DEV
    GMSTBA2.PAC
    GMSTBA3.PAC
    GMSTBA4.PAC
    GMSTBA6.PAC
    GMSTBA7.PAC
    GMSTBA8.PAC
    GMSTBA9.PAC
    GMSTBA10.PAC
    GMSTBA12.PAC
    GMSTBV2.PAC
    GMSTBV3.PAC
    GMSTBV4.PAC
    GMSTBV5.PAC
    GMSTBV6.PAC
    GMSTBV7.PAC
    GMSTBV8.PAC
    GMSTBV9.PAC
    GMSTBV10.PAC
    GMSTBV12.PAC
    GMST2H.PAC
    GMST2V.PAC
    GMST3H.PAC
    GMST3V.PAC
    GMST4H.PAC
    GMST4V.PAC
    GMST5H.PAC
    GMST5V.PAC

2009-12-04
  * con-phoenix-508.lbr: Eagle 5.6.2
    transferred to con-phoenix-762.lbr:
    GMSTBA2.DEV
    GMSTBA3.DEV
    GMSTBA4.DEV
    GMSTBA6.DEV
    GMSTBA7.DEV
    GMSTBA8.DEV
    GMSTBA9.DEV
    GMSTBA10.DEV
    GMSTBA12.DEV
    GMSTBV2.DEV
    GMSTBV3.DEV
    GMSTBV4.DEV
    GMSTBV5.DEV
    GMSTBV6.DEV
    GMSTBV7.DEV
    GMSTBV8.DEV
    GMSTBV9.DEV
    GMSTBV10.DEV
    GMSTBV12.DEV
    GMSTBA2.PAC
    GMSTBA3.PAC
    GMSTBA4.PAC
    GMSTBA6.PAC
    GMSTBA7.PAC
    GMSTBA8.PAC
    GMSTBA9.PAC
    GMSTBA10.PAC
    GMSTBA12.PAC
    GMSTBV2.PAC
    GMSTBV3.PAC
    GMSTBV4.PAC
    GMSTBV5.PAC
    GMSTBV6.PAC
    GMSTBV7.PAC
    GMSTBV8.PAC
    GMSTBV9.PAC
    GMSTBV10.PAC
    GMSTBV12.PAC
    GMST2H.PAC
    GMST2V.PAC
    GMST3H.PAC
    GMST3V.PAC
    GMST4H.PAC
    GMST4V.PAC
    GMST5H.PAC
    GMST5V.PAC

2009-12-03
  * special-drill.lbr: Eagle 5.6.2
    added:
    PAD_0.1800.PAC

2009-12-02
  * linx.lbr: Eagle 5.6.2
    added:
    TRM-*-LT.DEV
    TRM-XXX-LT.PAC

2009-12-02
  * linear.lbr: Eagle 5.6.2
    added:
    TL331.DEV
    DBV-R-PDSO-G5.PAC

2009-12-02
  * diode.lbr: Eagle 5.6.2
    added:
    1N581*.DEV
    DO41-7.6.PAC

2009-12-01
  * eib-busch-jaeger.lbr: Eagle 5.6.2
    added:
    6010-25.DEV
    6020-XX.DEV
    6021-XX.DEV
    6108-U.DEV
    6109-U.DEV
    6110-U-101.DEV
    6114-U.DEV
    6115-XX-101.DEV
    6116-XX-101.DEV
    6117-XX-101.DEV
    6119/20.DEV
    6119/40.DEV
    6122-XX.DEV
    6123-XX.DEV
    6123USB-XX.DEV
    6124-XX.DEV
    6125-XX.DEV
    6126-XX.DEV
    6127-XX.DEV
    6127MF-XX.DEV
    6128-XX.DEV
    6129-XX.DEV
    6131-XX-102.DEV
    6132-XX-102.DEV
    6132-XX-102M.DEV
    6133-XX-101.DEV
    6133USB-XX.DEV
    6134-XX-102.DEV
    6134/10.DEV
    6135-XX-102.DEV
    6136-XX.DEV
    6136/30M.DEV
    6136/40-101.DEV
    6136/100C.DEV
    6136/100CB.DEV
    6136/100M.DEV
    6140-101.DEV
    6144/10-101.DEV
    6146.DEV
    6146-101.DEV
    6151EB.DEV
    6152EB-101.DEV
    6153EB.DEV
    6155EB-101.DEV
    6156EB.DEV
    6157EB.DEV
    6158EB.DEV
    6164/40.DEV
    6164U.DEV
    6172AG-101.DEV
    6173AG-101.DEV
    6174/10.DEV
    6174/11.DEV
    6174/12.DEV
    6174/13.DEV
    6174/14.DEV
    6174/15.DEV
    6174/16.DEV
    6174/17.DEV
    6174/18.DEV
    6174/19.DEV
    6174/20.DEV
    6174/21.DEV
    6179-XX.DEV
    6180-102.DEV
    6180/10.DEV
    6180/11.DEV
    6181-101.DEV
    6186/20.DEV
    6186/30.DEV
    6186USB.DEV
    6187-103.DEV
    6188/13.DEV
    6188/14.DEV
    6188/15.DEV
    6188/16.DEV
    6188/17.DEV
    6188/18.DEV
    6190/10.DEV
    6190/40-101.DEV
    6193/32.DEV
    6194/11.DEV
    6194/12.DEV
    6194/13.DEV
    6194/14.DEV
    6194/15.DEV
    6194/16.DEV
    6194/17.DEV
    6195/21.DEV
    6195/22.DEV
    6195/24.DEV
    6195/25.DEV
    6195/26.DEV
    6196/20.DEV
    6196/40-101.DEV
    6196/41-101.DEV
    6196/42.DEV
    6196/43.DEV
    6196/80.DEV
    6196/82.DEV
    6197/22.DEV
    6197/40.DEV
    6198-101.DEV
    6198/JA.DEV
    6198ST.DEV
    6321-XX.DEV
    6322-XX-101.DEV
    6323-XX.DEV
    6324-XX.DEV
    6325-XX.DEV
    6326-XX-101.DEV
    6327-XX.DEV
    6010-25.PAC
    6020-XX.PAC
    6021-XX.PAC
    6108-U.PAC
    6109-U.PAC
    6110-U-101.PAC
    6114-U.PAC
    6115-XX-101.PAC
    6116-XX-101.PAC
    6117-XX-101.PAC
    6119/20.PAC
    6119/40.PAC
    6122-XX.PAC
    6123-XX.PAC
    6123USB-XX.PAC
    6124-XX.PAC
    6125-XX.PAC
    6126-XX.PAC
    6127-XX.PAC
    6127MF-XX.PAC
    6128-XX.PAC
    6129-XX.PAC
    6131-XX-102.PAC
    6132-XX-102.PAC
    6132-XX-102M.PAC
    6133-XX-101.PAC
    6133USB-XX.PAC
    6134-XX-102.PAC
    6134/10.PAC
    6135-XX-102.PAC
    6136-XX.PAC
    6136/30M.PAC
    6136/40-101.PAC
    6136/100C.PAC
    6136/100CB.PAC
    6136/100M.PAC
    6140-101.PAC
    6144/10-101.PAC
    6146.PAC
    6146-101.PAC
    6151EB.PAC
    6152EB-101.PAC
    6153EB.PAC
    6155EB-101.PAC
    6156EB.PAC
    6157EB.PAC
    6158EB.PAC
    6164/40.PAC
    6164U.PAC
    6172AG-101.PAC
    6173AG-101.PAC
    6174/10.PAC
    6174/11.PAC
    6174/12.PAC
    6174/13.PAC
    6174/14.PAC
    6174/15.PAC
    6174/16.PAC
    6174/17.PAC
    6174/18.PAC
    6174/19.PAC
    6174/20.PAC
    6174/21.PAC
    6179-XX.PAC
    6180-102.PAC
    6180/10.PAC
    6180/11.PAC
    6181-101.PAC
    6186/10.PAC
    6186/20.PAC
    6186/30.PAC
    6186AG.PAC
    6186USB.PAC
    6187-103.PAC
    6188/13.PAC
    6188/14.PAC
    6188/15.PAC
    6188/16.PAC
    6188/17.PAC
    6188/18.PAC
    6190/10.PAC
    6190/40-101.PAC
    6191/10.PAC
    6193/32.PAC
    6194/11.PAC
    6194/12.PAC
    6194/13.PAC
    6194/14.PAC
    6194/15.PAC
    6194/16.PAC
    6194/17.PAC
    6194/23.PAC
    6194/27.PAC
    6195/21.PAC
    6195/22.PAC
    6195/24.PAC
    6195/25.PAC
    6195/26.PAC
    6196/20.PAC
    6196/40-101.PAC
    6196/41-101.PAC
    6196/42.PAC
    6196/43.PAC
    6196/80.PAC
    6196/82.PAC
    6197/11-102.PAC
    6197/20.PAC
    6198-101.PAC
    6198/JA.PAC
    6198ST.PAC
    6321-XX.PAC
    6322-XX-101.PAC
    6323-XX.PAC
    6324-XX.PAC
    6325-XX.PAC
    6326-XX-101.PAC
    6327-XX.PAC

2009-12-01
  * e-sps.lbr: Eagle 5.6.2
    added:
    S7-1200_AC/DC/RELAIS.DEV
    S7-1200_DC/DC/DC.DEV
    SB_1223_DC/DC.DEV
    SB_1232AO1.DEV
    SM1222_DO_16X24VDC.DEV
    SM1222_DO_16XRELAIS.DEV
    SM_1221_DI_8X24VDC.DEV
    SM_1221_DI_16X24VDC.DEV
    SM_1223_DI-16X24VDC_DO-16X24VDC.DEV
    SM_1223_DI-16X24VDC_DO-16XRELAIS.DEV
    SM_1231_AI4X13BIT.DEV
    SM_1232_AQ2X14BIT.DEV
    SM_1234_AI4X13BIT-AQ2X14BIT.DEV
    S7-1200_AC/DC/RELAIS.PAC
    S7-1200_DC/DC/DC.PAC
    SB_1223_DC/DC.PAC
    SB_1232AO1.PAC
    SM1222_DO_16X24VDC.PAC
    SM1222_DO_16XRELAIS.PAC
    SM_1221_DI_8X24VDC.PAC
    SM_1221_DI_16X24VDC.PAC
    SM_1223_DI-16X24VDC_DO-16X24VDC.PAC
    SM_1223_DI-16X24VDC_DO-16XRELAIS.PAC
    SM_1231_AI4X13BIT.PAC
    SM_1232_AQ2X14BIT.PAC
    SM_1234_AI4X13BIT-AQ2X14BIT.PAC

2009-11-30
  * resistor-power.lbr: Eagle 5.6.2
    added:
    RMG100.DEV
    TO-247-2H.PAC
    TO-247-2V.PAC

2009-11-27
  * e-steckverbinder.lbr: Eagle 5.6.2
    set PREFIX: STECKVERBINDER_5-POL.DEV

2009-11-27
  * atmel.lbr: Eagle 5.6.2
    added:
    AT45DB642D.DEV
    28T-TSOP-1.PAC

2009-11-25
  * murata-filter.lbr: Eagle 5.6.2
    added:
    NFM.DEV
    NFM3DC.PAC
    NFM21C.PAC

2009-11-25
  * analog-devices.lbr: Eagle 5.6.2
    added:
    ADUM1300.DEV
    ADUM1301.DEV

2009-11-25
  * texas.lbr: Eagle 5.6.2
    added:
    SN74LVCR162245A.DEV
    DL_R-PDSO-G48.PAC

2009-11-24
  * analog-devices.lbr: Eagle 5.6.2
    added:
    AD1836.DEV

2009-11-23
  * transistor-fet.lbr: Eagle 5.6.2
    added:
    2SJ109.DEV
    2SK389.DEV
    2-10M1A.PAC

2009-11-17
  * allegro.lbr: Eagle 5.6.2
    added:
    A3982.DEV

2009-11-17
  * atmel.lbr: Eagle 5.6.2
    added:
    ATMEGA325P.DEV
    64M1.PAC

2009-11-17
  * allegro.lbr: Eagle 5.6.2
    added:
    A4983.DEV
    QFN28ET.PAC

2009-11-09
  * texas.lbr: Eagle 5.6.1
    added:
    TUSB2046BIRHB.DEV
    TUSB2046B.DEV
    VF_S-PQFP-G32.PAC
    RHB_S-PQFP-N32.PAC

2009-10-22
  * texas.lbr: Eagle 5.6.1
    added:
    TMS320VC5509.DEV

2009-10-22
  * texas.lbr: Eagle 5.6.1
    added:
    TMS320VC5509A.DEV
    GHH_S-PBGA-N179.PAC

2009-10-22
  * analog-devices.lbr: Eagle 5.6.1
    added:
    SSM2165.DEV
    SSM2166.DEV
    SSM2167.DEV
    SO14.PAC

2009-10-19
  * micro-intel.lbr: Eagle 5.6.1
    added:
    HL-PBGA304.PAC
    HL-PBGA352.PAC
    HL-PBGA432.PAC
    PBGA196.PAC
    PBGA208.PAC
    PBGA241.PAC
    PBGA256-17.PAC
    PBGA256-27.PAC
    PBGA304.PAC
    PBGA324.PAC
    PBGA421.PAC
    PBGA468.PAC
    PBGA544.PAC

2009-10-19
  * texas.lbr: Eagle 5.6.1
    added:
    OMAP-L138ZCE.DEV
    OMAP-L138ZWT.DEV
    ZCE_S-PBGA-N361.PAC
    ZEN_S-PBGA-N196.PAC
    ZWT_S-PBGA-N361.PAC

2009-10-15
  * rohm.lbr: Eagle 5.6.1
    added:
    BD623*F.DEV
    BD623*FP.DEV
    BD623*HFP.DEV
    BD6232FP.DEV
    HRP7.PAC
    HSOP25.PAC
    HSOP28.PAC
    SOP8.PAC

2009-10-14
  * texas.lbr: Eagle 5.6.1
    added:
    ADS1274.DEV

2009-10-12
  * gennum.lbr: Eagle 5.6.1
    added:
    GS2970.DEV
    GS2974.DEV
    GS4910B.DEV
    GS4911B.DEV
    GS4915.DEV
    LBGA100.PAC
    QFN16-4X4.PAC
    QFN40-6X6.PAC
    QFN64-9X9.PAC

2009-10-12
  * altera-stratix-iv.lbr: Eagle 5.6.1
    added:
    EP4S40G2F40ES1.DEV
    EP4S40G5H40ES1.DEV
    EP4S100G2F40ES1.DEV
    EP4S100G5F45ES1.DEV
    EP4S100G5H40ES1.DEV
    EP4SE230F29.DEV
    EP4SE360F35.DEV
    EP4SE360H29.DEV
    EP4SE530F43.DEV
    EP4SE530H35.DEV
    EP4SE530H40.DEV
    EP4SGX70DF29.DEV
    EP4SGX70HF35.DEV
    EP4SGX110DF29.DEV
    EP4SGX110FF35.DEV
    EP4SGX110HF35.DEV
    EP4SGX180DF29.DEV
    EP4SGX180FF35.DEV
    EP4SGX180HF35.DEV
    EP4SGX180KF40.DEV
    EP4SGX230DF29.DEV
    EP4SGX230FF35.DEV
    EP4SGX230HF35.DEV
    EP4SGX230KF40.DEV
    EP4SGX290FF35.DEV
    EP4SGX290FH29.DEV
    EP4SGX290HF35.DEV
    EP4SGX290KF40.DEV
    EP4SGX290KF43.DEV
    EP4SGX360FF35.DEV
    EP4SGX360FH29.DEV
    EP4SGX360HF35.DEV
    EP4SGX360KF40.DEV
    EP4SGX360KF43.DEV
    EP4SGX530HH35.DEV
    EP4SGX530KF43.DEV
    EP4SGX530KH40.DEV
    EP4SGX530NF45.DEV
    FBGA780.PAC
    FBGA1152.PAC
    FBGA1517.PAC
    FBGA1760.PAC
    FBGA1932.PAC

2009-10-12
  * burr-brown.lbr: Eagle 5.6.1
    added:
    INA163.DEV
    INA217.DEV
    PGA2500.DEV
    DB_R-PDSO-G28.PAC
    DW_RPDSO-G16.PAC

2009-10-12
  * linear.lbr: Eagle 5.6.1
    added:
    LM*18.DEV
    OPA725.DEV
    OPA726.DEV
    OPA2725.DEV
    OPA2726.DEV
    SA5534.DEV
    D_R-PDSO-G8.PAC
    LCCC20.PAC
    LCCC28.PAC
    PS_R-PDSO-G8.PAC

2009-10-12
  * texas.lbr: Eagle 5.6.1
    added:
    ADS1210.DEV
    ADS1211.DEV
    ADS1211E.DEV
    ADS1271.DEV
    ADS1278.DEV
    DIT4192-H.DEV
    DIT4192-S.DEV
    DIX4192.DEV
    ISO1050.DEV
    OMAP-L137.DEV
    PCM1792.DEV
    PCM1796.DEV
    PCM1804.DEV
    PCM4204.DEV
    PCM4220.DEV
    PCM4222.DEV
    SN65LVD*125.DEV
    SRC4382.DEV
    SRC4392.DEV
    TAS5261.DEV
    TL7660.DEV
    TMS320C64X_DSP.DEV
    TMS320C6474.DEV
    TMS320C6720*DH.DEV
    TMS320C6720RFP.DEV
    TMS320C6720RFP-EXPAD.DEV
    DBT_R-PDSO-G38.PAC
    DB_R-PDSO-G28.PAC
    DGK_S-PDSO-G8.PAC
    DKD_R-PDSO-G36.PAC
    DUB-R-PDSO-G8.PAC
    GDH_S-PBGA-N256.PAC
    GTS_S-PBGA-N288.PAC
    PAP_S-PQFP-G64.PAC
    PDIP-T24.PAC
    PDIP-T28.PAC
    PFB_S-PQFP-G48.PAC
    RFP_S-PQFP-G144-EXP.PAC
    RFP_S-PQFP-G144-EXPAD.PAC
    S-PQFP-G48.PAC
    TSSOP16.PAC
    ZDH_S-PBGA-N256.PAC
    ZKB_S-PBGA-N256.PAC
    ZUN_SPBGA-N561.PAC

2009-10-08
  * linear.lbr: Eagle 5.6.1
    added:
    OPA22*.DEV
    OPA222*.DEV
    OPA422*.DEV
    OPA2134.DEV
    OPA4134.DEV

2009-10-08
  * opto-trans-siemens.lbr: Eagle 5.6.1
    added:
    SFH303.DEV
    SFH303.PAC

2009-09-28
  * con-lumberg.lbr: Eagle 5.6.0
    corrected PIN/PAD connection:
    NEB1R.DEV
    NEB1R.PAC
    NEBJ21R.DEV
    NEBJ21R.PAC
    NEBJ21.DEV
    NEBJ21.PAC
    NEBJ25R.DEV
    NEBJ25R.PAC
    NEBJ25.DEV
    NEBJ25.PAC

2009-09-24
  * linear.lbr: Eagle 5.6.0
    corrected connection: DAC0808D.DEV

2009-09-24
  * con-molex.lbr: Eagle 5.6.0
    added:
    105081-0001.DEV
    105081-0001.PAC

2009-09-16
  * microchip.lbr: Eagle 5.6.0
    added:
    PIC16F688.DEV
    QFN16-4X4.PAC

2009-09-11
  * texas.lbr: Eagle 5.6.0
    added:
    TPS6108*.DEV

2009-09-10
  * texas.lbr: Eagle 5.6.0
    added:
    MSP430FG437.DEV

2009-08-26
  * nrj-semiconductor.lbr: Eagle 5.6.0
    added:
    NJU9207B.DEV
    qfp80-C1.PAC

2009-08-25
  * con-vg.lbr: Eagle 5.6.0
    added:
    FH11.DEV
    FH11.PAC

2009-08-25
  * infineon.lbr: Eagle 5.6.0
    added:
    TLE5205-2.DEV
    P-TO220-7-11.PAC
    P-TO220-7-12.PAC
    P-TO263-7-1.PAC

2009-08-17
  * transistor.lbr: Eagle 5.6.0
    corrected:
    *-NPN.DEV BC635, BC639, BC639 Packagevariant TO92-ECB

2009-08-13
  * allegro.lbr: Eagle 5.6.0
    added:
    A12*?.DEV
    A13*?.DEV
    A136*.DEV
    SIP3-UA.PAC
    SIP4-KT.PAC
    SOT23-W.PAC

2009-08-12
  * con-molex.lbr: Eagle 5.6.0
    added:
    87438-02.DEV
    87438-03.DEV
    87438-04.DEV
    87438-05.DEV
    87438-06.DEV
    87438-07.DEV
    87438-08.DEV
    87438-09.DEV
    87438-10.DEV
    87438-11.DEV
    87438-12.DEV
    87438-13.DEV
    87438-14.DEV
    87438-15.DEV
    87438-02.PAC
    87438-03.PAC
    87438-04.PAC
    87438-05.PAC
    87438-06.PAC
    87438-07.PAC
    87438-08.PAC
    87438-09.PAC
    87438-10.PAC
    87438-11.PAC
    87438-12.PAC
    87438-13.PAC
    87438-14.PAC
    87438-15.PAC

2009-08-06
  * led.lbr: Eagle 5.6.0
    added:
    F50360.DEV
    LZ1-00WW03.DEV
    LZ1-00WW05.DEV
    LZ4-00WW10.DEV
    LZC-00CW40.DEV
    W724C0.DEV
    W49180.DEV
    X42180.DEV
    X42182.DEV
    F50360.PAC
    LZ1-00WW03.PAC
    LZ4-00WW10.PAC
    LZC-00CW40.PAC
    W724C0.PAC
    Z-POWER-LED-DOME-TYPE.PAC
    Z-POWER-LED-PCB-TYPE.PAC

2009-08-06
  * texas.lbr: Eagle 5.6.0
    added:
    TPA3123D2.DEV
    PWP-TSSOP24.PAC

2009-08-03
  * advanced-test-technologies.lbr: Eagle 5.6.0
    added:
    64POL-SOCKED.DEV
    QFP-SOCKED-64.PAC

2009-08-03
  * relay.lbr: Eagle 5.6.0
    added:
    9802.DEV
    9814.DEV
    9852.DEV
    9802-00.PAC
    9802-20.PAC
    9814-00.PAC
    9814-20.PAC
    9852-00.PAC
    9852-20.PAC

2009-08-03
  * analog-devices.lbr: Eagle 5.6.0
    added:
    ADG608.DEV
    ADG609.DEV
    ADG658.DEV
    ADG659.DEV
    ADG1408YCPZ.DEV
    ADG1408YRUZ.DEV
    ADG1409YCPZ.DEV
    ADG1409YRUZ.DEV
    QSOP16.PAC
    TSSOP16.PAC
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

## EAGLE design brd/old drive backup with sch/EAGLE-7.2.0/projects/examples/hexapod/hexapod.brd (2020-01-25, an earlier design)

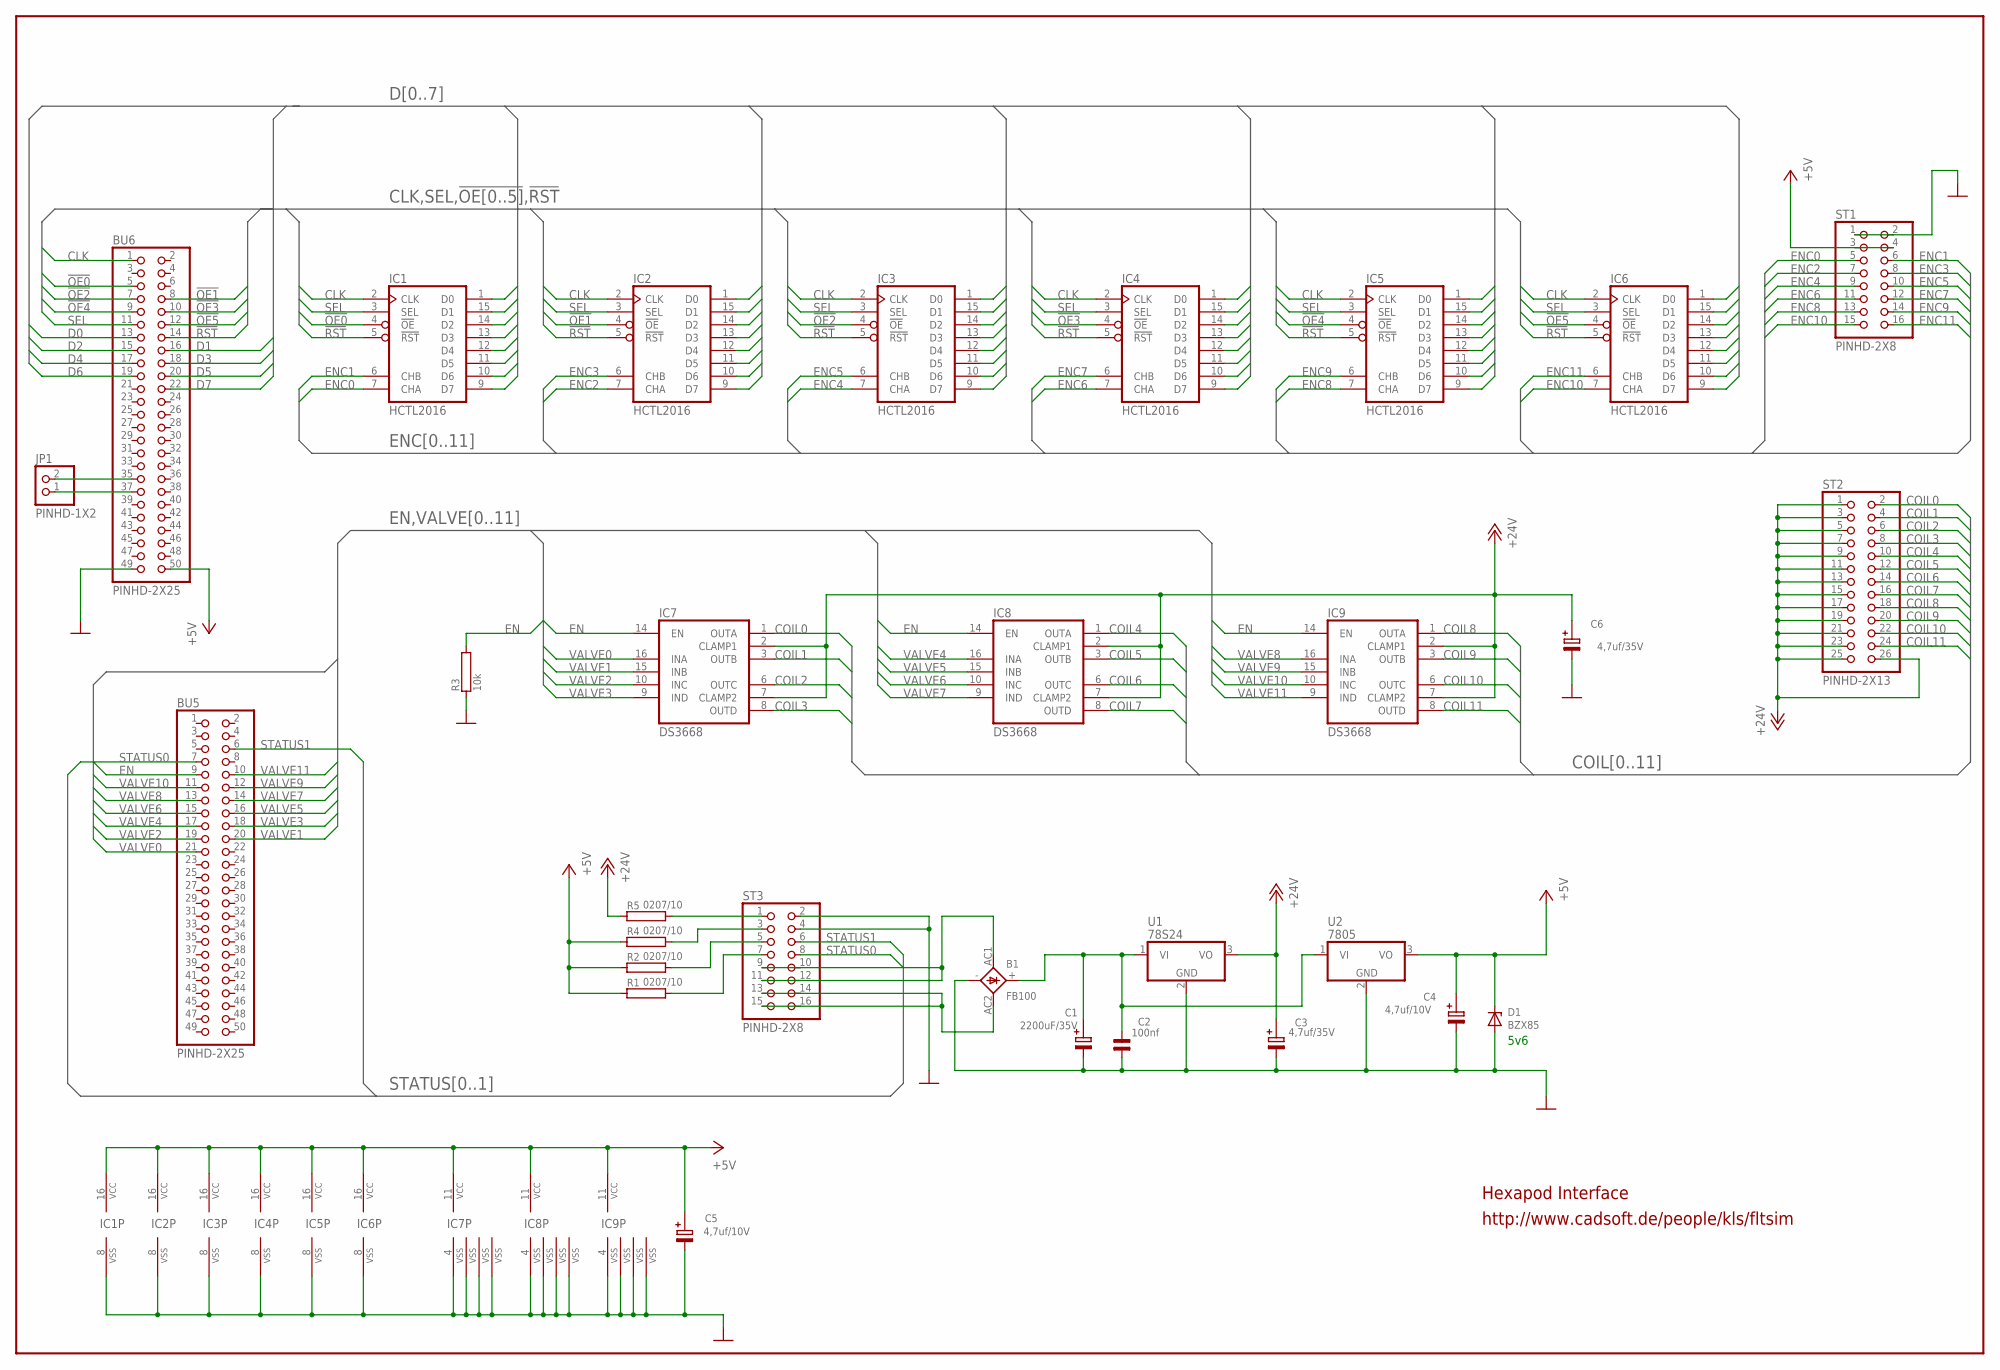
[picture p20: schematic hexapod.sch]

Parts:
B1: FB100
BU5, BU6: PINHD-2X25; 2X25
C1: 2200uF/35V; E35-16
C2: 100nf; C5B2,5A
C3, C6: 4,7uf/35V; E2,5-5
C4, C5: 4,7uf/10V; E2,5-5
D1: BZX85; DO41Z10
IC1, IC2, IC3, IC4, IC5, IC6: HCTL2016; DIL-16
IC7, IC8, IC9: DS3668; DIL-16
JP1: PINHD-1X2; 1X02
R1, R2, R4, R5: 0207/10
R3: 10k; 0207/10@1
ST1, ST3: PINHD-2X8; ML16
ST2: PINHD-2X13; ML26
U1: 78S24; TO220H
U2: 7805; TO220H

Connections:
!OE0: BU6.5, IC1.4 (!OE)
!OE1: BU6.8, IC2.4 (!OE)
!OE2: BU6.7, IC3.4 (!OE)
!OE3: BU6.10, IC4.4 (!OE)
!OE4: BU6.9, IC5.4 (!OE)
!OE5: BU6.12, IC6.4 (!OE)
!RST: BU6.14, IC1.5 (!RST), IC2.5 (!RST), IC3.5 (!RST), IC4.5 (!RST), IC5.5 (!RST), IC6.5 (!RST)
+5V: BU6.50, C4.+, C5.+, D1.K, IC1.16 (VCC), IC2.16 (VCC), IC3.16 (VCC), IC4.16 (VCC), IC5.16 (VCC), IC6.16 (VCC), IC7.11 (VCC), IC8.11 (VCC), IC9.11 (VCC), R1.1, R2.1, R4.1, ST1.3, ST1.4, U2.3 (VO)
+24V: C3.+, C6.+, IC7.2 (CLAMP1), IC7.7 (CLAMP2), IC8.2 (CLAMP1), IC8.7 (CLAMP2), IC9.2 (CLAMP1), IC9.7 (CLAMP2), R5.1, ST2.1, ST2.3, ST2.5, ST2.7, ST2.9, ST2.11, ST2.13, ST2.15, ST2.17, ST2.19, ST2.21, ST2.23, ST2.25, ST2.26, U1.3 (VO)
AC1: B1.AC1, ST3.9, ST3.10, ST3.11, ST3.12
AC2: B1.AC2, ST3.13, ST3.14, ST3.15, ST3.16
CLK: BU6.1, IC1.2 (CLK), IC2.2 (CLK), IC3.2 (CLK), IC4.2 (CLK), IC5.2 (CLK), IC6.2 (CLK)
COIL0: IC7.1 (OUTA), ST2.2
COIL1: IC7.3 (OUTB), ST2.4
COIL2: IC7.6 (OUTC), ST2.6
COIL3: IC7.8 (OUTD), ST2.8
COIL4: IC8.1 (OUTA), ST2.10
COIL5: IC8.3 (OUTB), ST2.12
COIL6: IC8.6 (OUTC), ST2.14
COIL7: IC8.8 (OUTD), ST2.16
COIL8: IC9.1 (OUTA), ST2.18
COIL9: IC9.3 (OUTB), ST2.20
COIL10: IC9.6 (OUTC), ST2.22
COIL11: IC9.8 (OUTD), ST2.24
D0: BU6.13, IC1.1 (D0), IC2.1 (D0), IC3.1 (D0), IC4.1 (D0), IC5.1 (D0), IC6.1 (D0)
D1: BU6.16, IC1.15 (D1), IC2.15 (D1), IC3.15 (D1), IC4.15 (D1), IC5.15 (D1), IC6.15 (D1)
D2: BU6.15, IC1.14 (D2), IC2.14 (D2), IC3.14 (D2), IC4.14 (D2), IC5.14 (D2), IC6.14 (D2)
D3: BU6.18, IC1.13 (D3), IC2.13 (D3), IC3.13 (D3), IC4.13 (D3), IC5.13 (D3), IC6.13 (D3)
D4: BU6.17, IC1.12 (D4), IC2.12 (D4), IC3.12 (D4), IC4.12 (D4), IC5.12 (D4), IC6.12 (D4)
D5: BU6.20, IC1.11 (D5), IC2.11 (D5), IC3.11 (D5), IC4.11 (D5), IC5.11 (D5), IC6.11 (D5)
D6: BU6.19, IC1.10 (D6), IC2.10 (D6), IC3.10 (D6), IC4.10 (D6), IC5.10 (D6), IC6.10 (D6)
D7: BU6.22, IC1.9 (D7), IC2.9 (D7), IC3.9 (D7), IC4.9 (D7), IC5.9 (D7), IC6.9 (D7)
EN: BU5.9, IC7.14 (EN), IC8.14 (EN), IC9.14 (EN), R3.2
ENC0: IC1.7 (CHA), ST1.5
ENC1: IC1.6 (CHB), ST1.6
ENC2: IC2.7 (CHA), ST1.7
ENC3: IC2.6 (CHB), ST1.8
ENC4: IC3.7 (CHA), ST1.9
ENC5: IC3.6 (CHB), ST1.10
ENC6: IC4.7 (CHA), ST1.11
ENC7: IC4.6 (CHB), ST1.12
ENC8: IC5.7 (CHA), ST1.13
ENC9: IC5.6 (CHB), ST1.14
ENC10: IC6.7 (CHA), ST1.15
ENC11: IC6.6 (CHB), ST1.16
GND: B1.-, BU6.49, C1.-, C2.1, C3.-, C4.-, C5.-, C6.-, D1.A, IC1.8 (VSS), IC2.8 (VSS), IC3.8 (VSS), IC4.8 (VSS), IC5.8 (VSS), IC6.8 (VSS), IC7.4 (VSS), IC7.5 (VSS), IC7.12 (VSS), IC7.13 (VSS), IC8.4 (VSS), IC8.5 (VSS), IC8.12 (VSS), IC8.13 (VSS), IC9.4 (VSS), IC9.5 (VSS), IC9.12 (VSS), IC9.13 (VSS), R3.1, ST1.1, ST1.2, ST3.2, ST3.4, U1.2 (GND), U2.2 (GND)
unnamed: R5.2, ST3.1
unnamed: R4.2, ST3.3
unnamed: R2.2, ST3.5
unnamed: R1.2, ST3.7
unnamed: BU6.35, JP1.2
unnamed: BU6.37, JP1.1
SEL: BU6.11, IC1.3 (SEL), IC2.3 (SEL), IC3.3 (SEL), IC4.3 (SEL), IC5.3 (SEL), IC6.3 (SEL)
STATUS0: BU5.7, ST3.8
STATUS1: BU5.6, ST3.6
VALVE0: BU5.21, IC7.16 (INA)
VALVE1: BU5.20, IC7.15 (INB)
VALVE2: BU5.19, IC7.10 (INC)
VALVE3: BU5.18, IC7.9 (IND)
VALVE4: BU5.17, IC8.16 (INA)
VALVE5: BU5.16, IC8.15 (INB)
VALVE6: BU5.15, IC8.10 (INC)
VALVE7: BU5.14, IC8.9 (IND)
VALVE8: BU5.13, IC9.16 (INA)
VALVE9: BU5.12, IC9.15 (INB)
VALVE10: BU5.11, IC9.10 (INC)
VALVE11: BU5.10, IC9.9 (IND)
VIN: B1.+, C1.+, C2.2, U1.1 (VI), U2.1 (VI)

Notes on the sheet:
Hexapod Interface
5v6
http://www.cadsoft.de/people/kls/fltsim

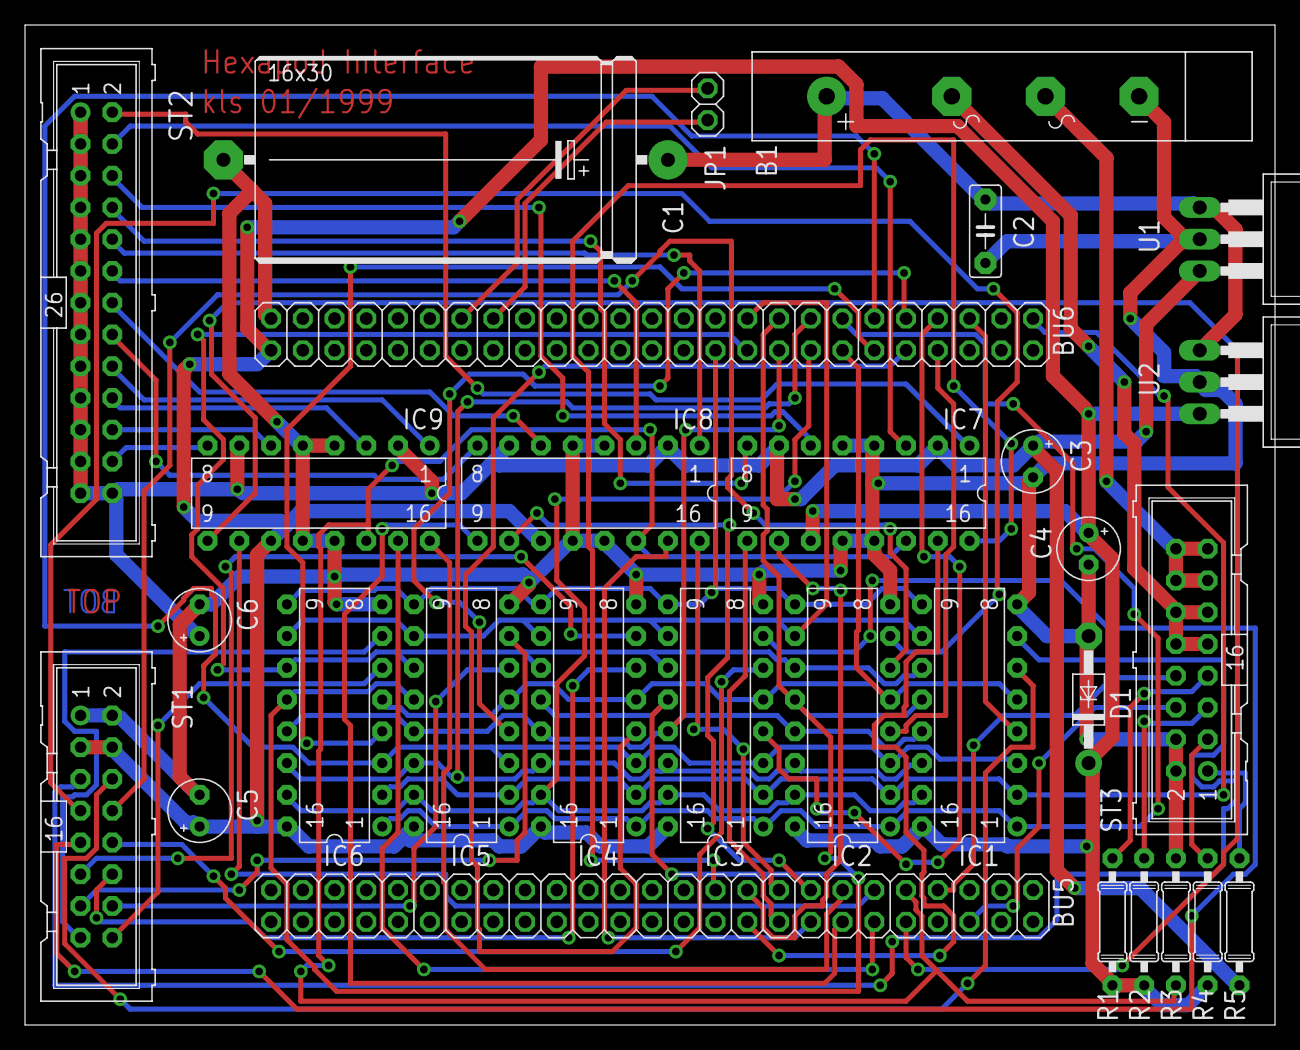
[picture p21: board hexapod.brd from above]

Board: 2 copper layers, 100.0 x 80.0 mm, 30 parts (0 on the bottom side), 68 nets.

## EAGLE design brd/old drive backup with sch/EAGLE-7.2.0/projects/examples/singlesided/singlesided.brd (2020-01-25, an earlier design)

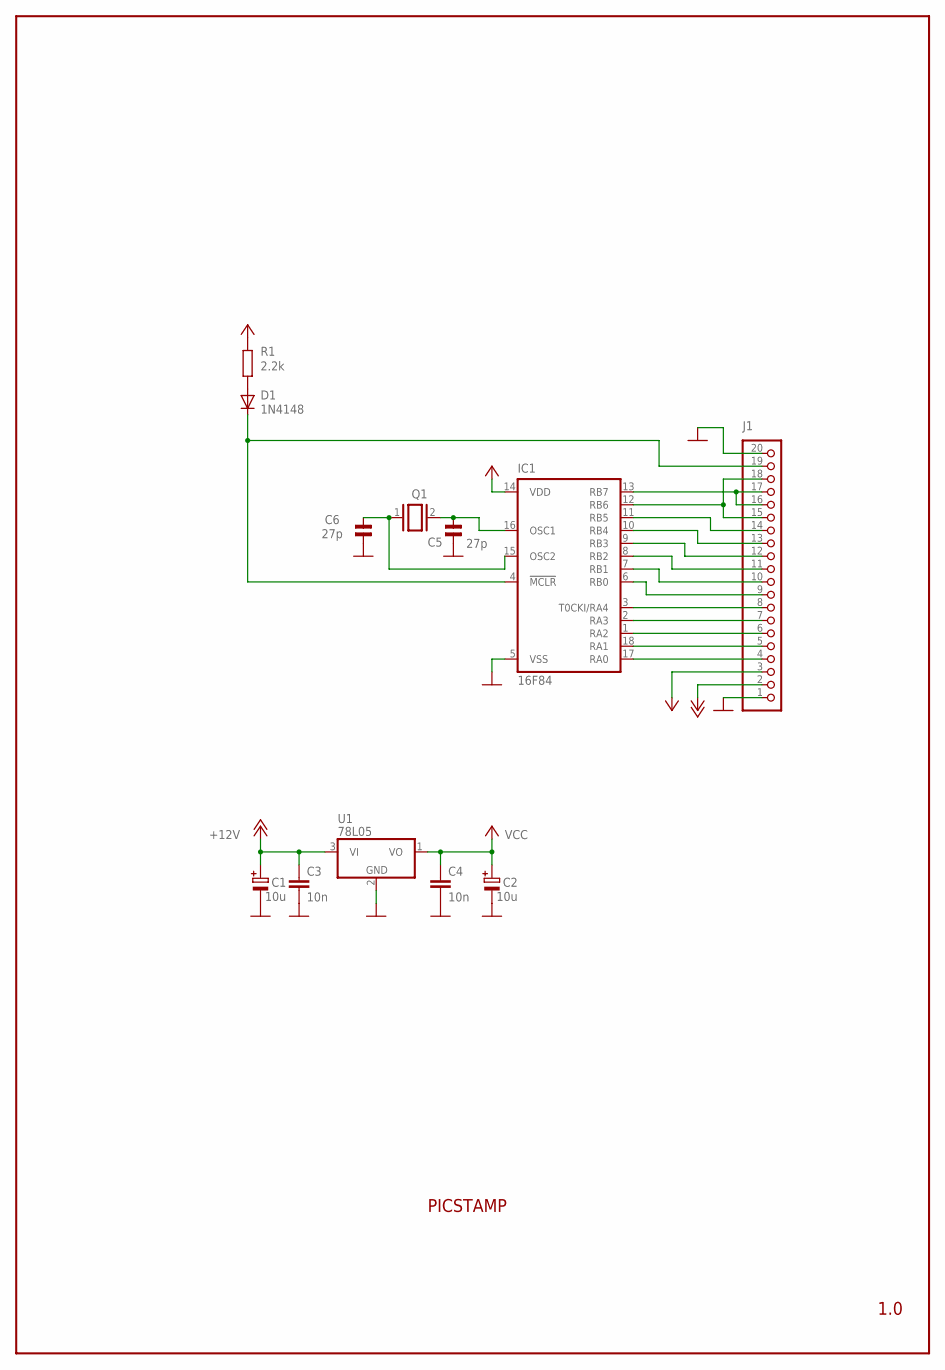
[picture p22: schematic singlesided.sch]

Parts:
C1, C2: 10u; E2,5-6
C3, C4: 10n; C025-025X050
C5, C6: 27p; C2,5-2
D1: 1N4148; DO35-10
IC1: 16F84; DIL18
J1: PINHD-1X20; 1X20
Q1: XTAL/S; QS
R1: 2.2k; 0207/10
U1: 78L05; TO92

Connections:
+12V: C1.+, C3.2, J1.2, U1.3 (VI)
A0: IC1.17 (RA0), J1.4
A1: IC1.18 (RA1), J1.5
A2: IC1.1 (RA2), J1.6
A3: IC1.2 (RA3), J1.7
A4: IC1.3 (T0CKI/RA4), J1.8
B0: IC1.6 (RB0), J1.9
B1: IC1.7 (RB1), J1.10
B2: IC1.8 (RB2), J1.11
B3: IC1.9 (RB3), J1.12
B4: IC1.10 (RB4), J1.13
B5: IC1.11 (RB5), J1.14
B6: IC1.12 (RB6), J1.15, J1.18
B7: IC1.13 (RB7), J1.16, J1.17
GND: C1.-, C2.-, C3.1, C4.1, C5.1, C6.1, IC1.5 (VSS), J1.1, J1.20, U1.2 (GND)
unnamed: D1.K (C), IC1.4 (!MCLR), J1.19
unnamed: D1.A, R1.1
unnamed: C5.2, IC1.16 (OSC1), Q1.2
unnamed: C6.2, IC1.15 (OSC2), Q1.1
VCC: C2.+, C4.2, IC1.14 (VDD), J1.3, R1.2, U1.1 (VO)

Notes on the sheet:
PICSTAMP
1.0

Board: 2 copper layers, 12 parts (0 on the bottom side), 20 nets, no tracks yet.

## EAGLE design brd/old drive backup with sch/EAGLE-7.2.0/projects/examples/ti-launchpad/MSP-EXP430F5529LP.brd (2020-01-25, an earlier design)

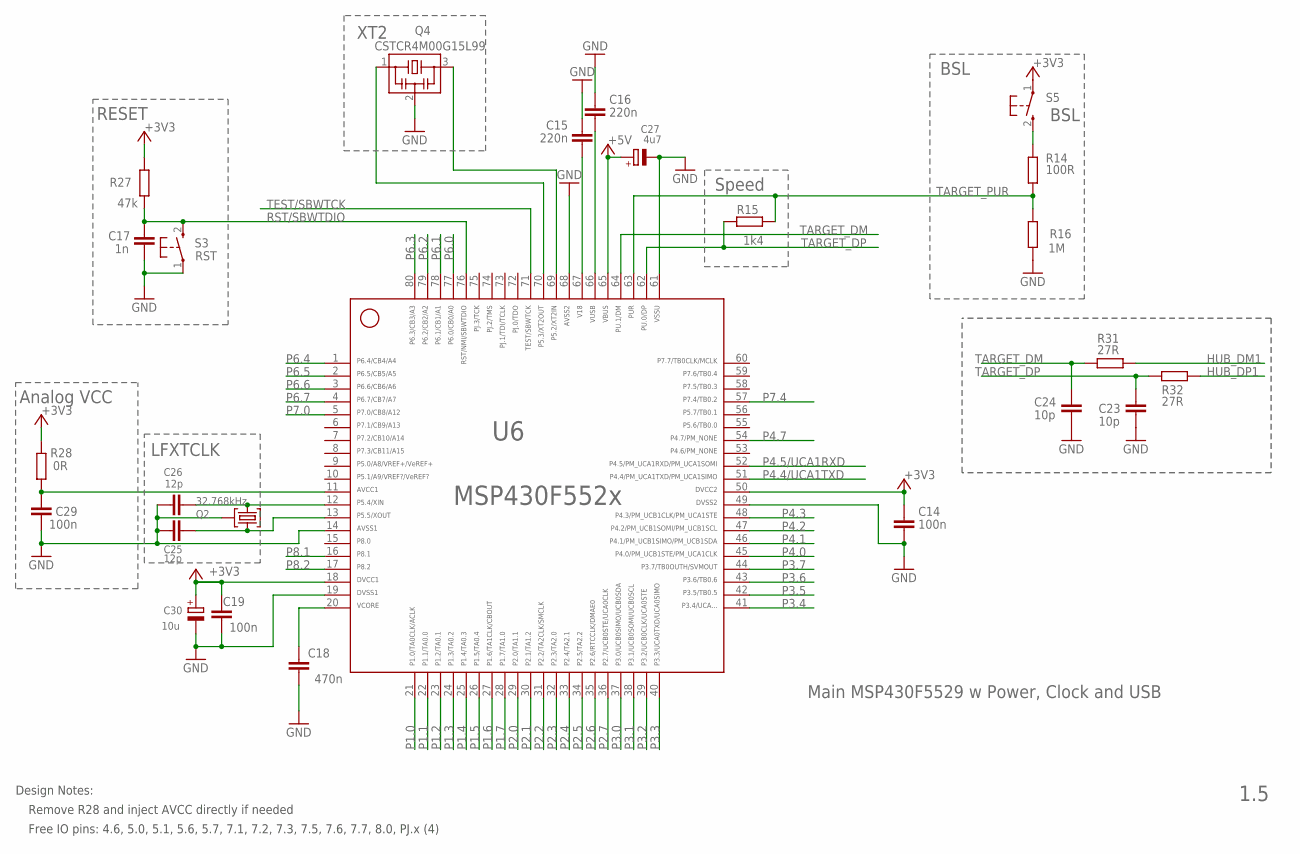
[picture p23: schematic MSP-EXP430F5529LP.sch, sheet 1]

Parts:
C14, C19, C29: 100n; C0402
C15, C16: 220n; C0402
C17: 1n; C0402
C18: 470n; C0402
C23, C24: 10p; C0402
C25, C26: 12p; C0402
C27: 4u7; A/3216-18R
C30: 10u; A/3216-18R
Q2: 32.768kHz; MS3V-T1R
Q4: CSTCR4M00G15L99; MURATA-FILTER_CSTCR
R14: 100R; R0402
R15: 1k4; R0402
R16: 1M; R0402
R27: 47k; R0402
R28: 0R; R0402
R31, R32: 27R; R0402
S3: RST; PBTH
S5: BSL; PBTH
U6: MSP430F5529IPNR; PN80

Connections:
+3V3: C14.1, C19.2, C30.+, R27.2, R28.2, S5.1, U6.18, U6.50; also elsewhere on the board
+5V: C27.+, U6.65; also elsewhere on the board
AVCC: C29.1, R28.1, U6.11
GND: C14.2, C15.2, C16.2, C17.2, C18.1, C19.1, C23.2, C24.2, C25.1, C26.1, C27.-, C29.2, C30.-, Q2.P3 (GND), Q4.2, R16.1, S3.1, U6.14, U6.19, U6.49, U6.61, U6.68; also elsewhere on the board
HUB_DM1: R31.1; also elsewhere on the board
HUB_DP1: R32.1; also elsewhere on the board
unnamed: R14.1, S5.2 (S)
P1.0: U6.21; also elsewhere on the board
P1.1: U6.22; also elsewhere on the board
P1.2: U6.23; also elsewhere on the board
P1.3: U6.24; also elsewhere on the board
P1.4: U6.25; also elsewhere on the board
P1.5: U6.26; also elsewhere on the board
P1.6: U6.27; also elsewhere on the board
P1.7: U6.28; also elsewhere on the board
P2.0: U6.29; also elsewhere on the board
P2.1: U6.30; also elsewhere on the board
P2.2: U6.31; also elsewhere on the board
P2.3: U6.32; also elsewhere on the board
P2.4: U6.33; also elsewhere on the board
P2.5: U6.34; also elsewhere on the board
P2.6: U6.35; also elsewhere on the board
P2.7: U6.36; also elsewhere on the board
P3.0: U6.37; also elsewhere on the board
P3.1: U6.38; also elsewhere on the board
P3.2: U6.39; also elsewhere on the board
P3.3: U6.40; also elsewhere on the board
P3.4: U6.41; also elsewhere on the board
P3.5: U6.42; also elsewhere on the board
P3.6: U6.43; also elsewhere on the board
P3.7: U6.44; also elsewhere on the board
P4.0: U6.45; also elsewhere on the board
P4.1: U6.46; also elsewhere on the board
P4.2: U6.47; also elsewhere on the board
P4.3: U6.48; also elsewhere on the board
P4.4/UCA1TXD: U6.51; also elsewhere on the board
P4.5/UCA1RXD: U6.52; also elsewhere on the board
P4.7: U6.54; also elsewhere on the board
P5.2/XT2IN: Q4.3, U6.69
P5.3/XT2OUT: Q4.1, U6.70
P5.4/XIN: C26.2, Q2.P2 (2), U6.12
P5.5/XOUT: C25.2, Q2.P1 (1), U6.13
P6.0: U6.77; also elsewhere on the board
P6.1: U6.78; also elsewhere on the board
P6.2: U6.79; also elsewhere on the board
P6.3: U6.80; also elsewhere on the board
P6.4: U6.1; also elsewhere on the board
P6.5: U6.2; also elsewhere on the board
P6.6: U6.3; also elsewhere on the board
P6.7: U6.4; also elsewhere on the board
P7.0: U6.5; also elsewhere on the board
P7.4: U6.57; also elsewhere on the board
P8.1: U6.16; also elsewhere on the board
P8.2: U6.17; also elsewhere on the board
RST/SBWTDIO: C17.1, R27.1, S3.2 (S), U6.76; also elsewhere on the board
TARGET_DM: C24.1, R31.2, U6.64
TARGET_DP: C23.1, R15.2, R32.2, U6.62
TARGET_PUR: R14.2, R15.1, R16.2, U6.63
TARGET_VUSB: C16.1, U6.66
TEST/SBWTCK: U6.71; also elsewhere on the board
V18: C15.1, U6.67
VCORE: C18.2, U6.20

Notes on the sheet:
RESET
LFXTCLK
XT2
Main MSP430F5529 w Power, Clock and USB
1.5
BSL
Speed
Analog VCC
Remove R28 and inject AVCC directly if needed
Design Notes:
Free IO pins: 4.6, 5.0, 5.1, 5.6, 5.7, 7.1, 7.2, 7.3, 7.5, 7.6, 7.7, 8.0, PJ.x (4)

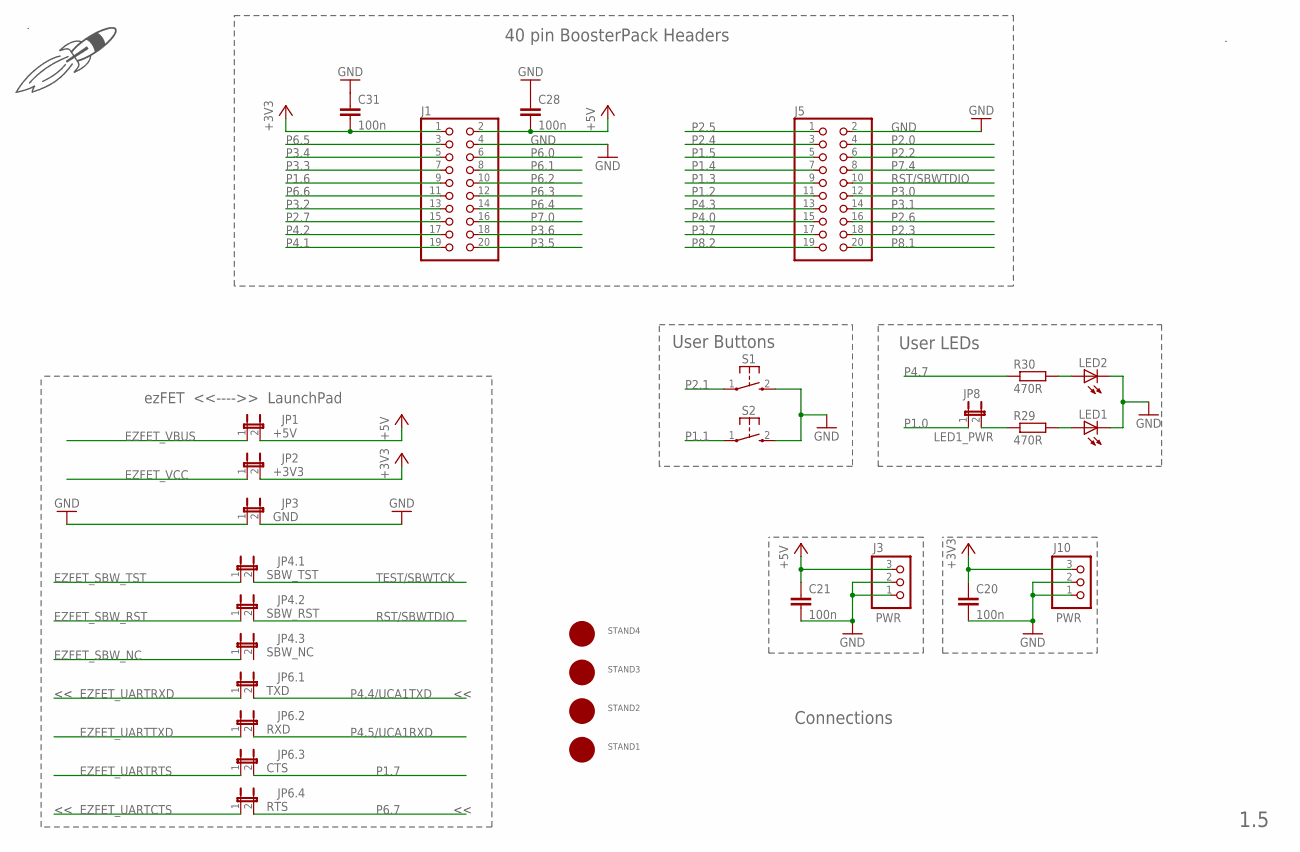
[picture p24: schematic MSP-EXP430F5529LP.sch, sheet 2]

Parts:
C20, C21, C28, C31: 100n; C0402
DRAW1: LOGO-ROCKET-20X13MM-SCH-S; LOGO-ROCKET-10X7MM-BRD
J1, J5: PINHD-2X10; 2X10
J3, J10: PWR; 1X03
JP1: +5V; JP1M
JP2: +3V3; JP1M
JP3: GND; JP1M
JP4.1: SBW_TST; JP1M
JP4.2: SBW_RST; JP1M
JP4.3: SBW_NC; JP1M
JP6.1: TXD; JP1M
JP6.2: RXD; JP1M
JP6.3: CTS; JP1M
JP6.4: RTS; JP1M
JP8: LED1_PWR; JP1
LED1, LED2: LEDCHIP-LED0603; CHIP-LED0603
R29, R30: 470R; R0402
S1, S2: PB; PBTH
STAND1, STAND2, STAND3, STAND4: MOUNT; MOUNTHOLE_110MIL
U$3: 5529_REAR_SILK_REV1_5_FINAL
U$4: MS_TM

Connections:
+3V3: C20.1, C31.2, J1.1, J10.3, JP2.2; also elsewhere on the board
+5V: C21.1, C28.2, J1.2, J3.3, JP1.2; also elsewhere on the board
EZFET_SBW_NC: JP4.3.1; also elsewhere on the board
EZFET_SBW_RST: JP4.2.1; also elsewhere on the board
EZFET_SBW_TST: JP4.1.1; also elsewhere on the board
EZFET_UARTCTS: JP6.4.1; also elsewhere on the board
EZFET_UARTRTS: JP6.3.1; also elsewhere on the board
EZFET_UARTRXD: JP6.1.1; also elsewhere on the board
EZFET_UARTTXD: JP6.2.1; also elsewhere on the board
EZFET_VBUS: JP1.1; also elsewhere on the board
EZFET_VCC: JP2.1; also elsewhere on the board
GND: C20.2, C21.2, C28.1, C31.1, J1.4, J3.1, J3.2, J5.2, J10.1, J10.2, JP3.1, JP3.2, LED1.C, LED2.C, S1.2 (S), S2.2 (S); also elsewhere on the board
unnamed: JP8.2, R29.1
unnamed: LED1.A, R29.2
unnamed: LED2.A, R30.2
P1.0: JP8.1; also elsewhere on the board
P1.1: S2.1; also elsewhere on the board
P1.2: J5.11; also elsewhere on the board
P1.3: J5.9; also elsewhere on the board
P1.4: J5.7; also elsewhere on the board
P1.5: J5.5; also elsewhere on the board
P1.6: J1.9; also elsewhere on the board
P1.7: JP6.3.2; also elsewhere on the board
P2.0: J5.4; also elsewhere on the board
P2.1: S1.1; also elsewhere on the board
P2.2: J5.6; also elsewhere on the board
P2.3: J5.18; also elsewhere on the board
P2.4: J5.3; also elsewhere on the board
P2.5: J5.1; also elsewhere on the board
P2.6: J5.16; also elsewhere on the board
P2.7: J1.15; also elsewhere on the board
P3.0: J5.12; also elsewhere on the board
P3.1: J5.14; also elsewhere on the board
P3.2: J1.13; also elsewhere on the board
P3.3: J1.7; also elsewhere on the board
P3.4: J1.5; also elsewhere on the board
P3.5: J1.20; also elsewhere on the board
P3.6: J1.18; also elsewhere on the board
P3.7: J5.17; also elsewhere on the board
P4.0: J5.15; also elsewhere on the board
P4.1: J1.19; also elsewhere on the board
P4.2: J1.17; also elsewhere on the board
P4.3: J5.13; also elsewhere on the board
P4.4/UCA1TXD: JP6.1.2; also elsewhere on the board
P4.5/UCA1RXD: JP6.2.2; also elsewhere on the board
P4.7: R30.1; also elsewhere on the board
P6.0: J1.6; also elsewhere on the board
P6.1: J1.8; also elsewhere on the board
P6.2: J1.10; also elsewhere on the board
P6.3: J1.12; also elsewhere on the board
P6.4: J1.14; also elsewhere on the board
P6.5: J1.3; also elsewhere on the board
P6.6: J1.11; also elsewhere on the board
P6.7: JP6.4.2; also elsewhere on the board
P7.0: J1.16; also elsewhere on the board
P7.4: J5.8; also elsewhere on the board
P8.1: J5.20; also elsewhere on the board
P8.2: J5.19; also elsewhere on the board
RST/SBWTDIO: J5.10, JP4.2.2; also elsewhere on the board
TEST/SBWTCK: JP4.1.2; also elsewhere on the board

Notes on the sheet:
40 pin BoosterPack Headers
Connections
1.5
User LEDs
User Buttons
ezFET <<---->> LaunchPad

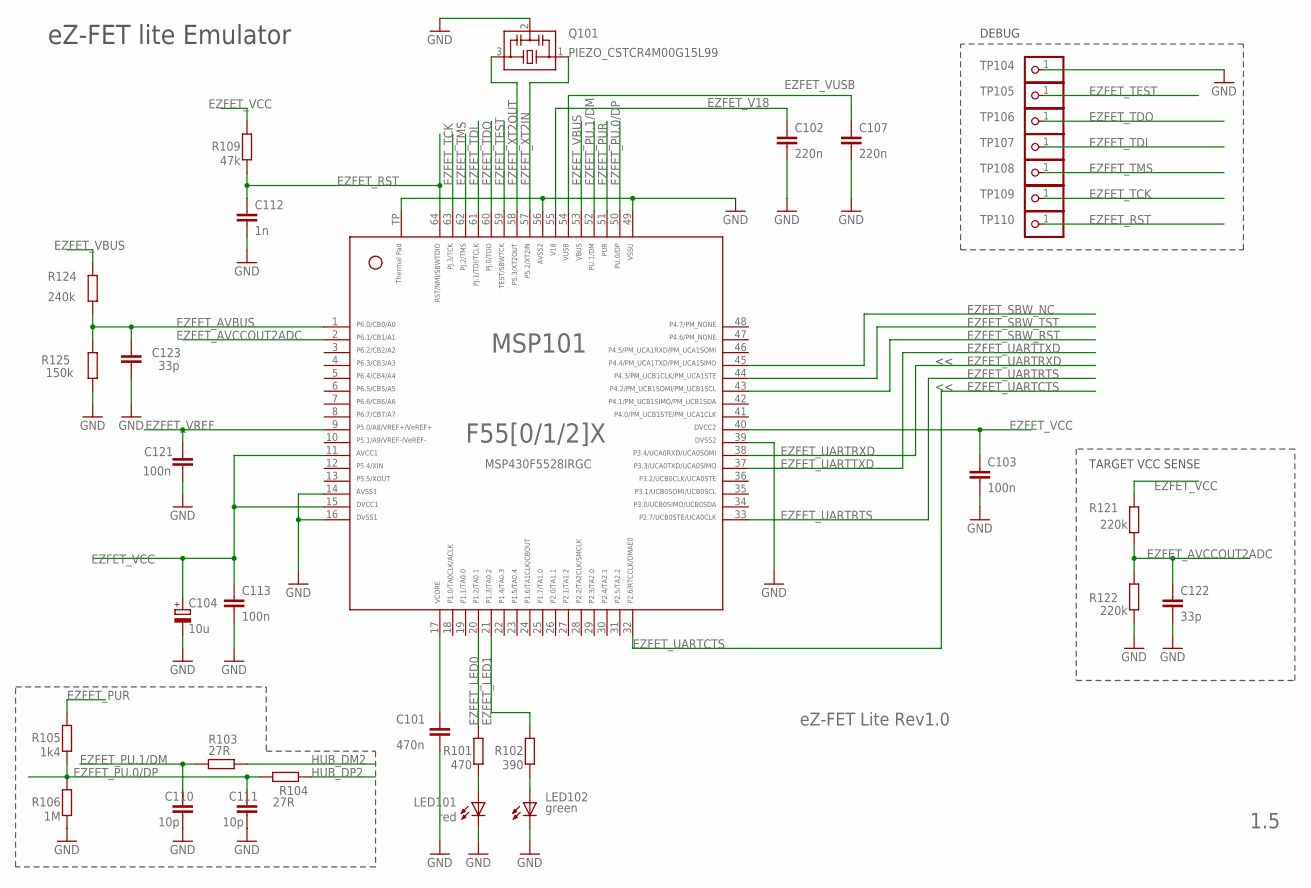
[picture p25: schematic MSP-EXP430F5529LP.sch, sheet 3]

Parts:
C101: 470n; C0402
C102, C107: 220n; C0402
C103, C113, C121: 100n; C0402
C104: 10u; A/3216-18R
C110, C111: 10p; C0402
C112: 1n; C0402
C122, C123: 33p; C0402
LED101: red; CHIP-LED0603
LED102: green; CHIP-LED0603
MSP101: MSP430F5528IRGC; RGC64
Q101: PIEZO_CSTCR4M00G15L99; MURATA-FILTER_CSTCR
R101: 470; R0402
R102: 390; R0402
R103, R104: 27R; R0402
R105: 1k4; R0402
R106: 1M; R0402
R109: 47k; R0402
R121, R122: 220k; R0402
R124: 240k; R0402
R125: 150k; R0402
TP104, TP105, TP106, TP107, TP108, TP109, TP110: TEST_PIN2; 1X01

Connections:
EZFET_AVBUS: C123.2, MSP101.1, R124.2, R125.1
EZFET_AVCCOUT2ADC: C122.2, MSP101.2, R121.2, R122.1
EZFET_LED0: MSP101.20, R101.2
EZFET_LED1: MSP101.21, R102.2
EZFET_PU.0/DP: C111.1, MSP101.50, R104.2, R105.1, R106.2
EZFET_PU.1/DM: C110.1, MSP101.52, R103.2
EZFET_PUR: MSP101.51, R105.2
EZFET_RST: C112.1, MSP101.64, R109.1, TP110.1
EZFET_SBW_NC: MSP101.45; also elsewhere on the board
EZFET_SBW_RST: MSP101.43; also elsewhere on the board
EZFET_SBW_TST: MSP101.44; also elsewhere on the board
EZFET_TCK: MSP101.63, TP109.1
EZFET_TDI: MSP101.61, TP107.1
EZFET_TDO: MSP101.60, TP106.1
EZFET_TEST: MSP101.59, TP105.1
EZFET_TMS: MSP101.62, TP108.1
EZFET_UARTCTS: MSP101.32; also elsewhere on the board
EZFET_UARTRTS: MSP101.33; also elsewhere on the board
EZFET_UARTRXD: MSP101.38; also elsewhere on the board
EZFET_UARTTXD: MSP101.37; also elsewhere on the board
EZFET_V18: C102.1, MSP101.55
EZFET_VBUS: MSP101.53, R124.1; also elsewhere on the board
EZFET_VCC: C103.1, C104.+, C113.1, MSP101.11, MSP101.15, MSP101.40, R109.2, R121.1; also elsewhere on the board
EZFET_VREF: C121.1, MSP101.9
EZFET_VUSB: C107.1, MSP101.54
EZFET_XT2IN: MSP101.57, Q101.1
EZFET_XT2OUT: MSP101.58, Q101.3
GND: C101.2, C102.2, C103.2, C104.-, C107.2, C110.2, C111.2, C112.2, C113.2, C121.2, C122.1, C123.1, LED101.C, LED102.C, MSP101.14, MSP101.16, MSP101.39, MSP101.49, MSP101.56, MSP101.TP, Q101.2, R106.1, R122.2, R125.2, TP104.1; also elsewhere on the board
HUB_DM2: R103.1; also elsewhere on the board
HUB_DP2: R104.1; also elsewhere on the board
unnamed: LED101.A, R101.1
unnamed: LED102.A, R102.1
unnamed: C101.1, MSP101.17

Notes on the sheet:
eZ-FET lite Emulator
MSP430F5528IRGC
TARGET VCC SENSE
eZ-FET Lite Rev1.0
1.5
DEBUG

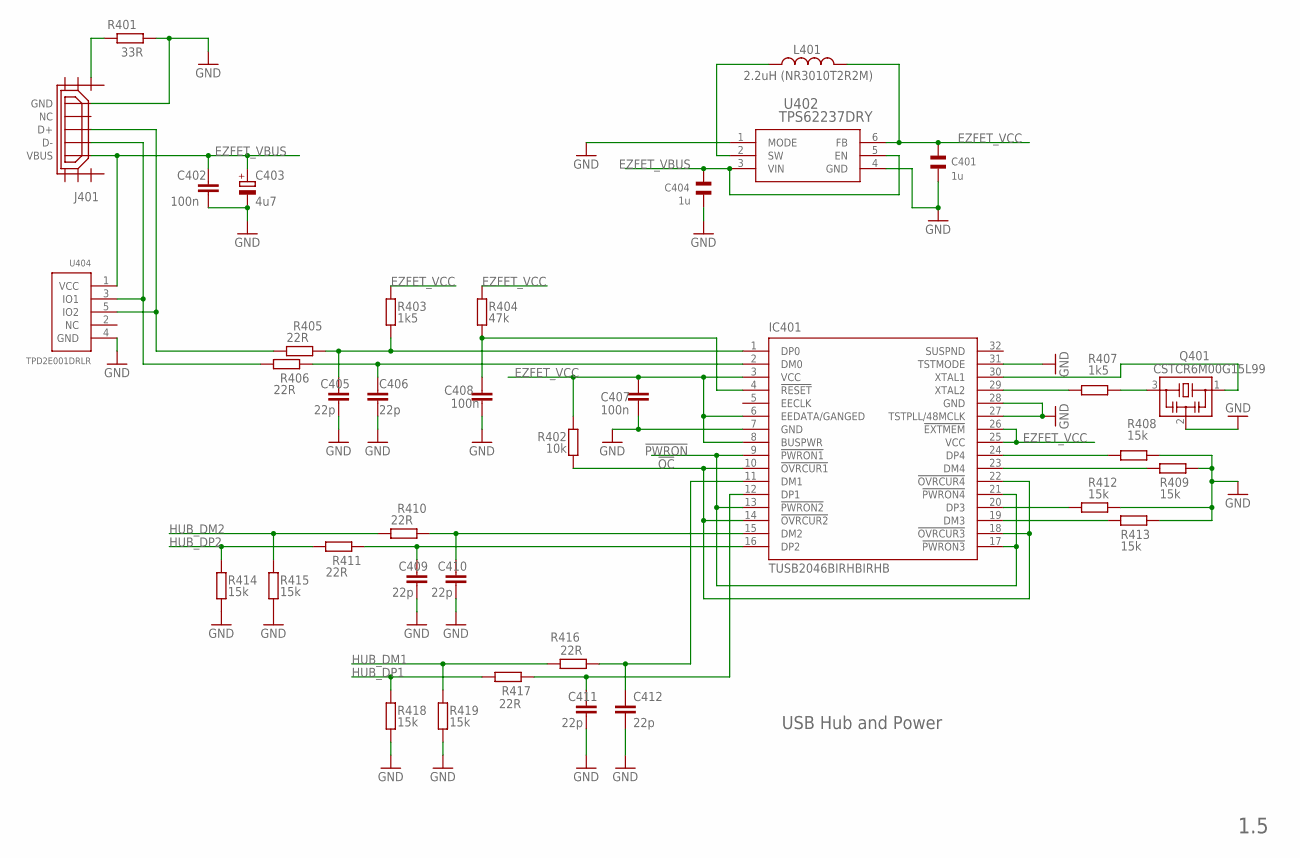
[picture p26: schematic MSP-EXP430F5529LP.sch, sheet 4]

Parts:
C401, C404: 1u; CSMD0805
C402, C407, C408: 100n; C0402
C403: 4u7; A/3216-18R
C405, C406, C409, C410, C411, C412: 22p; C0402
IC401: TUSB2046BIRHBIRHB; RHB_S-PQFP-N32
J401: USB_MICRO_FLIPPED; HIROSE-ZX62R-B-5P
L401: 2.2uH (NR3010T2R2M); L-NR3010
Q401: CSTCR6M00G15L99; MURATA-FILTER_CSTCR
R401: 33R; R0402
R402: 10k; R0402
R403, R407: 1k5; R0402
R404: 47k; R0402
R405, R406, R410, R411, R416, R417: 22R; R0402
R408, R409, R412, R413, R414, R415, R418, R419: 15k; R0402
U402: TPS62237DRY; DRY6
U404: TPD2E001DRLR; TPD2E001-DRL

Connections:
!OC: IC401.10 (!OVRCUR1), IC401.14 (!OVRCUR2), IC401.18 (!OVRCUR3), IC401.22 (!OVRCUR4), R402.2
!PWRON: IC401.9 (!PWRON1), IC401.13 (!PWRON2), IC401.17 (!PWRON3), IC401.21 (!PWRON4)
EZFET_VBUS: C402.1, C403.+, C404.2, J401.VBUS, U402.3 (VIN), U402.5 (EN), U404.1 (VCC); also elsewhere on the board
EZFET_VCC: C401.2, C407.1, IC401.3 (VCC), IC401.6 (EEDATA/GANGED), IC401.8 (BUSPWR), IC401.25 (VCC), IC401.26 (!EXTMEM), L401.P$2 (2), R402.1, R403.1, R404.1, U402.6 (FB); also elsewhere on the board
GND: C401.1, C402.2, C403.-, C404.1, C405.2, C406.2, C407.2, C408.2, C409.2, C410.2, C411.2, C412.2, IC401.7 (GND), IC401.27 (TSTPLL/48MCLK), IC401.28 (GND), IC401.31 (TSTMODE), J401.GND, Q401.2, R401.2, R408.1, R409.1, R412.1, R413.1, R414.2, R415.2, R418.2, R419.2, U402.1 (MODE), U402.4 (GND), U404.4 (GND); also elsewhere on the board
HUB_DM1: R416.2, R419.1; also elsewhere on the board
HUB_DM2: R410.2, R415.1; also elsewhere on the board
HUB_DP1: R417.2, R418.1; also elsewhere on the board
HUB_DP2: R411.2, R414.1; also elsewhere on the board
unnamed: C410.1, IC401.15 (DM2), R410.1
unnamed: C405.1, IC401.1 (DP0), R403.2, R405.1
unnamed: IC401.30 (XTAL1), Q401.1
unnamed: J401.SHIELD1, R401.1
unnamed: C406.1, IC401.2 (DM0), R406.1
unnamed: J401.D+, R405.2, U404.5 (IO2)
unnamed: J401.D-, R406.2, U404.3 (IO1)
unnamed: L401.P$1 (1), U402.2 (SW)
unnamed: IC401.29 (XTAL2), R407.2
unnamed: C412.1, IC401.11 (DM1), R416.1
unnamed: C411.1, IC401.12 (DP1), R417.1
unnamed: C409.1, IC401.16 (DP2), R411.1
unnamed: C408.1, IC401.4 (!RESET), R404.2
unnamed: IC401.20 (DP3), R412.2
unnamed: IC401.24 (DP4), R408.2
unnamed: IC401.23 (DM4), R409.2
unnamed: IC401.19 (DM3), R413.2
unnamed: Q401.3, R407.1

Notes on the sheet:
USB Hub and Power
1.5

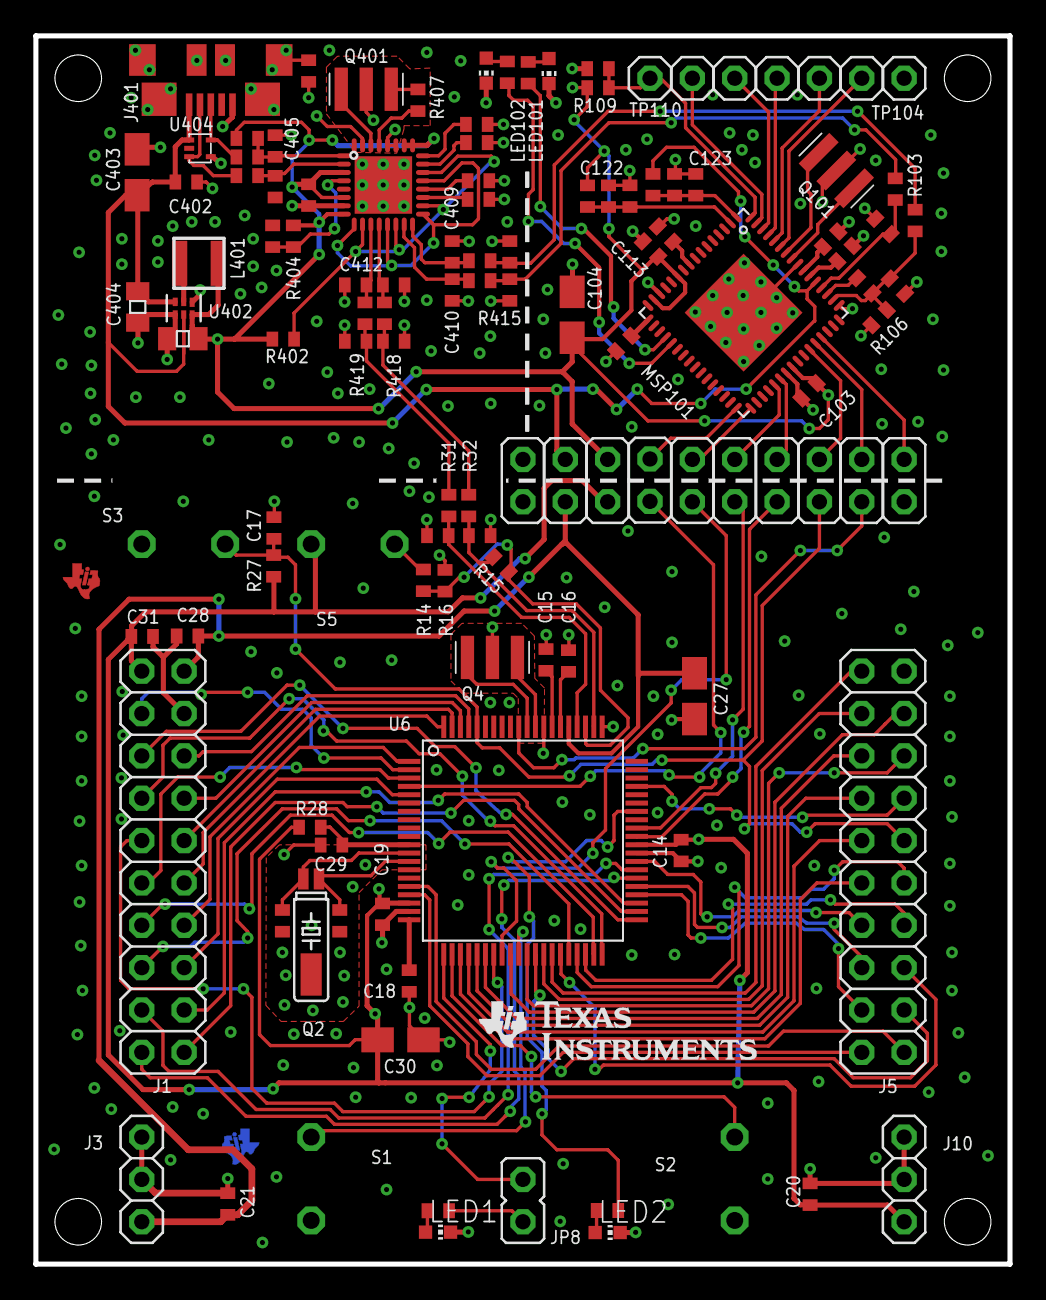
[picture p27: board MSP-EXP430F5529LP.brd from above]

Board: 2 copper layers, 58.4 x 73.7 mm, 132 parts (1 on the bottom side), 117 nets.

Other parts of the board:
DRAW2: LOGO-ROCKET-10X7MM-BRD
U$1: LOGO16_TPLACE
U$2, U$5: TILOGO_SMALL

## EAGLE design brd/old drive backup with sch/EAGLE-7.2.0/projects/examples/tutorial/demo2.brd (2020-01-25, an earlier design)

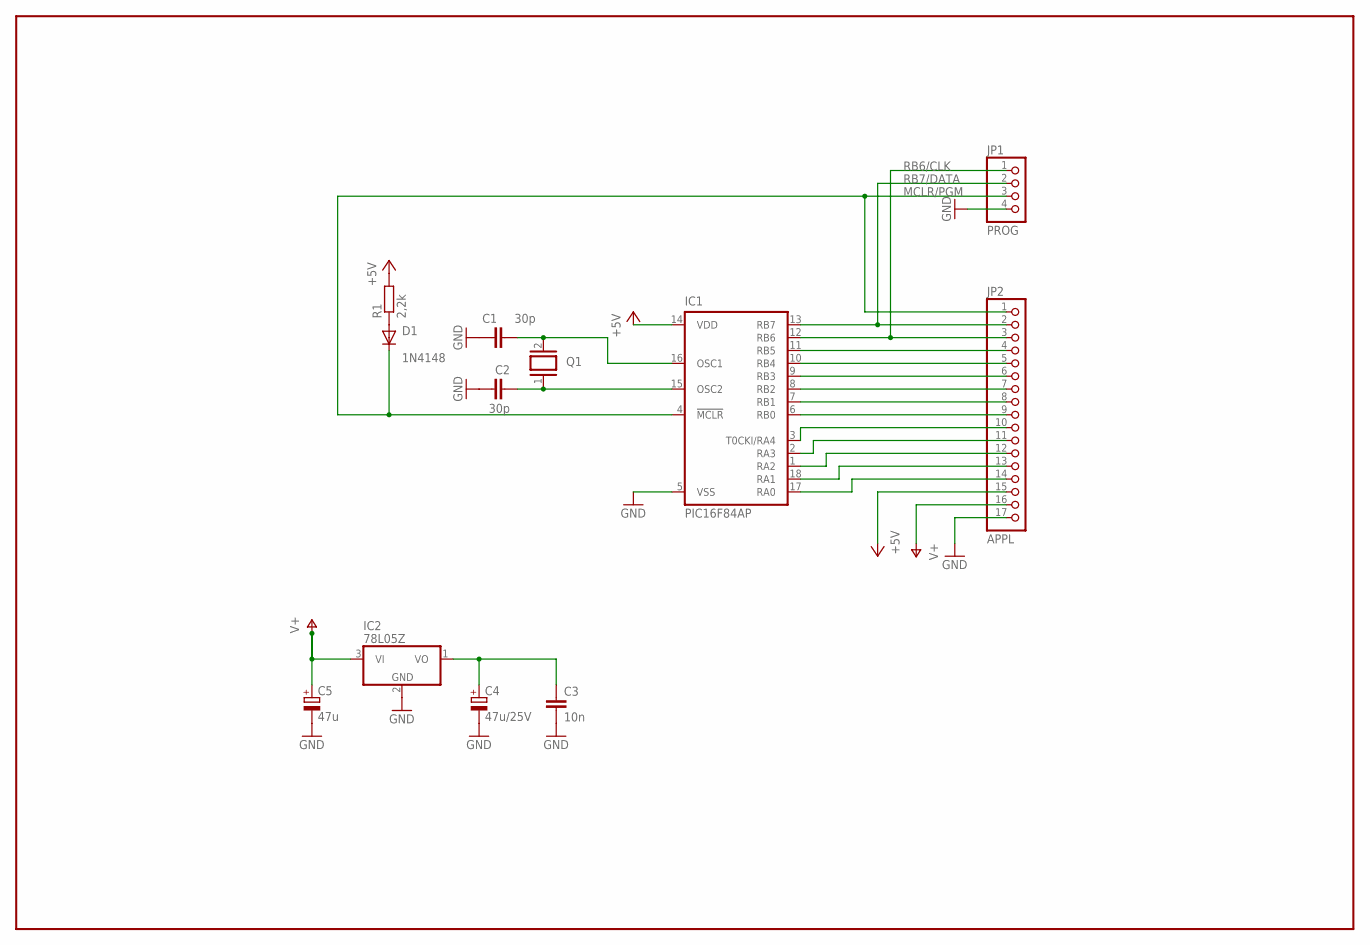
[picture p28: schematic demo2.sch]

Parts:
C1, C2: 30p; C1206
C3: 10n; C025-025X050
C4: 47u/25V; TAP5-45
C5: 47u; TAP5-45
D1: 1N4148; DO35-10
IC1: PIC16F84AP; DIL18
IC2: 78L05Z; TO92
JP1: PROG; 1X04
JP2: APPL; 1X17
Q1: XTAL/S; QS
R1: 2,2k; R1206

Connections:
+5V: IC1.14 (VDD), JP2.15, R1.1 (2)
GND: C1.1, C2.1, C3.2, C4.-, C5.-, IC1.5 (VSS), IC2.2 (GND), JP1.4, JP2.17
MCLR/PGM: D1.C, IC1.4 (!MCLR), JP1.3, JP2.1
unnamed: C3.1, C4.+, IC2.1 (VO)
unnamed: C1.2, IC1.16 (OSC1), Q1.2
unnamed: C2.2, IC1.15 (OSC2), Q1.1
unnamed: D1.A, R1.2 (1)
RA0: IC1.17 (RA0), JP2.14
RA1: IC1.18 (RA1), JP2.13
RA2: IC1.1 (RA2), JP2.12
RA3: IC1.2 (RA3), JP2.11
RA4: IC1.3 (T0CKI/RA4), JP2.10
RB0: IC1.6 (RB0), JP2.9
RB1: IC1.7 (RB1), JP2.8
RB2: IC1.8 (RB2), JP2.7
RB3: IC1.9 (RB3), JP2.6
RB4: IC1.10 (RB4), JP2.5
RB5: IC1.11 (RB5), JP2.4
RB6/CLK: IC1.12 (RB6), JP1.1, JP2.3
RB7/DATA: IC1.13 (RB7), JP1.2, JP2.2
V+: C5.+, IC2.3 (VI), JP2.16

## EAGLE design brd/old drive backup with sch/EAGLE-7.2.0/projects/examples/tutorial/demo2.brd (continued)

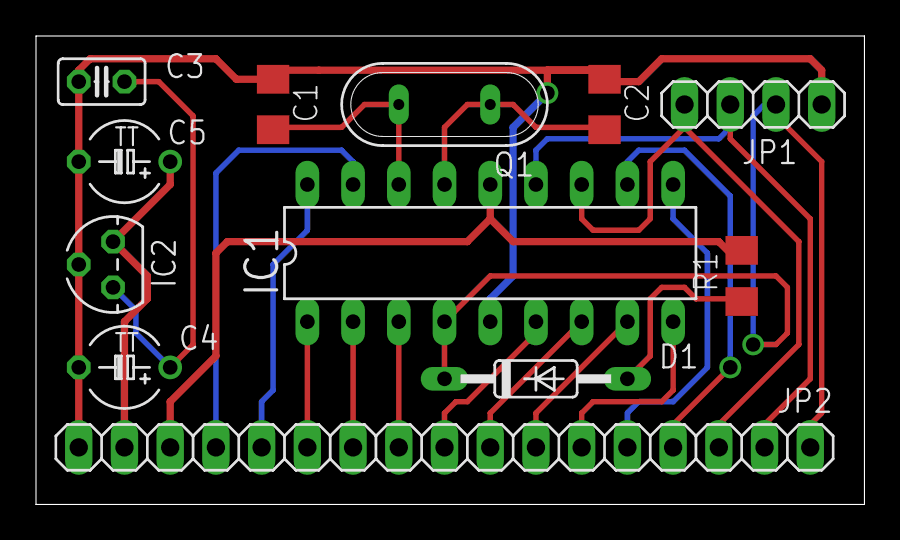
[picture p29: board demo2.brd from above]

Board: 2 copper layers, 46.0 x 26.0 mm, 12 parts (0 on the bottom side), 21 nets.

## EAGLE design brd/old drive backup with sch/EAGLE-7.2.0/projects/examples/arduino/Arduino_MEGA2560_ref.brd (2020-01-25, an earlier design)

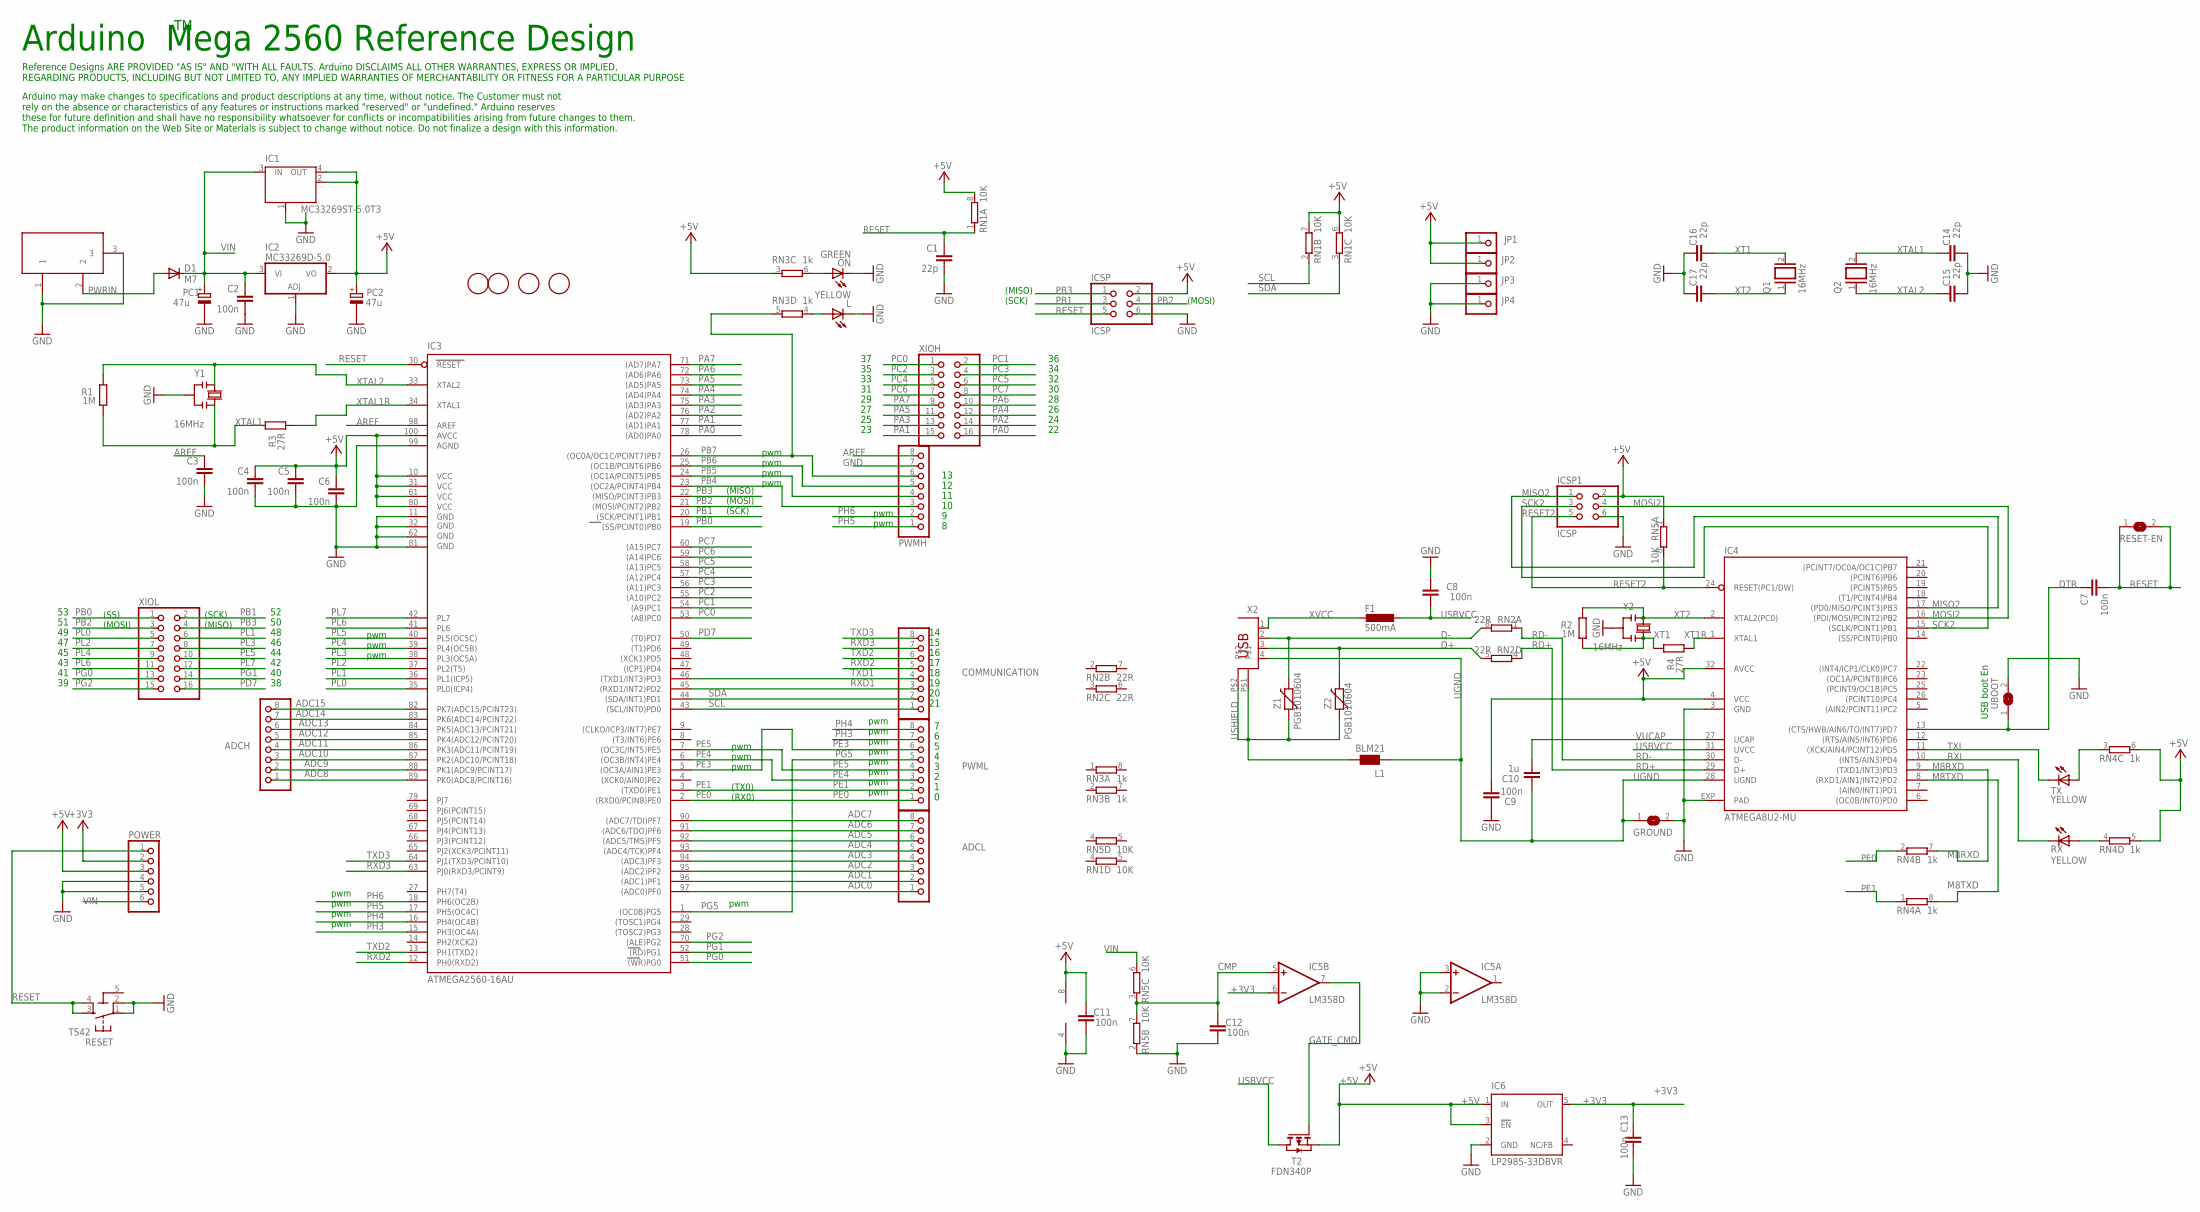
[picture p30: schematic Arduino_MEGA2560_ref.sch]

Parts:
ADCH: PINHD-1X8; 1X08
ADCL: PINHD-1X8; 1X08
C1, C14, C15, C16, C17: 22p; C0603-ROUND
C2, C3, C4, C5, C6, C7, C9, C12, C13: 100n; C0603-ROUND
C8, C11: 100n; C0603
C10: 1u; C0603-ROUND
COMMUNICATION: PINHD-1X8; 1X08
D1: M7; SMB
F1: 500mA; L1812
GROUND: SJ
IC1: MC33269ST-5.0T3; SOT223
IC2: MC33269D-5.0; DPACK
IC3: ATMEGA2560-16AU; TQFP100
IC4: ATMEGA8U2-MU; QFN32
IC5: LM358D; SO08
IC6: LP2985-33DBVR; SOT23-DBV
ICSP, ICSP1: ICSP; 2X03
JP1, JP2, JP3, JP4: PINHD-1X1; 1X01
L: YELLOW; CHIP-LED0805
L1: BLM21; 0805
ON: GREEN; CHIP-LED0805
PC1, PC2: 47u; PANASONIC_D
POWER: PINHD-1X6; 1X06
PWMH: PINHD-1X8; 1X08
PWML: PINHD-1X8; 1X08
Q1, Q2: 16MHz; QS
R1, R2: 1M; R0603-ROUND
R3, R4: 27R; R0603-ROUND
RESET: TS42
RESET-EN: SJ
RN1, RN5: 10K; CAT16
RN2: 22R; CAY16
RN3, RN4: 1k; CAY16
RX: YELLOW; CHIP-LED0805
T2: FDN340P; SOT-23
TX: YELLOW; CHIP-LED0805
U$2, U$3, U$4, U$5: FIDUCIALMOUNT; FIDUCIA-MOUNT
UBOOT: SJ
X1: DC21MMX; DC-21MM
X2: PN61729
XIOH: PINHD-2X8; 2X08
XIOL: PINHD-2X8; 2X08
Y1, Y2: 16MHz; RESONATOR
Z1, Z2: PGB1010604; CT/CN0603

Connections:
5-GND: RESET.5 (5-GND)
+3V3: C13.2, IC5.6 (-IN), IC6.5 (OUT), POWER.2
+5V: C4.1, C5.1, C6.1, C9.1, C11.2, IC1.2 (OUT), IC1.4 (OUT), IC2.2 (VO), IC3.10 (VCC), IC3.31 (VCC1), IC3.61 (VCC2), IC3.80 (VCC3), IC3.100 (AVCC), IC4.4 (VCC), IC4.32 (AVCC), IC5.8 (V+), IC6.1 (IN), IC6.3 (!EN), ICSP.2, ICSP1.2, JP1.1, JP2.1, PC2.+, POWER.3, RN1.6 (2), RN1.7 (2), RN1.8 (2), RN3.3 (1), RN4.5 (2), RN4.6 (2), RN5.1, T2.2 (S)
ADC0: ADCL.1, IC3.97 ((ADC0)PF0)
ADC1: ADCL.2, IC3.96 ((ADC1)PF1)
ADC2: ADCL.3, IC3.95 ((ADC2)PF2)
ADC3: ADCL.4, IC3.94 ((ADC3)PF3)
ADC4: ADCL.5, IC3.93 ((ADC4/TCK)PF4)
ADC5: ADCL.6, IC3.92 ((ADC5/TMS)PF5)
ADC6: ADCL.7, IC3.91 ((ADC6/TDO)PF6)
ADC7: ADCL.8, IC3.90 ((ADC7/TDI)PF7)
ADC8: ADCH.1, IC3.89 (PK0(ADC8/PCINT16))
ADC9: ADCH.2, IC3.88 (PK1(ADC9/PCINT17))
ADC10: ADCH.3, IC3.87 (PK2(ADC10/PCINT18))
ADC11: ADCH.4, IC3.86 (PK3(ADC11/PCINT19))
ADC12: ADCH.5, IC3.85 (PK4(ADC12/PCINT20))
ADC13: ADCH.6, IC3.84 (PK5(ADC13/PCINT21))
ADC14: ADCH.7, IC3.83 (PK6(ADC14/PCINT22))
ADC15: ADCH.8, IC3.82 (PK7(ADC15/PCINT23))
AREF: C3.1, IC3.98 (AREF), PWMH.8
CMP: C12.2, IC5.5 (+IN), RN5.3 (1), RN5.7 (2)
D+: RN2.5 (2), X2.3, Z2.2
D-: RN2.8 (2), X2.2, Z1.2
DTR: C7.1, IC4.13 ((CTS/HWB/AIN6/TO/INT7)PD7), UBOOT.1
GATE_CMD: IC5.7 (OUT), T2.3 (G)
GND: C1.2, C2.2, C3.2, C4.2, C5.2, C6.2, C8.2, C9.2, C11.1, C12.1, C13.1, C14.1, C15.1, C16.2, C17.2, GROUND.2, IC1.1 (GND/ADJ), IC2.1 (ADJ), IC3.11 (GND), IC3.32 (GND1), IC3.62 (GND2), IC3.81 (GND3), IC3.99 (AGND), IC4.3 (GND), IC4.EXP (PAD), IC5.2 (-IN), IC5.3 (+IN), IC5.4 (V-), IC6.2 (GND), ICSP.6, ICSP1.6, JP3.1, JP4.1, L.C, ON.C, PC1.-, PC2.-, POWER.4, POWER.5, PWMH.7, RESET.1, RESET.2, RN5.2 (1), UBOOT.2, X1.1, X1.3, Y1.2, Y2.2
M8RXD: IC4.9 ((TXD1/INT3)PD3), RN4.7 (2)
M8TXD: IC4.8 ((RXD1/AIN1/INT2)PD2), RN4.8 (2)
MISO2: IC4.17 ((PD0/MISO/PCINT3)PB3), ICSP1.1
MOSI2: IC4.16 ((PDI/MOSI/PCINT2)PB2), ICSP1.4
unnamed: L.A, RN3.4 (1)
unnamed: ON.A, RN3.6 (2)
unnamed: RN4.4 (1), RX.A
unnamed: RN4.3 (1), TX.A
PA0: IC3.78 ((AD0)PA0), XIOH.16
PA1: IC3.77 ((AD1)PA1), XIOH.15
PA2: IC3.76 ((AD2)PA2), XIOH.14
PA3: IC3.75 ((AD3)PA3), XIOH.13
PA4: IC3.74 ((AD4)PA4), XIOH.12
PA5: IC3.73 ((AD5)PA5), XIOH.11
PA6: IC3.72 ((AD6)PA6), XIOH.10
PA7: IC3.71 ((AD7)PA7), XIOH.9
PB0: IC3.19 ((SS/PCINT0)PB0), XIOL.1
PB1: IC3.20 ((SCK/PCINT1)PB1), ICSP.3, XIOL.2
PB2: IC3.21 ((MOSI/PCINT2)PB2), ICSP.4, XIOL.3
PB3: IC3.22 ((MISO/PCINT3)PB3), ICSP.1, XIOL.4
PB4: IC3.23 ((OC2A/PCINT4)PB4), PWMH.3
PB5: IC3.24 ((OC1A/PCINT5)PB5), PWMH.4
PB6: IC3.25 ((OC1B/PCINT6)PB6), PWMH.5
PB7: IC3.26 ((OC0A/OC1C/PCINT7)PB7), PWMH.6, RN3.5 (2)
PC0: IC3.53 ((A8)PC0), XIOH.1
PC1: IC3.54 ((A9)PC1), XIOH.2
PC2: IC3.55 ((A10)PC2), XIOH.3
PC3: IC3.56 ((A11)PC3), XIOH.4
PC4: IC3.57 ((A12)PC4), XIOH.5
PC5: IC3.58 ((A13)PC5), XIOH.6
PC6: IC3.59 ((A14)PC6), XIOH.7
PC7: IC3.60 ((A15)PC7), XIOH.8
PD7: IC3.50 ((T0)PD7), XIOL.16
PE0: IC3.2 ((RXD0/PCIN8)PE0), PWML.1, RN4.2 (1)
PE1: IC3.3 ((TXD0)PE1), PWML.2, RN4.1
PE3: IC3.5 ((OC3A/AIN1)PE3), PWML.6
PE4: IC3.6 ((OC3B/INT4)PE4), PWML.3
PE5: IC3.7 ((OC3C/INT5)PE5), PWML.4
PG0: IC3.51 ((WR)PG0), XIOL.13
PG1: IC3.52 ((RD)PG1), XIOL.14
PG2: IC3.70 ((ALE)PG2), XIOL.15
PG5: IC3.1 ((OC0B)PG5), PWML.5
PH3: IC3.15 (PH3(OC4A)), PWML.7
PH4: IC3.16 (PH4(OC4B)), PWML.8
PH5: IC3.17 (PH5(OC4C)), PWMH.1
PH6: IC3.18 (PH6(OC2B)), PWMH.2
PL0: IC3.35 (PL0(ICP4)), XIOL.5
PL1: IC3.36 (PL1(ICP5)), XIOL.6
PL2: IC3.37 (PL2(T5)), XIOL.7
PL3: IC3.38 (PL3(OC5A)), XIOL.8
PL4: IC3.39 (PL4(OC5B)), XIOL.9
PL5: IC3.40 (PL5(OC5C)), XIOL.10
PL6: IC3.41 (PL6), XIOL.11
PL7: IC3.42 (PL7), XIOL.12
PWRIN: D1.A, X1.2
RD+: IC4.29 (D+), RN2.4 (1)
RD-: IC4.30 (D-), RN2.1
RESET: C1.1, C7.2, IC3.30 (RESET), ICSP.5, POWER.1, RESET.3, RESET.4, RESET-EN.1, RESET-EN.2, RN1.1
RESET2: IC4.24 (RESET(PC1/DW)), ICSP1.5, RN5.8 (2)
RXD1: COMMUNICATION.3, IC3.45 ((RXD1/INT2)PD2)
RXD2: COMMUNICATION.5, IC3.12 (PH0(RXD2))
RXD3: COMMUNICATION.7, IC3.63 (PJ0(RXD3/PCINT9))
RXL: IC4.10 ((INT5/AIN3)PD4), RX.C
SCK2: IC4.15 ((SCLK/PCINT1)PB1), ICSP1.3
SCL: COMMUNICATION.1, IC3.43 ((SCL/INT0)PD0), RN1.2 (1)
SDA: COMMUNICATION.2, IC3.44 ((SDA/INT1)PD1), RN1.3 (1)
TXD1: COMMUNICATION.4, IC3.46 ((TXD1/INT3)PD3)
TXD2: COMMUNICATION.6, IC3.13 (PH1(TXD2))
TXD3: COMMUNICATION.8, IC3.64 (PJ1(TXD3/PCINT10))
TXL: IC4.11 ((XCK/AIN4/PCINT12)PD5), TX.C
UGND: C10.2, GROUND.1, IC4.28 (UGND), L1.1, X2.4
USBVCC: C8.1, F1.1, IC4.31 (UVCC), T2.1 (D)
USHIELD: L1.2, X2.P$1, X2.P$2, Z1.1, Z2.1
VIN: C2.1, D1.C, IC1.3 (IN), IC2.3 (VI), PC1.+, POWER.6, RN5.6 (2)
VUCAP: C10.1, IC4.27 (UCAP)
XT1: C16.1, Q1.2, R2.1, R4.2, Y2.3
XT1R: IC4.1 (XTAL1), R4.1
XT2: C17.1, IC4.2 (XTAL2(PC0)), Q1.1, R2.2, Y2.1
XTAL1: C14.2, Q2.2, R1.1, R3.2, Y1.3
XTAL1R: IC3.34 (XTAL1), R3.1
XTAL2: C15.2, IC3.33 (XTAL2), Q2.1, R1.2, Y1.1
XVCC: F1.2, X2.1

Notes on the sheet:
(SCK)
(MISO)
(MOSI)
pwm
(TX0)
(RX0)
(SS)
USB boot En
Arduino Mega 2560 Reference Design
Arduino may make changes to specifications and product descriptions at any time, without notice. The Customer must not rely on the absence or characteristics of any features or instructions marked "reserved" or "undefined." Arduino reserves these for future definition and shall have no responsibili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
Reference Designs ARE PROVIDED "AS IS" AND "WITH ALL FAULTS. Arduino DISCLAIMS ALL OTHER WARRANTIES, EXPRESS OR IMPLIED, REGARDING PRODUCTS, INCLUDING BUT NOT LIMITED TO, ANY IMPLIED WARRANTIES OF MERCHANTABILITY OR FITNESS FOR A PARTICULAR PURPOSE

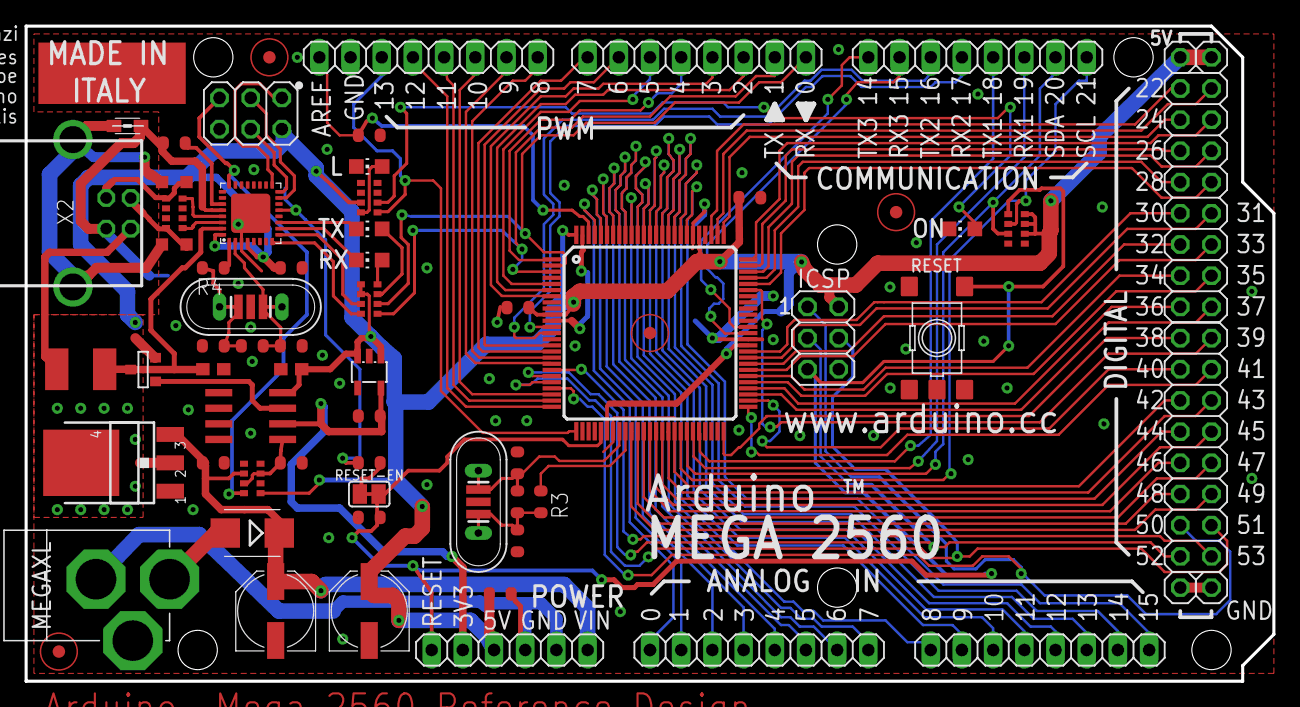
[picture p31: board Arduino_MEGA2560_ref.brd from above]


Board: 2 copper layers, 101.6 x 53.3 mm, 72 parts (2 on the bottom side), 107 nets.

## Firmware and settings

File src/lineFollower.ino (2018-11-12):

/*
  //  LINE FOLLOWER ROBOT BY TOMASZ JAKUBOWSKI  [2017-2018]
  //  FUSEBIT SETTINGS FOR AVRDUDE (8MHZ INTERNAL CLOCK): -U lfuse:w:0xe2:m -U hfuse:w:0xd9:m
  //  SET BOARD AS PURE AVR ATMEGA CHIP WITH 8MHZ CLOCK
  //  BE AWARE THAT SERIAL IS OCCUPIED BY BUTTON(TX) AND LED(RX)
  //  PROGRAMMING DONE BY USBASP THROUGH ISP INTERFACE
*/

#include <PID_v1.h>
#include "motors.h"

int lineSide = 0;
int lastCentroid = 25;

int getCentroid(int minimalMass, int criticalMass)   //calculate the line position using mass/torque relation analogy //returns values 0-50, and -1 if it sees only black
{
  int sensorReadings[6];
  int mass = 0;
  int torque = 0;

  sensorReadings[0] = analogRead(PHOTO_1);
  sensorReadings[1] = analogRead(PHOTO_2);
  sensorReadings[2] = analogRead(PHOTO_3);
  sensorReadings[3] = analogRead(PHOTO_4);
  sensorReadings[4] = analogRead(PHOTO_5);
  sensorReadings[5] = analogRead(PHOTO_6);

  for (int i = 0; i < 6; i++)
  {
    int reading = sensorReadings[i] / 32;
    mass += reading;
    torque += reading * (i + 1);
  }

  if (lastCentroid < 15)       lineSide = -1;
  else if (lastCentroid > 35) lineSide = 1;
  else lineSide = 0;

  if (mass < minimalMass)
  {
    if (lineSide == -1) return 0;
    else if(lineSide == 0) return 25;
    else return 50;
  }

  else if (mass > criticalMass)  return -1;

  else
  {
    lastCentroid = torque * 10 / mass - 10;
    return lastCentroid;
  }

}

double centroid = 25;
double setpoint = 25;
double wheel = 25;
Motors motors;
PID drivingPID(&centroid, &wheel, &setpoint, 3.0 , 0.0, 0.05 , REVERSE);

void setup()
{
  //UCSR0B &= ~((1 << RXEN0) | (1 << TXEN0)); //DISABLE UART
  Serial.begin(38400);
  motors.drive(0, 25);

  drivingPID.SetSampleTime(1);
  drivingPID.SetMode(AUTOMATIC);

  delay(1000);
}

void loop()
{
  centroid = (double)getCentroid(10, 150);

  if (centroid != -1)
  {
    drivingPID.Compute();
    motors.drive(16, wheel);
  }
  else
  {
    motors.brake();
  }
}

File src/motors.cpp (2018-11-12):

#include "motors.h"

Motors::Motors():
  rightMotor(ENABLE_A, MOTOR_1, MOTOR_2),
  leftMotor(ENABLE_B, MOTOR_3, MOTOR_4)
{
  pinMode(PHOTO_1, INPUT);
  pinMode(PHOTO_2, INPUT);
  pinMode(PHOTO_3, INPUT);
  pinMode(PHOTO_4, INPUT);
  pinMode(PHOTO_5, INPUT);
  pinMode(PHOTO_6, INPUT);
  pinMode(BUTTON, INPUT);

  pinMode(MOTOR_1, OUTPUT);
  pinMode(MOTOR_2, OUTPUT);
  pinMode(MOTOR_3, OUTPUT);
  pinMode(MOTOR_4, OUTPUT);
  pinMode(ENABLE_A, OUTPUT);
  pinMode(ENABLE_B, OUTPUT);
  pinMode(LED_LIGHT, OUTPUT);
}

int Motors::multiMap(int val, int* _in, int* _out, uint8_t size)
{
  // note: the _in array should have increasing values

  // take care the value is within range
  // val = constrain(val, _in[0], _in[size-1]);
  if (val <= _in[0]) return _out[0];
  if (val >= _in[size - 1]) return _out[size - 1];

  // search right interval
  uint8_t pos = 1;  // _in[0] allready tested
  while (val > _in[pos]) pos++;

  // this will handle all exact "points" in the _in array
  if (val == _in[pos]) return _out[pos];

  // interpolate in the right segment for the rest
  return (val - _in[pos - 1]) * (_out[pos] - _out[pos - 1]) / (_in[pos] - _in[pos - 1]) + _out[pos - 1];
}

void Motors::move(int left, int right)  //-70 +70
{
  isStopped = 0;
  
  bool leftDir = 0;
  bool rightDir = 0;
  if (left >= 0) leftDir = 1;
  if (right >= 0) rightDir = 1;
  left = abs(left);
  right = abs(right);
  left = multiMap(left, motorInput, motorOutput, 8);
  right = multiMap(right, motorInput, motorOutput, 8);

  rightMotor.setSpeed(right);
  leftMotor.setSpeed(left);
  leftSpeed = left;
  rightSpeed = right;
  if (leftDir)  leftMotor.forward();
  if (!leftDir) leftMotor.backward();
  if (rightDir) rightMotor.backward();
  if (!rightDir)rightMotor.forward();
}

void Motors::drive(int _speed, int _wheel)
{
  _wheel = constrain(_wheel, 0, 50);
  _wheel -= 25;
  _speed = constrain(_speed, -70, 70);
  move(_speed + _wheel, _speed - _wheel);
}

void Motors::brake()
{
  if (isStopped == 0)
  {
    move(-leftSpeed*1.2, -rightSpeed*1.2);
    delay(50);
    move(0, 0);
    delay(600);
  }
  isStopped = 1;
}

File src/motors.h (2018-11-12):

#ifndef MOTORS_H
#define MOTORS_H

///A0 and A7 Are SHORTED (BAD SOLDERING JOB)
#define PHOTO_1 PC5
#define PHOTO_2 PC4
#define PHOTO_3 PC3
#define PHOTO_4 PC2
#define PHOTO_5 PC1
#define PHOTO_6 PC0
#define BUTTON  PD1
#define MOTOR_1 PD7
#define MOTOR_2 8 //for some reason PB0 PB1 and PB2 didnt work
#define MOTOR_3 9
#define MOTOR_4 10
#define ENABLE_A  PD6
#define ENABLE_B  PD5
#define LED_LIGHT PD0

#include <L298N.h>

const int motorInput[]  = {0, 10, 20, 30, 40, 50, 60, 70};
const int motorOutput[] = {0, 20, 27, 35, 46, 61, 123, 255};

class Motors
{
  private:
    int leftSpeed = 0;
    int rightSpeed = 0;
    bool isStopped = 0;
    
    L298N rightMotor;
    L298N leftMotor;
    int multiMap(int val, int* _in, int* _out, uint8_t size);
    void move(int left, int right);   //-70 +70
    
  public:
    Motors();
    void drive(int _speed, int _wheel);///0-255, 0-50
    void brake();
};

#endif  //MOTORS_H

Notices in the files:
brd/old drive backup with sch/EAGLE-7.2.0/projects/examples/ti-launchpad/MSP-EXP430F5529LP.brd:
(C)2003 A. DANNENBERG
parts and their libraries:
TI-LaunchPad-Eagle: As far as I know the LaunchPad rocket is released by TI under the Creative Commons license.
